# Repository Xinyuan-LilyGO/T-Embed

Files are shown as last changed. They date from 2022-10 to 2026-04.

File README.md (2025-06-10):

<h1 align = "center">🌟LilyGo T-Embed🌟</h1>



## News

- **CC1101 Shield Description**
  - If a CC1101 shield is added to the Embed, the microphone will not be enabled. This is determined by the hardware design and cannot be avoided.

# Introduce

An ESP32S3 development board that can freely use WIFI, BLE, TF, LED, TFT_LCD functions.

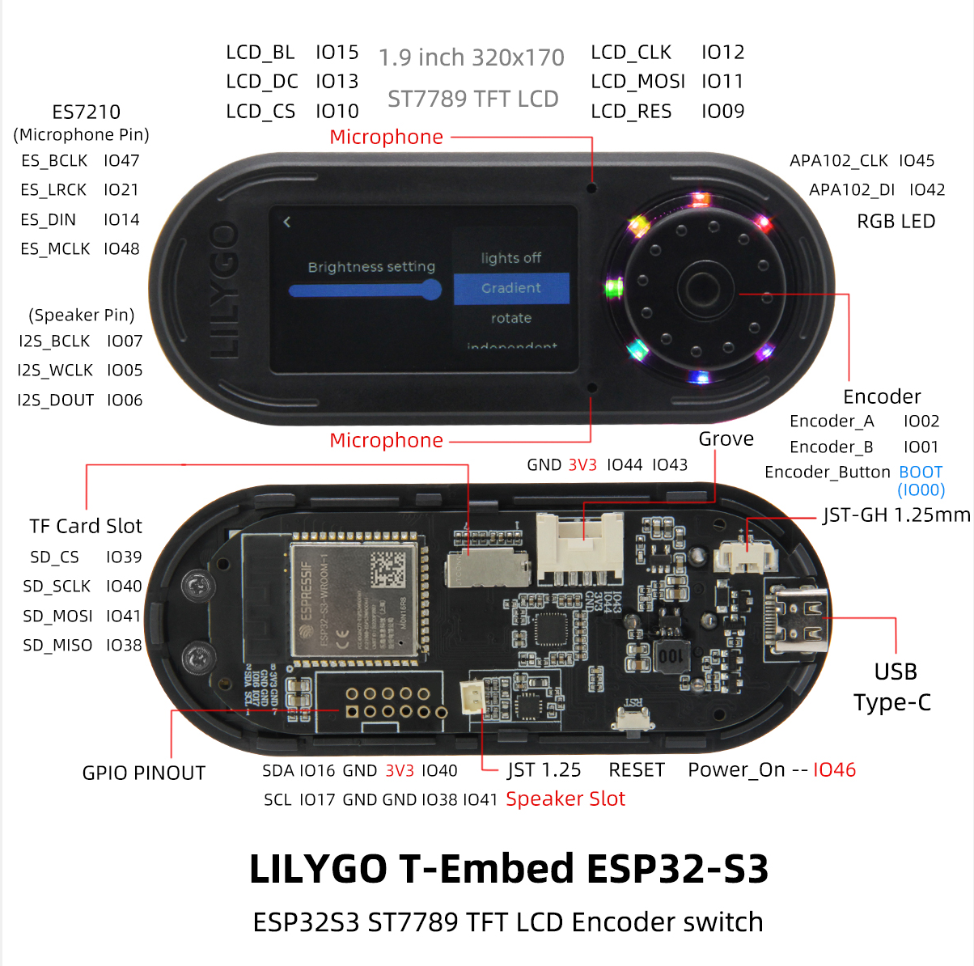
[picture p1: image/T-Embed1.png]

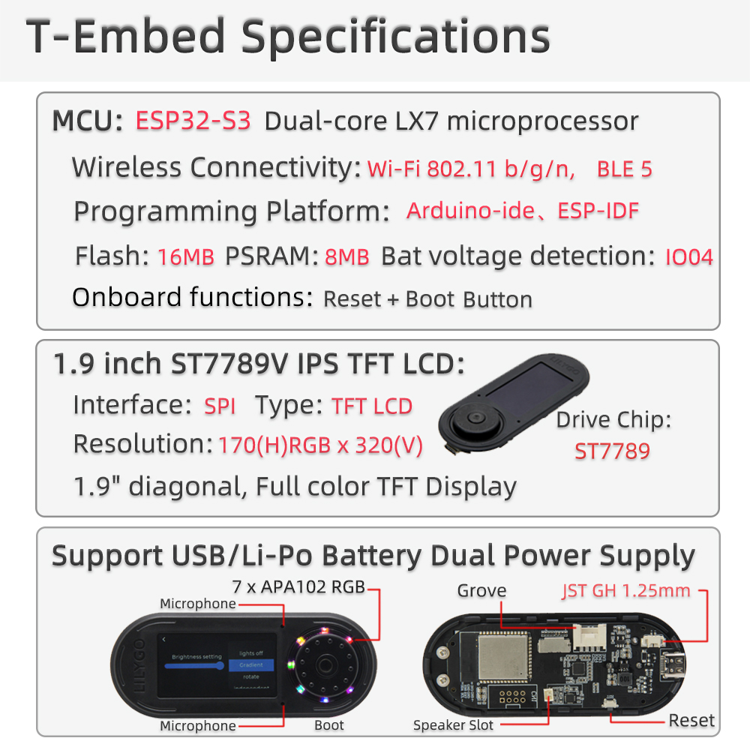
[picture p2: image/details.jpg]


## Product 📷

| Product |  Product Link  |
| :-----: | :---: |
| T-Embed | [LilyGo](https://www.lilygo.cc/products/t-embed) |

# Quick Start
## Arduino 
> Arduino:
> In Arduino Preferences, on the Settings tab, enter the `https://raw.githubusercontent.com/espressif/arduino-esp32/gh-pages/package_esp32_index.json` URL in the `Additional boards manager URLs` input box. **Please pay attention to the version. The test phase is using 2.0.14. It is not certain that versions above 2.0.14 can run. When the operation is abnormal, please downgrade to a version below 2.0.14.** , As of 2024/08/02, TFT_eSPI does not work on versions higher than 2.0.14, see [TFT_eSPI/issue3329](https://github.com/Bodmer/TFT_eSPI/issues/3329)
>- Search for ESP32 in Tools->Board Manager and install ESP32-Arduino SDK
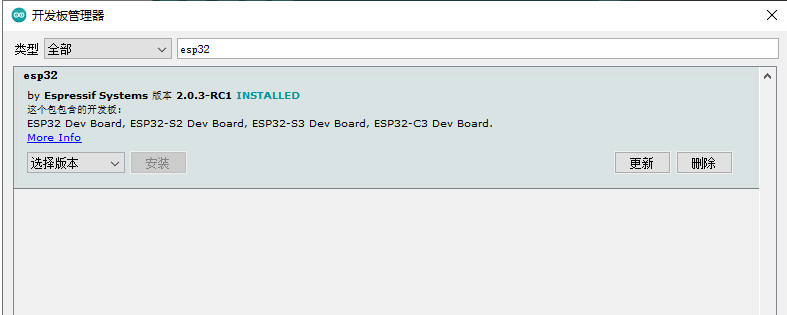
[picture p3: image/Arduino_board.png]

>- Copy all files in the lib folder to `\Arduino\libraries`
>- Select the settings as shown. Note that the FLASH size partition and size may be modified depending on the board.
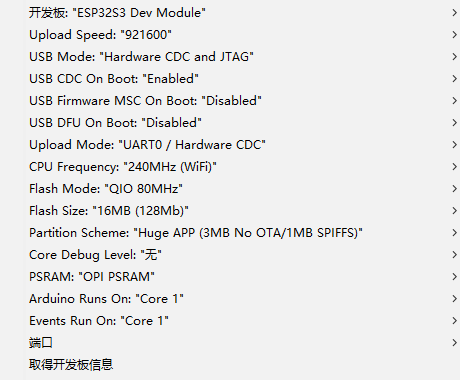
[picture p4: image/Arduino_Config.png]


> PlatfromIO:
> - PlatformIO plug-in installation: Click on the extension on the left column -> search platformIO -> install the first plug-in
> - Click Platforms -> Embedded -> search Espressif 32 in the input box -> select the corresponding firmware installation

> ESP-IDF:
> - The installation method is also inconsistent depending on the system, it is recommended to refer to the [official manual](https://docs.espressif.com/projects/esp-idf/en/latest/esp32/get-started/index.html) for installation

## Precautions for factory example:
1. You need to use the [esp32fs plugin](https://github.com/me-no-dev/arduino-esp32fs-plugin/issues) . The `Arduino 2.x` version does not support the `esp32fs plugin`. Please use `Arduino 1.18.x` to upload resource files.Please refer to the plugin homepage for specific installation and usage methods
2. Please use <Arduino IDE 2.x> during compilation. Please refer to the following figure for specific options
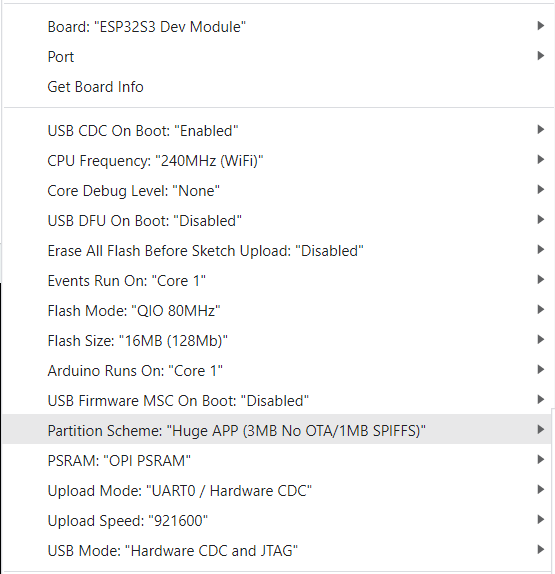
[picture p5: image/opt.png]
    
3. The Arduino IDE prompts whether to update the library. Please do not click Upgrade, otherwise the configuration file of [TFT_ESPI] will be overwritten.

## Tips

1. The program can be written normally, but there is still no display after writing
    1. There are factory test files in the firmware folder, which can be flashed into the board to check whether the board is normal. If there is still no display, then it can be judged that there is a problem with the board or the screen
    2. Delete the <TFT_eSPI> in the libraries, and replace the <TFT_eSPI> in the <lib> folder of the main page to the libraries directory
    3. When opening the Arduino IDE, it prompts whether to upgrade the library, please choose not to upgrade, otherwise it will overwrite the configuration of the <TFT_eSPI> display

2. The board uses USB as the JTAG upload port. When printing serial port information on USB_CDC_ON_BOOT configuration needs to be turned on.
If the port cannot be found when uploading the program or the USB has been used for other functions, the port does not appear.
Please enter the upload mode manually.
   1. Connect the board via the USB cable
   2. Press and hold the BOOT(In the middle of the rotary encoder) button , While still pressing the BOOT button, press RST
   3. Release the RST
   4. Release the BOOT button
   5. Upload sketch

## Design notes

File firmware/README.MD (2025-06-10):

When you suspect that there is a problem with the hardware, you can brush in our test firmware

1. Enter boot mode

   1. Connect the board via the USB cable
   2. Press and hold the BOOT(In the middle of the rotary encoder) button , While still pressing the BOOT button, press RST
   3. Release the RST
   4. Release the BOOT button
   5. Upload sketch

2. Download [Flash_download_tool](https://docs.espressif.com/projects/esp-test-tools/en/latest/esp32/production_stage/tools/flash_download_tool.html)
   
3. Select esp32s3,USB

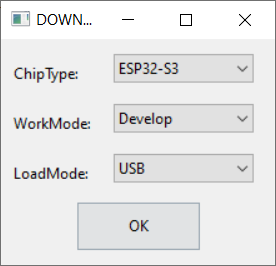
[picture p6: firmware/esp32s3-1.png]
    

4. Select according to the following figure, finally select START, press RST after writing, or power on again, and then observe the log output from the serial port

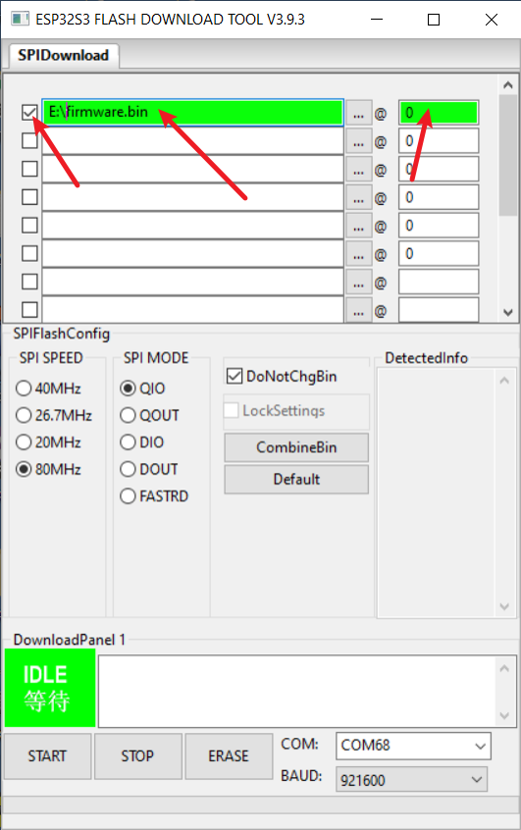
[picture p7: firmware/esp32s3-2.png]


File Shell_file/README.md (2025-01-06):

## PVC Customized(定制)
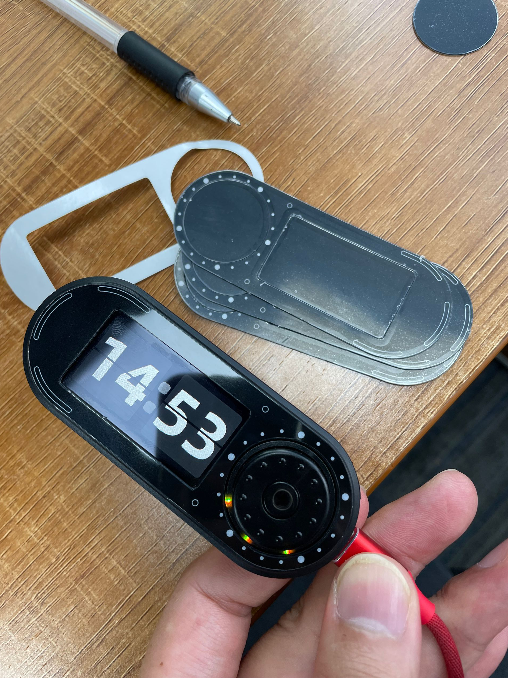
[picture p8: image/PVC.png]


## Normal-Shell

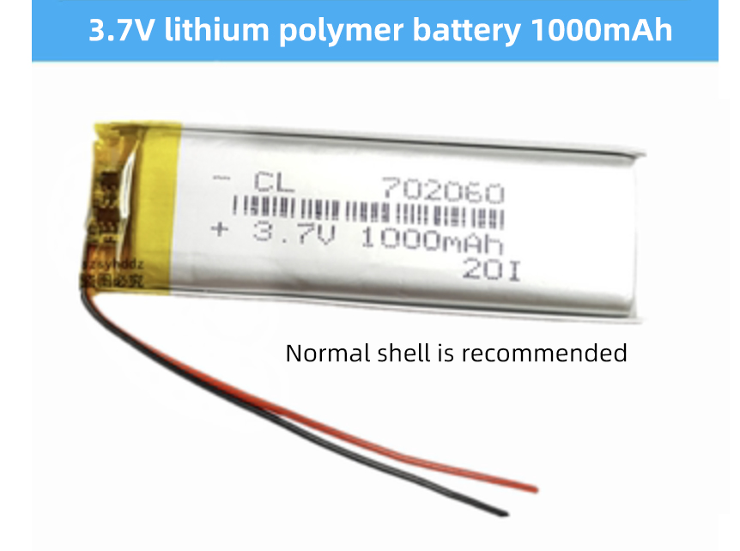
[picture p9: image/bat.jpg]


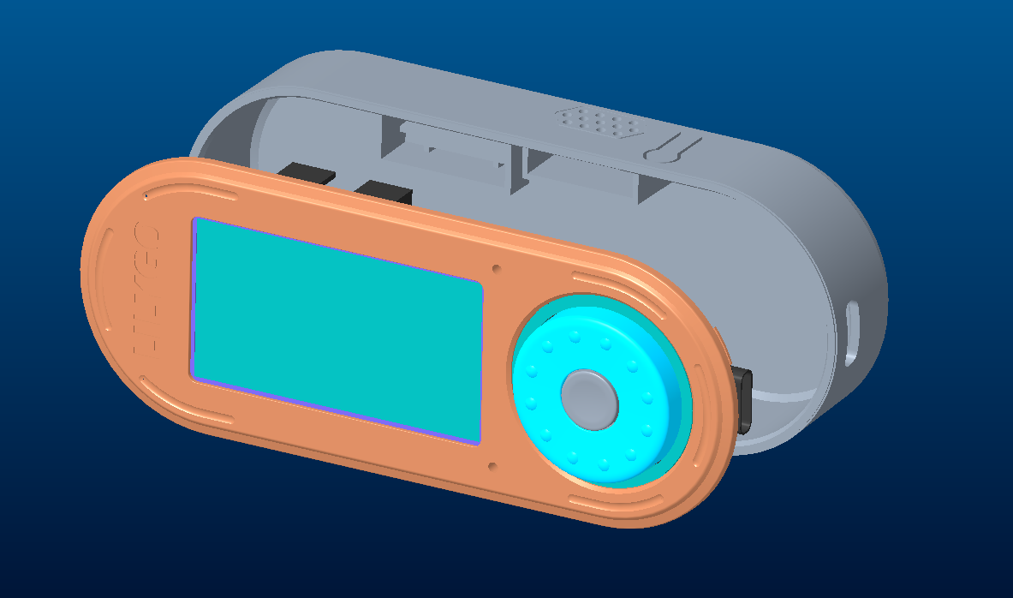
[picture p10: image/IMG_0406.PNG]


## Big-Shell

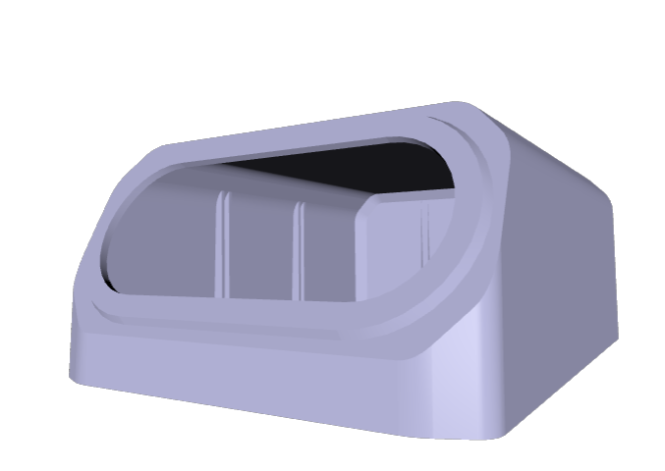
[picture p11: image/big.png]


## t-embed_normal-shell

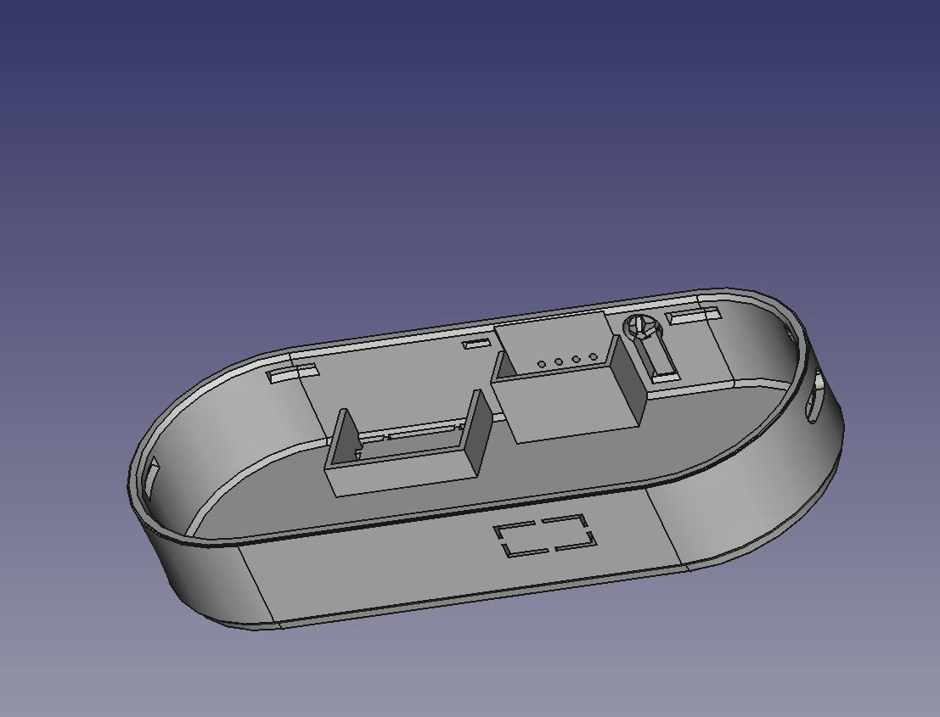
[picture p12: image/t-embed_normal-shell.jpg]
t-embed_normal-shell


## t-embed_bottom

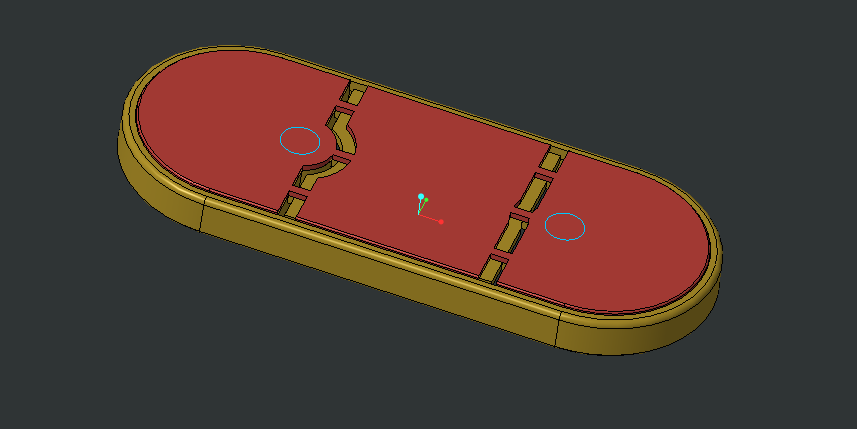
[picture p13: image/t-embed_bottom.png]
t-embed_bottom.stp


## t-embed_normal-full-shell

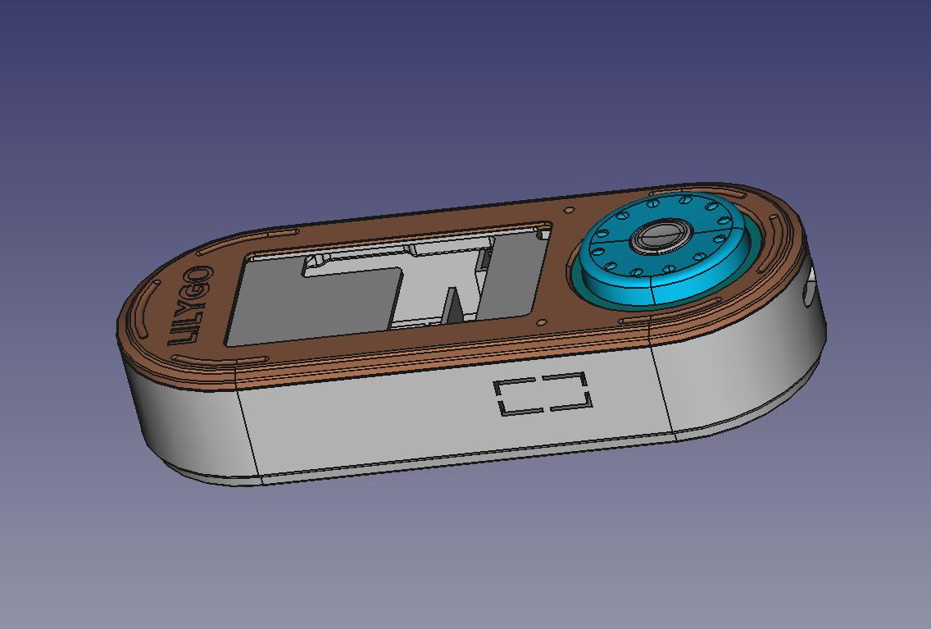
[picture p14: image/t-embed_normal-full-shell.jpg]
t-embed_normal-full-shell


## 0-00_59.stl

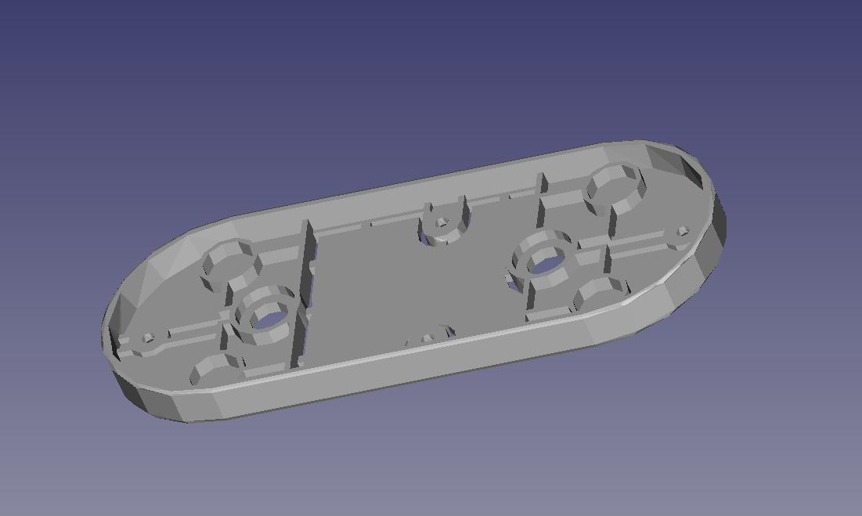
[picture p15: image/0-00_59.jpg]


## 066_t-embed_cov-a5_3_20.stl

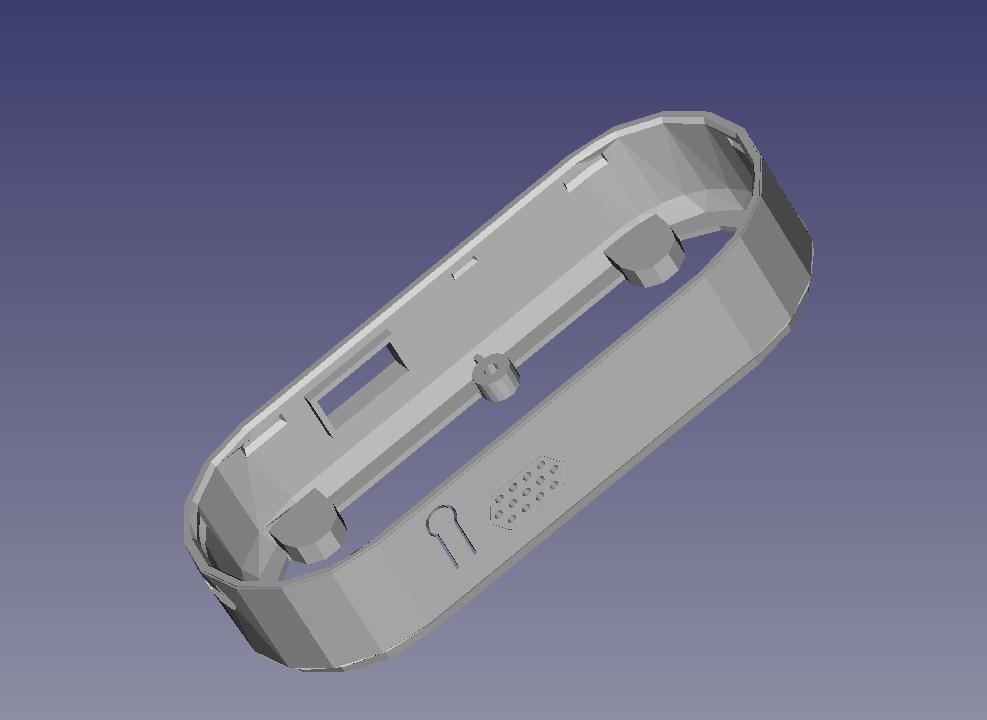
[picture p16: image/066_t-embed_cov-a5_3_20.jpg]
066_t-embed_cov-a5_3_20.stl


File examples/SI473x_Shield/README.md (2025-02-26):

# ESP32 OLED_ALL_IN_ONE sketch from PU2CLR ported to the Lilygo T-Display S3.

This is a porting of [ESP32 OLED_ALL_IN_ONE](https://github.com/pu2clr/SI4735/tree/master/examples/SI47XX_06_ESP32/OLED_ALL_IN_ONE) sketch from [PU2CLR (Ricardo Caratti)](https://github.com/pu2clr/SI4735) using the clean and beatiful [Volos interface](https://github.com/VolosR/TEmbedFMRadio).

I am using a [Lilygo T-Display S3](https://github.com/Xinyuan-LilyGO/T-Display-S3), which is an ESP32S3 board with a 1.9 inch display with a 8-Bit Parallel Interface, but I believe it will also run on [Lilygo T-Embed](https://github.com/Xinyuan-LilyGO/T-Embed) with some minor changes.

# Special instructions for the TFT_eSPI Library

It is extremely important to follow all the steps indicated on Lilygo github:

[Lilygo T-Display S3] (https://github.com/Xinyuan-LilyGO/T-Display-S3#quick-start)

[Lilygo T-Embed] (https://github.com/Xinyuan-LilyGO/T-Embed#quick-start)

# Releases

## [V0.1 - Initial Release]

First release.

    This release implements different behaviors for its single button.
        
        - Rotary encoder:   Normal mode: Change Frequency. Menu Mode: Select and change options
        - Single press:     Change band. Another single press to return to the "frequency mode"
        - Double press:     Menu mode. Turn the rotary encoder to select the desired option and press the button again to select it.

# Component Parts

* Si4732
* [Lilygo T-Display S3](https://github.com/Xinyuan-LilyGO/T-Display-S3)
* Rotary encoder with switch
* External Speaker (I use an old external Spearker)
* External Battery Pack
* Resistors/Capacitors/Wires

# Schematics:

* Si4735
Not avaliable yet

* Si4732
Si4732

# Videos:

* https://youtu.be/cxb8L1xAmmo

# Pictures:

## Version V0.1

Si4732

# References

1. [PU2CLR SI4735 Library for Arduino](https://github.com/pu2clr/SI4735)

2. [Volos Projects](https://github.com/VolosR/TEmbedFMRadio)

3. [Lilygo T-Display S3](https://github.com/Xinyuan-LilyGO/T-Display-S3)

4. [Lilygo T-Embed](https://github.com/Xinyuan-LilyGO/T-Embed)

# DISCLAMER

ATTENTION: The author of this project does not guarantee that procedures shown here will work in your development environment.
Given this, it is at your own risk to continue with the procedures suggested here.

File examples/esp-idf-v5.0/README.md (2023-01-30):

# Example of how to use the T-Embed with ESP-IDF V5.0

## Supported Peripherals

This example shows:

1. LCD with LVGL
2. Dial knob with push button (shows up in monitor output)
3. LED strip around the dial

## Prerequisites

1. A T-Embed (preferably working)
2. An installation of the ESP-IDF V5.0 including ESP32S3 target
3. This repository
4. A working USB data and power cable

## Getting Started

0. Plug in your T-Embed. Make sure it is recognized by the OS (I recommend linux)
1. Clone the ESP-IDF repository V5.0 branch
   `git clone --depth=1 --recursive -b v5.0 https://github.com/espressif/esp-idf.git`
2. Run the `install.sh` in the ESP-IDF repo root `install.sh all`
3. Export the ESP-IDF config into the shell `. ./export.sh`
4. Check the IDF version `idf.py --version` (should be v5.0)
5. Clone this repo
6. Change to the `example/esp-idf-v5.0` dir
7. `idf.py flash && idf.py monitor`

## Expected output

```
ESP-ROM:esp32s3-20210327
Build:Mar 27 2021
rst:0x15 (USB_UART_CHIP_RESET),boot:0xb (SPI_FAST_FLASH_BOOT)
Saved PC:0x40048d17
SPIWP:0xee
mode:DIO, clock div:1
load:0x3fce3810,len:0x17d8
load:0x403c9700,len:0xe88
load:0x403cc700,len:0x3000
SHA-256 comparison failed:
Calculated: 3c4dc30344ef58d708ed5cb5d936eee67c311244cdd3e6b9576b61d747836d66
Expected: ffffffffffffffffffffffffffffffffffffffffffffffffffffffffffffffff
Attempting to boot anyway...
entry 0x403c9930
I (43) boot: ESP-IDF v5.0 2nd stage bootloader
I (43) boot: compile time 14:09:47
I (43) boot: chip revision: v0.1
I (45) boot_comm: chip revision: 1, min. bootloader chip revision: 0
I (52) qio_mode: Enabling default flash chip QIO
I (57) boot.esp32s3: Boot SPI Speed : 80MHz
I (62) boot.esp32s3: SPI Mode       : QIO
I (66) boot.esp32s3: SPI Flash Size : 16MB
I (71) boot: Enabling RNG early entropy source...
I (77) boot: Partition Table:
I (80) boot: ## Label            Usage          Type ST Offset   Length
I (88) boot:  0 nvs              WiFi data        01 02 00009000 00006000
I (95) boot:  1 phy_init         RF data          01 01 0000f000 00001000
I (103) boot:  2 factory          factory app      00 00 00010000 00177000
I (110) boot: End of partition table
I (114) boot_comm: chip revision: 1, min. application chip revision: 0
I (122) esp_image: segment 0: paddr=00010020 vaddr=3c060020 size=2da1ch (186908) map
I (149) esp_image: segment 1: paddr=0003da44 vaddr=3fc94900 size=025d4h (  9684) load
I (151) esp_image: segment 2: paddr=00040020 vaddr=42000020 size=521ach (336300) map
I (189) esp_image: segment 3: paddr=000921d4 vaddr=3fc96ed4 size=00f74h (  3956) load
I (190) esp_image: segment 4: paddr=00093150 vaddr=40374000 size=108e8h ( 67816) load
I (205) esp_image: segment 5: paddr=000a3a40 vaddr=50000000 size=00010h (    16) load
I (212) boot: Loaded app from partition at offset 0x10000
I (212) boot: Disabling RNG early entropy source...
I (227) octal_psram: ECC is enabled
I (227) octal_psram: vendor id    : 0x0d (AP)
I (227) octal_psram: dev id       : 0x02 (generation 3)
I (231) octal_psram: density      : 0x03 (64 Mbit)
I (236) octal_psram: good-die     : 0x01 (Pass)
I (241) octal_psram: Latency      : 0x01 (Fixed)
I (247) octal_psram: VCC          : 0x01 (3V)
I (252) octal_psram: SRF          : 0x01 (Fast Refresh)
I (257) octal_psram: BurstType    : 0x00 ( Wrap)
I (263) octal_psram: BurstLen     : 0x03 (1024 Byte)
I (268) octal_psram: Readlatency  : 0x02 (10 cycles@Fixed)
I (275) octal_psram: DriveStrength: 0x00 (1/1)
W (280) PSRAM: DO NOT USE FOR MASS PRODUCTION! Timing parameters will be updated in future IDF version.
I (290) esp_psram: Found 8MB PSRAM device
I (294) esp_psram: Speed: 80MHz
I (330) mmu_psram: Instructions copied and mapped to SPIRAM
I (345) mmu_psram: Read only data copied and mapped to SPIRAM
I (345) cpu_start: Pro cpu up.
I (345) cpu_start: Starting app cpu, entry point is 0x40375678
0x40375678: call_start_cpu1 at cpu_start.c:142

I (0) cpu_start: App cpu up.
I (737) esp_psram: SPI SRAM memory test OK
I (746) cpu_start: Pro cpu start user code
I (746) cpu_start: cpu freq: 240000000 Hz
I (746) cpu_start: Application information:
I (749) cpu_start: Project name:     esp_idf_v5.0_tembed
I (755) cpu_start: App version:      654a010-dirty
I (761) cpu_start: Compile time:     Jan 16 2023 15:53:20
I (767) cpu_start: ELF file SHA256:  4f84fc36fdb69bfc...
I (773) cpu_start: ESP-IDF:          v5.0
I (777) heap_init: Initializing. RAM available for dynamic allocation:
I (785) heap_init: At 3FCA0F60 len 000487B0 (289 KiB): D/IRAM
I (791) heap_init: At 3FCE9710 len 00005724 (21 KiB): STACK/DRAM
I (798) heap_init: At 3FCF0000 len 00008000 (32 KiB): DRAM
I (804) heap_init: At 600FE010 len 00001FF0 (7 KiB): RTCRAM
I (810) esp_psram: Adding pool of 7104K of PSRAM memory to heap allocator
I (818) spi_flash: detected chip: gd
I (822) spi_flash: flash io: qio
I (826) cpu_start: Starting scheduler on PRO CPU.
I (0) cpu_start: Starting scheduler on APP CPU.
I (846) esp_psram: Reserving pool of 32K of internal memory for DMA/internal allocations
I (846) hello_lcd: Hello lcd!
This is esp32s3 chip with 2 CPU core(s), WiFi/BLE, silicon revision v0.1, 16MB external flash
Minimum free heap size: 7570560 bytes
I (866) gpio: GPIO[46]| InputEn: 0| OutputEn: 1| OpenDrain: 0| Pullup: 0| Pulldown: 0| Intr:0
I (876) gpio: GPIO[0]| InputEn: 0| OutputEn: 1| OpenDrain: 0| Pullup: 0| Pulldown: 0| Intr:0
I (886) gpio: GPIO[0]| InputEn: 0| OutputEn: 1| OpenDrain: 0| Pullup: 0| Pulldown: 0| Intr:0
I (896) lcd: Backlight off
I (896) gpio: GPIO[15]| InputEn: 0| OutputEn: 1| OpenDrain: 0| Pullup: 0| Pulldown: 0| Intr:0
I (906) lcd: Init SPI bus
I (906) lcd: Init panel io
I (916) gpio: GPIO[13]| InputEn: 0| OutputEn: 1| OpenDrain: 0| Pullup: 0| Pulldown: 0| Intr:0
I (926) lcd: Attach panel
I (926) gpio: GPIO[9]| InputEn: 0| OutputEn: 1| OpenDrain: 0| Pullup: 0| Pulldown: 0| Intr:0
I (936) lcd: Init lcd
I (2056) lcd: Enable lcd
I (2056) lcd: Backlight on
I (2056) gpio: GPIO[0]| InputEn: 1| OutputEn: 0| OpenDrain: 0| Pullup: 1| Pulldown: 0| Intr:0
I (2056) gpio: GPIO[2]| InputEn: 1| OutputEn: 0| OpenDrain: 0| Pullup: 1| Pulldown: 0| Intr:3
I (2066) gpio: GPIO[1]| InputEn: 1| OutputEn: 0| OpenDrain: 0| Pullup: 1| Pulldown: 0| Intr:3
I (2076) Knob: Iot Knob Config Succeed, encoder A:2, encoder B:1, direction:0, Version: 0.1.0
I (2086) gpio: GPIO[0]| InputEn: 0| OutputEn: 1| OpenDrain: 0| Pullup: 0| Pulldown: 0| Intr:0
I (2096) gpio: GPIO[0]| InputEn: 0| OutputEn: 1| OpenDrain: 0| Pullup: 0| Pulldown: 0| Intr:0
I (2106) gpio: GPIO[0]| InputEn: 0| OutputEn: 1| OpenDrain: 0| Pullup: 0| Pulldown: 0| Intr:0
I (2116) gpio: GPIO[0]| InputEn: 0| OutputEn: 1| OpenDrain: 0| Pullup: 0| Pulldown: 0| Intr:0
I (2126) lvgl: Init
I (2126) lvgl: Register display
I (2126) lvgl: Tick timer
I (2136) hello_lcd: Display LVGL

```

You should see three labels on the screen "RED", "GREEN", "BLUE" in the correct colors

If you turn the dial the number on the bottom of the screen should change

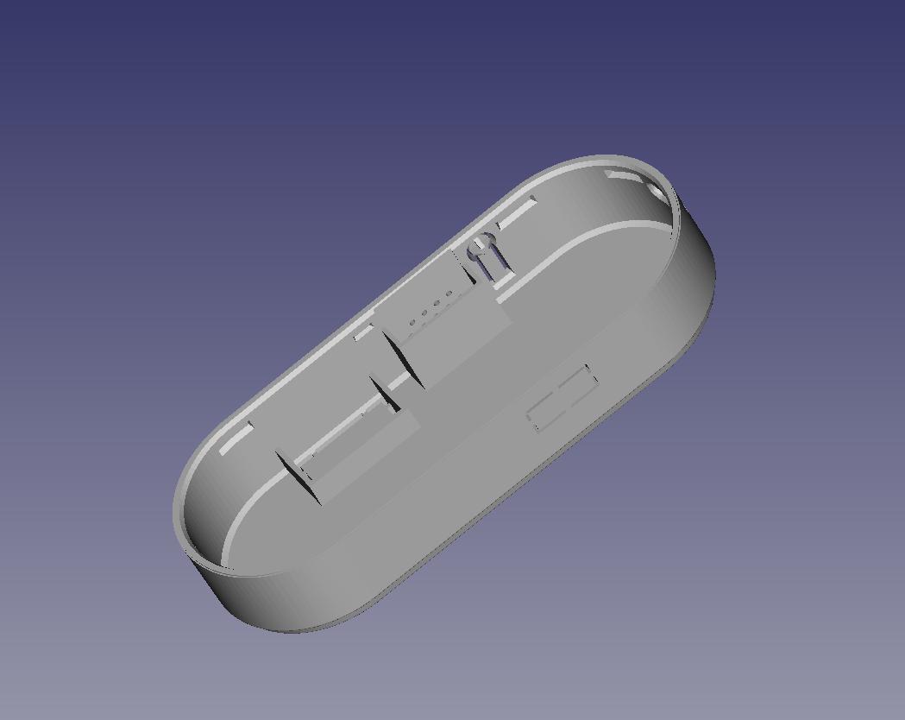
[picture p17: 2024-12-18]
image/t-embed_nomal-shell.jpg

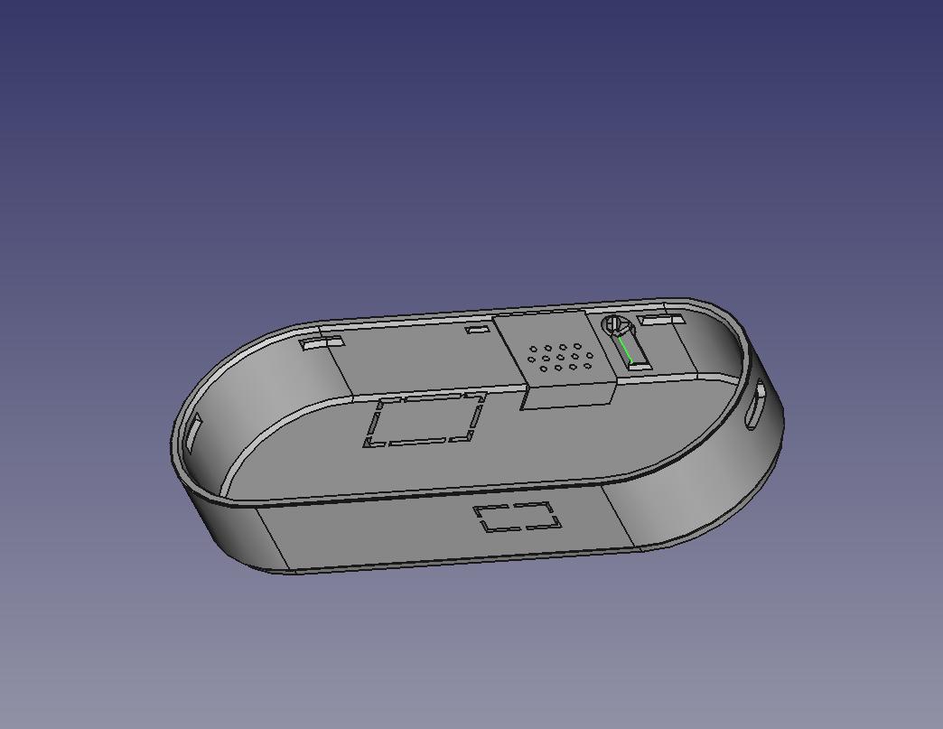
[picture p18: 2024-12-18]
image/t-embed_normal-shell-1204.jpg

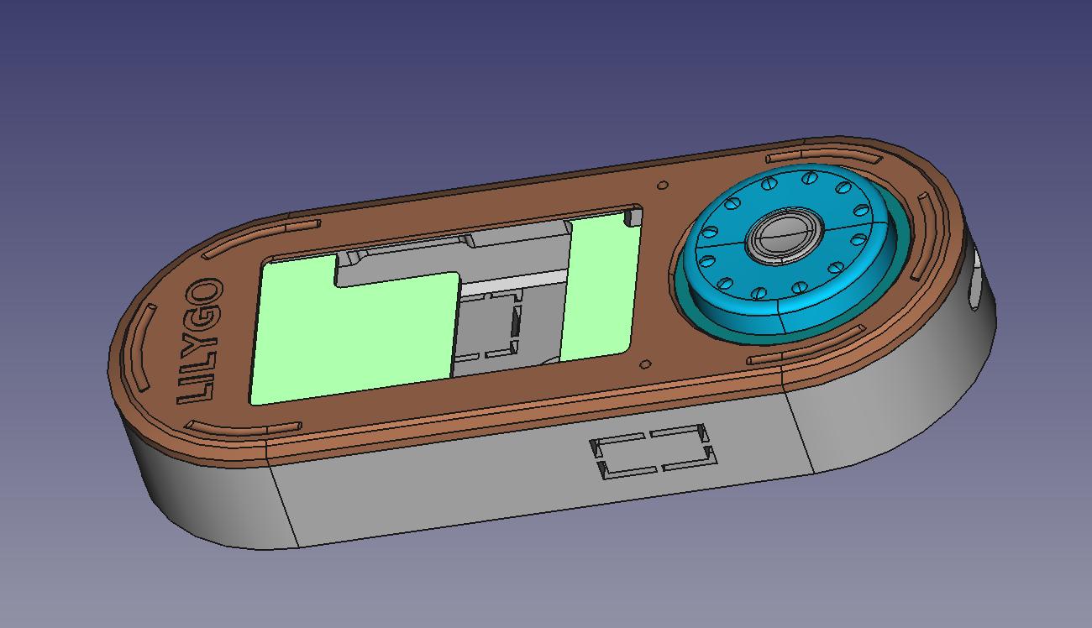
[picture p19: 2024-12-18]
image/t-embed_Thin.jpg

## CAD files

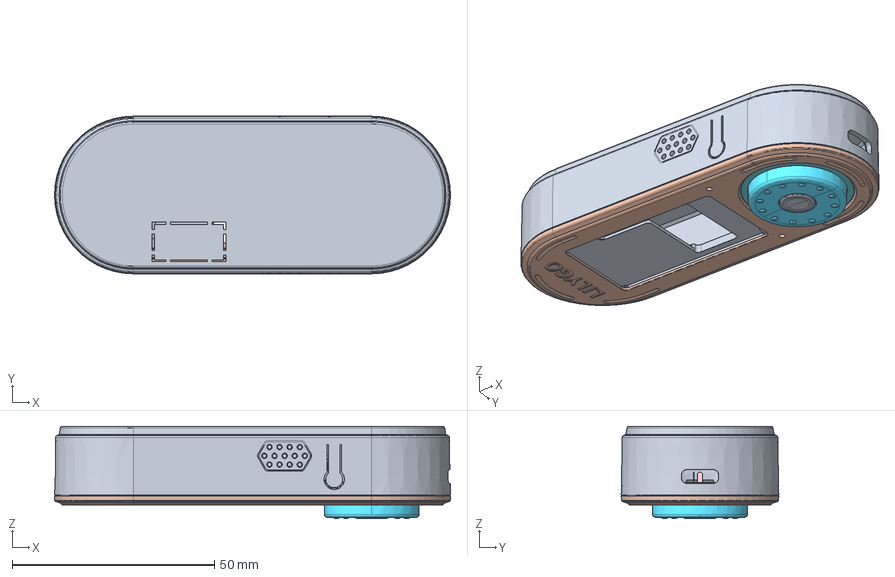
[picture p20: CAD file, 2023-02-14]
Shell_file/t-embed_normal-full-shell.stp
98.0 x 39.0 x 22.9 mm
066_T-EMBED_COV-A5_3
067_T-EMBED_COV-B5_5
068_T-EMBED_COV-C5_1
069_T-EMBED_COV-D5_2
T-ENCODER-PCB00_1
ZIPPY_00_1
T_ENCODER_COV-A2_1
T_ENCODER_COV-B2_1
068_T-EMBED_COV-C5_1_1_2
T-EMBED_COV_4

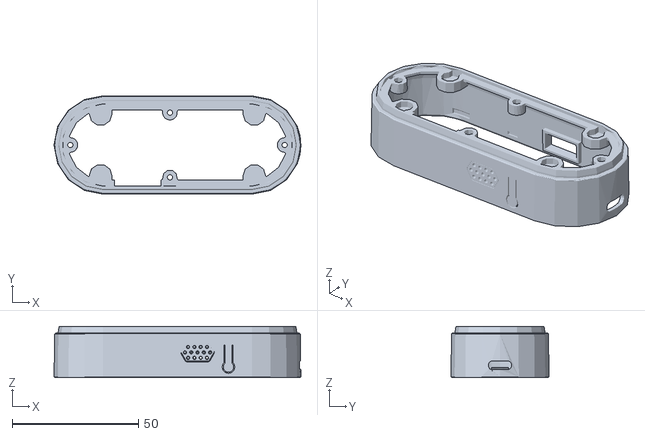
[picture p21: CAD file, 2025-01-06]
Shell_file/066_t-embed_cov-a5_3_20.stl
98.0 x 39.0 x 20.3

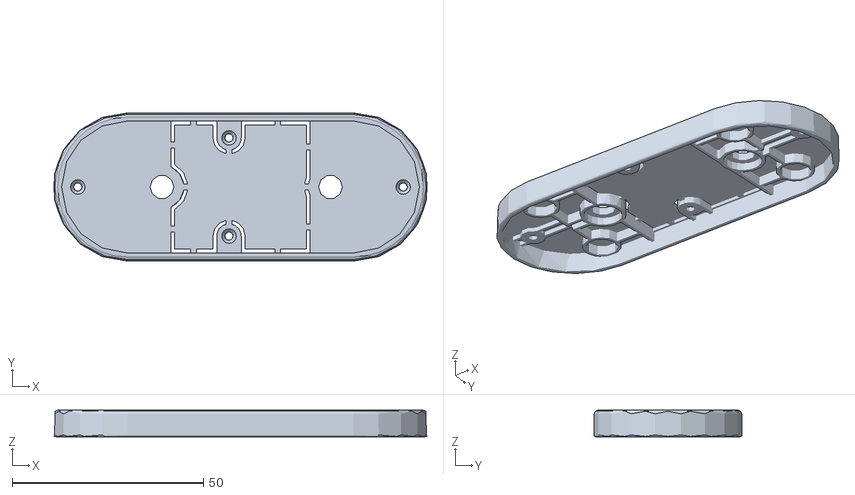
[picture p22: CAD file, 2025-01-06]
Shell_file/0-00_59.stl
97.4 x 38.7 x 7.00

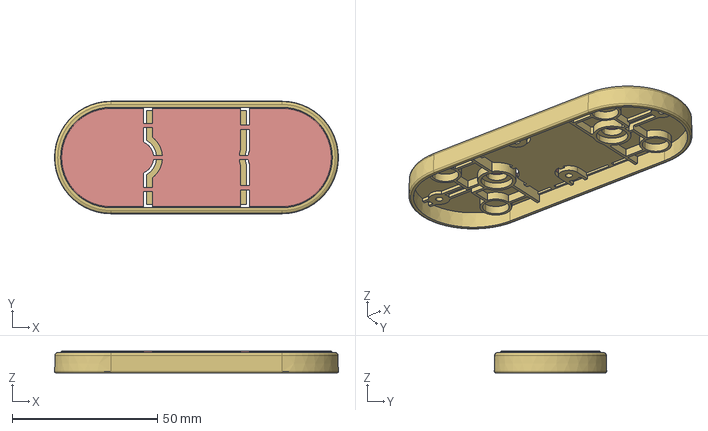
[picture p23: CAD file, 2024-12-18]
Shell_file/t-embed_bottom.stp
97.7 x 38.7 x 7.50 mm

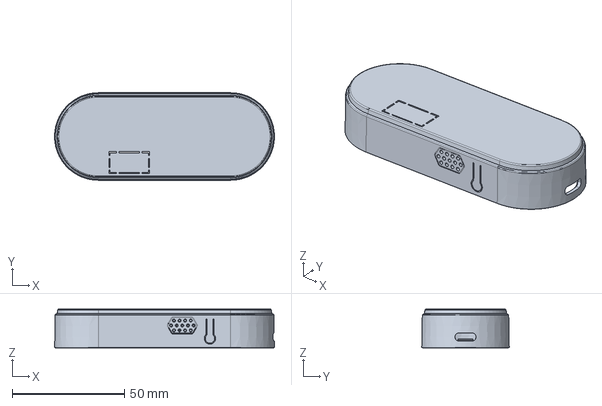
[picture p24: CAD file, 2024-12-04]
Shell_file/t-embed_normal-shell-1204.stp
98.0 x 39.0 x 17.3 mm

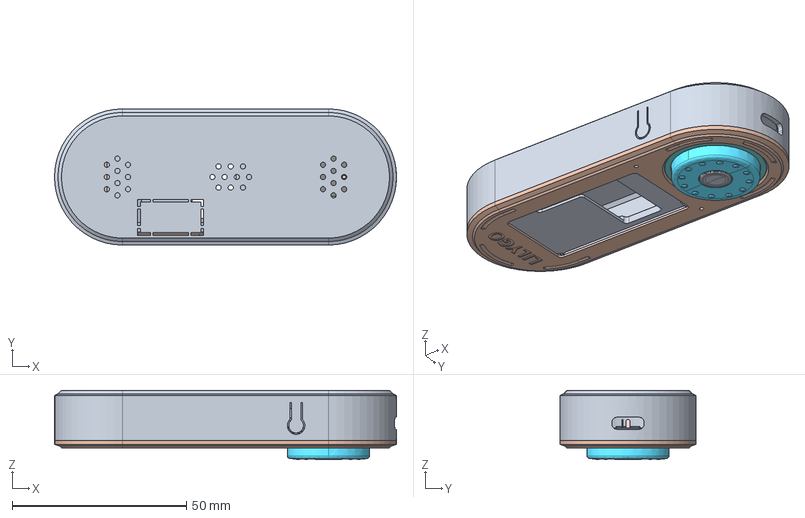
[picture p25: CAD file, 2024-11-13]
Shell_file/t-embed_Thin.stp
98.0 x 39.0 x 19.9 mm
066_T-EMBED_COV-A
067_T-EMBED_COV-B00
068_T-EMBED_COV-C
069_T-EMBED_COV-D00
T-ENCODER-PCB00
ZIPPY_00
T_ENCODER_COV-A2
T_ENCODER_COV-B2

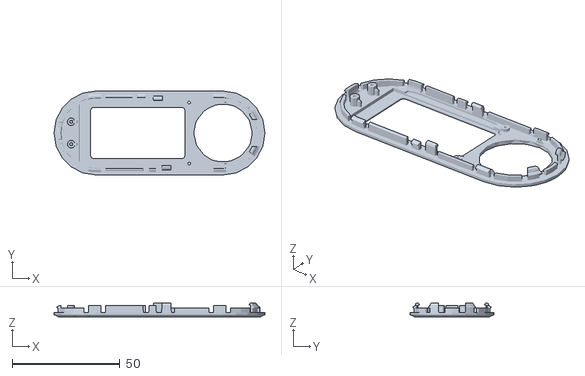
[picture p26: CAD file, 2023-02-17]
Shell_file/front-panel.stl
98.0 x 39.0 x 6.60

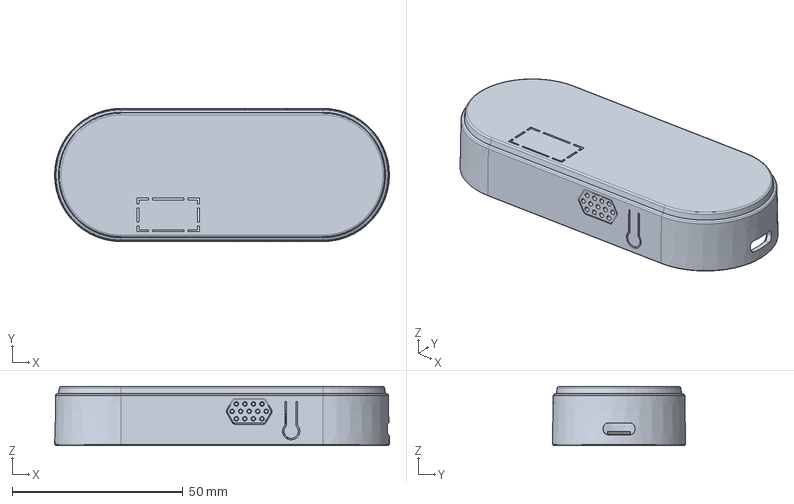
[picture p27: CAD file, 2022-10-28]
Shell_file/t-embed_normal-shell.stp
98.0 x 39.0 x 17.3 mm

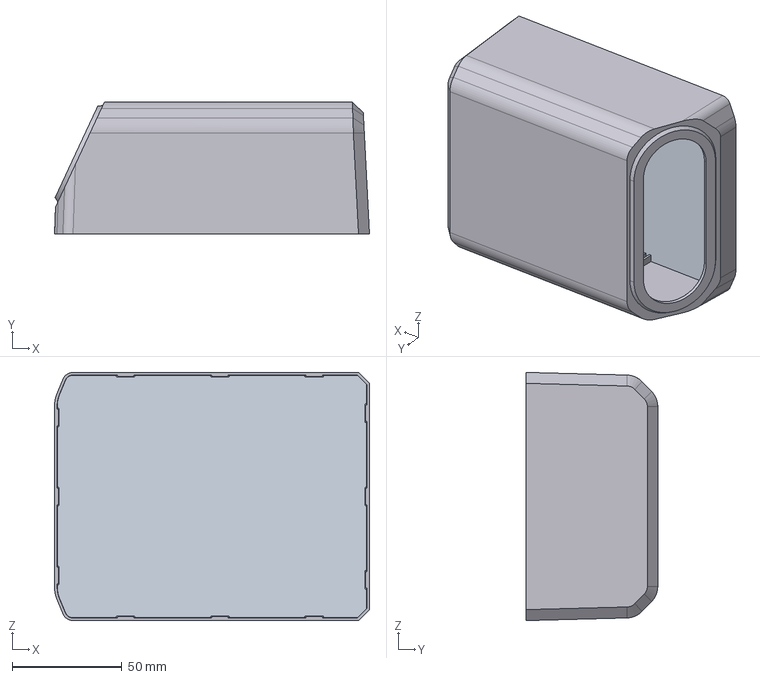
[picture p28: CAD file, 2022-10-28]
Shell_file/t_embed_big-shell.stp
143.6 x 60.0 x 113.1 mm
T_EMBED_BIG-SHELL
T_EMBED_BIG-F

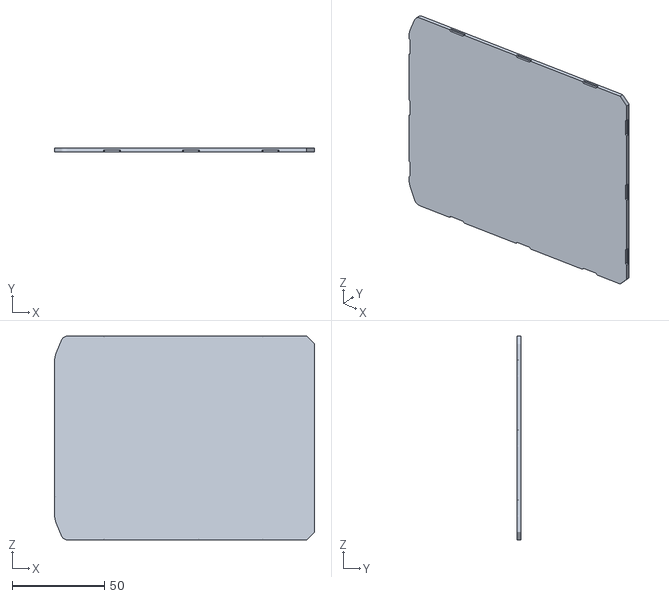
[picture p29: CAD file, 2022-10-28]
Shell_file/t_embed_big-shell-f.stl
141.0 x 2.10 x 110.5

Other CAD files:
Shell_file/PVC_Board.dwg
Shell_file/t_embed_shell.dwg
Shell_file/t-embed_normal-shell.stl
Shell_file/t_embed_big-shell.stl

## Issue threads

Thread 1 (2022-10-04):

Is USB-C connected to ESP32-S3 USB OTG?

drudru, 2022-10-04:
Hi,

I could not find any information about this on your sites.

Is the ESP32-S3 USB OTG connected to the USB-C connector?

LilyGO, 2022-10-06:
Yes it can. In some older implementations, USB-C may cause the motherboard to not supply power due to a flaw in the design. It has been gradually fixed in the new design.

morganrallen, 2022-11-22:
@LilyGO are there any board markings to indicate the version?

Closed 2022-10-26.

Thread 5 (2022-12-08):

Unable to find correct settings for TFT_eSPI for this T-Embed display

Gun-neR, 2022-12-08:
I have loaded the files into my Library as per this pages instructions (I am using a portable IDE so as to not mess up my other displays that use same library), but the User_Setup.h file appears to be incorrect for this display's SPI interface.  I have tried many adjustments but still unable to get anything to display.  At most I have only gotten the backlight to turn on.

What is the correct User_Setup.h for this T-Embed display?

mmMicky, 2022-12-08:
https://github.com/Xinyuan-LilyGO/T-Embed/blob/main/lib/TFT_eSPI/User_Setups/Setup24_ST7789.h

I used this configuration. I did not create a new Setupxxx.h.

Gun-neR, 2022-12-08:
I did see those options, but have no idea how to chose that file instead.  Even takeing those port numbers and using those in the User_Setup.h doesn't seem to work.   Frusteratingm, as I have been able to get the T-Display runing just fine via that file.

Gun-neR, 2022-12-08:
This is what I have in my User_Setup.h   No idea what it doesnt seem to work.

```
//                            USER DEFINED SETTINGS

#define USER_SETUP_INFO "User_Setup"
#define ST7789_DRIVER      // Full configuration option, define additional parameters below for this display

// For ST7735, ST7789 and ILI9341 ONLY, define the colour order IF the blue and red are swapped on your display
// Try ONE option at a time to find the correct colour order for your display
//  #define TFT_RGB_ORDER TFT_RGB  // Colour order Red-Green-Blue
#define TFT_RGB_ORDER TFT_BGR  // Colour order Blue-Green-Red

// For ST7789, ST7735, ILI9163 and GC9A01 ONLY, define the pixel width and height in portrait orientation
#define TFT_WIDTH  170 // ST7789 172 x 320
#define TFT_HEIGHT 320 // ST7789 240 x 320

// For ESP32 Dev board (only tested with GC9A01 display)
// The hardware SPI can be mapped to any pins
#define TFT_MOSI 11 // In some display driver board, it might be written as "SDA" and so on.
#define TFT_SCLK 12
#define TFT_CS   10  // Chip select control pin
#define TFT_DC   13  // Data Command control pin
#define TFT_RST  9  // Reset pin (could connect to Arduino RESET pin)
#define TFT_BL   16  // LED back-light

// ##################################################################################
//
// Section 3. Define the fonts that are to be used here
//
// ##################################################################################
// Comment out the #defines below with // to stop that font being loaded
// The ESP8366 and ESP32 have plenty of memory so commenting out fonts is not
// normally necessary. If all fonts are loaded the extra FLASH space required is
// about 17Kbytes. To save FLASH space only enable the fonts you need!
#define LOAD_GLCD   // Font 1. Original Adafruit 8 pixel font needs ~1820 bytes in FLASH
#define LOAD_FONT2  // Font 2. Small 16 pixel high font, needs ~3534 bytes in FLASH, 96 characters
#define LOAD_FONT4  // Font 4. Medium 26 pixel high font, needs ~5848 bytes in FLASH, 96 characters
#define LOAD_FONT6  // Font 6. Large 48 pixel font, needs ~2666 bytes in FLASH, only characters 1234567890:-.apm
#define LOAD_FONT7  // Font 7. 7 segment 48 pixel font, needs ~2438 bytes in FLASH, only characters 1234567890:-.
#define LOAD_FONT8  // Font 8. Large 75 pixel font needs ~3256 bytes in FLASH, only characters 1234567890:-.
//#define LOAD_FONT8N // Font 8. Alternative to Font 8 above, slightly narrower, so 3 digits fit a 160 pixel TFT
#define LOAD_GFXFF  // FreeFonts. Include access to the 48 Adafruit_GFX free fonts FF1 to FF48 and custom fonts

// Comment out the #define below to stop the SPIFFS filing system and smooth font code being loaded
// this will save ~20kbytes of FLASH
#define SMOOTH_FONT

// ##################################################################################
//
// Section 4. Other options
//
// ##################################################################################
// Define the SPI clock frequency, this affects the graphics rendering speed. Too
// fast and the TFT driver will not keep up and display corruption appears.
// With an ILI9341 display 40MHz works OK, 80MHz sometimes fails
// With a ST7735 display more than 27MHz may not work (spurious pixels and lines)
// With an ILI9163 display 27 MHz works OK.
#define SPI_FREQUENCY  20000000
#define SPI_READ_FREQUENCY  2000000
```

mmMicky, 2022-12-09:
The role of this file is to define your lcd pin definitions. You can modify it. Modify it to match my definition.

Gun-neR, 2022-12-09:
I know how the file works :)  I just don't like its complexity.  And even after trying all sorts of GPIO combinations and SPI frequencys, the best I could do with the display was enable/disable the back-light ;P

Even using an Adafruit display driver didn't work... although with that it at least showed a brief flash of scrambled "screen garbage" every once in awhile.

If I hadn't at lest seen the initial demo I would be thinking that it is a faulty device (and it still might be??)  Anyhow, I think this latest acquisition of mine from LILYGO is LILYbound for the bin or a dark corner of a drawer until there is more matured info/examples to test with, perhaps using Python or something, and/or I feel like being frustrated for another 2+ days straight by a silly MCU :D

mmMicky, 2022-12-09:
If you don't like modification. I have provided already modified TFT_eSPI library file, why not use it.
I use the platformIO tool in the build factory. I recommend using it.

Gun-neR, 2022-12-09:
As I already inferred, I tried your data, my data, others data... still didn't work, nor did a totally different library.  And I don't like or use PlatformIO :)

As I only ordered the single one of this T-Embed, I can only assume it is either a faulty device or I am missing some small un/poorly documented detail...  Ie. The instructions and settings that come with this library infer 8bit parallel but document claims SPI... tried both.

I have tested all other aspects of the device, except the mic.  So far only the display is not working, which basically renders the whole thing as useless for the time being.   I will set it aside for now.

Gun-neR, 2022-12-10:
OK, thank you for the pin-out info, if not for the lack of clarification that your version of the Setup24_ST7789.h file WASN'T the same as the "official" one in the actual library (Hint - Clarity means everything in a good answer ;P )  But once I realized the discrepancy and edited the original Setup24_ST7789.h file to match your "custom" version of it, everything worked.

Strange that it wouldn't work with those same pin-outs and freq in my custom User_Setup.h file??  Probably something else in that convoluted library was messing up my attempts.

And no idea why Adafruits example only showed glitching... I suspect there is something different in the way the T-Embed hooks up to that LCD, and my figuring out that one is for another day and not relevant for this topic.

Anyhow. now it is working and so back to my regularly shedualed programming :D

mattoppenheim, 2024-01-04:
My Lilygo T-Embed-S3 remained blank until I added the lines in bold to the TFT_eSPI examples supplied by Lilygo. I build and load these files using the platformio plug-in with VSCode running on Debian.

>**#define PIN_POWER_ON          46**
void setup(void) {
 >>**pinMode(PIN_POWER_ON, OUTPUT);
      digitalWrite(PIN_POWER_ON, HIGH);**
      tft.init();

Closed 2022-12-09.

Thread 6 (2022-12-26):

LCD_BL on README image is wrong

morganrallen, 2022-12-26:
The main image from the README indicates the LCD BackLight is on pin 16, when the schematic shows it on pin 15

mmMicky, 2022-12-27:
Thanks for spotting this, we'll fix this as soon as possible.

Closed 2023-01-30.

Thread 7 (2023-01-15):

PWR_ON pin function is not documented

cydergoth, 2023-01-15:
It turns out to be quite critical to know about when trying to write your own application from scratch!

```
#include "driver/gpio.h"

#define PIN_POWER_ON          46

void app_main(void)
{
    gpio_config_t pw_gpio_config = {
        .mode = GPIO_MODE_OUTPUT,
        .pin_bit_mask = 1ULL << PIN_POWER_ON
    };
    ESP_ERROR_CHECK(gpio_config(&pw_gpio_config));
    gpio_set_level(PIN_POWER_ON, 1);  // <--- LCD won't start without this!

 ....
}
```

cydergoth, 2023-01-15:
Fully working demo with ESP-IDF V5.0 and LVGL 8.3.0 (add it as a dependency with `idf.py add-dependency lvgl/lvgl`)

Uses the `img_logo.h` from the Arduino demo

```
#include <stdio.h>
#include "sdkconfig.h"
#include "freertos/FreeRTOS.h"
#include "freertos/task.h"
#include "esp_chip_info.h"
#include "esp_flash.h"
#include "hal/spi_types.h"
#include "esp_lcd_panel_io.h"
#include "esp_lcd_panel_vendor.h"
#include "esp_lcd_panel_ops.h"
#include "esp_lcd_panel_commands.h"
#include "driver/gpio.h"
#include "driver/spi_master.h"
#include "esp_err.h"
#include "esp_log.h"
#include  "lvgl.h"
#include "esp_timer.h"
#include "img_logo.h"

#define PIN_POWER_ON          46

// ST7789 Parameters not documented in ESP IDF esp_lcd_panel_commands
#define ST7789_RAMCTRL		0xB0      // RAM control
#define ST7789_PORCTRL		0xB2      // Porch control
#define ST7789_GCTRL		0xB7      // Gate control
#define ST7789_VCOMS		0xBB      // VCOMS setting
#define ST7789_LCMCTRL		0xC0      // LCM control
#define ST7789_IDSET		0xC1      // ID setting
#define ST7789_VDVVRHEN		0xC2      // VDV and VRH command enable
#define ST7789_VRHS		0xC3      // VRH set
#define ST7789_VDVSET		0xC4      // VDV setting
#define ST7789_VCMOFSET		0xC5      // VCOMS offset set
#define ST7789_FRCTR2		0xC6      // FR Control 2
#define ST7789_PWCTRL1		0xD0      // Power control 1
#define ST7789_VAPVANEN		0xD2      // Enable VAP/VAN signal output
#define ST7789_CMD2EN		0xDF      // Command 2 enable
#define ST7789_PVGAMCTRL	0xE0      // Positive voltage gamma control
#define ST7789_NVGAMCTRL	0xE1      // Negative voltage gamma control
#define ST7789_DGMLUTR		0xE2      // Digital gamma look-up table for red
#define ST7789_DGMLUTB		0xE3      // Digital gamma look-up table for blue
#define ST7789_GATECTRL		0xE4      // Gate control
#define ST7789_SPI2EN		0xE7      // SPI2 enable
#define ST7789_PWCTRL2		0xE8      // Power control 2
#define ST7789_EQCTRL		0xE9      // Equalize time control
#define ST7789_PROMCTRL		0xEC      // Program control
#define ST7789_PROMEN		0xFA      // Program mode enable
#define ST7789_NVMSET		0xFC      // NVM setting
#define ST7789_PROMACT		0xFE      // Program action

// Why is this called LCD PIXEL CLOCK when it's really SPI Bus speed?
#define LCD_PIXEL_CLOCK_HZ     (20 * 1000 * 1000)

// LVGL update interval
#define LVGL_TICK_PERIOD_MS 2

#define TAG "hello_lcd"

// from https://github.com/Xinyuan-LilyGO/T-Embed
#define LCD_H_RES              170
#define LCD_V_RES              320

// Commands for the LCD panel on init
typedef struct {
    uint8_t cmd;
    uint8_t data[14]; // TODO: Seems like a waste of space, can do better surely
    uint8_t len;
} lcd_cmd_t;

void lvgl_demo_ui(lv_disp_t *disp) {
    /*Change the active screen's background color*/
    lv_obj_set_style_bg_color(lv_disp_get_scr_act(disp), lv_color_hex(0x003a57), LV_PART_MAIN);

    /*Create a white label, set its text and align it to the center*/
    lv_obj_t * label = lv_label_create(lv_disp_get_scr_act(disp));
    lv_label_set_text(label, "Hello world");
    lv_obj_set_style_text_color(lv_disp_get_scr_act(disp), lv_color_hex(0xffffff), LV_PART_MAIN);
    lv_obj_align(label, LV_ALIGN_CENTER, 0, 0);
}

static bool notify_lvgl_flush_ready(esp_lcd_panel_io_handle_t panel_io, esp_lcd_panel_io_event_data_t *edata, void *user_ctx)
{
    lv_disp_drv_t *disp_driver = (lv_disp_drv_t *)user_ctx;
    lv_disp_flush_ready(disp_driver);
    return false;
}

static void lvgl_flush_cb(lv_disp_drv_t *drv, const lv_area_t *area, lv_color_t *color_map)
{
    esp_lcd_panel_handle_t panel_handle = (esp_lcd_panel_handle_t) drv->user_data;
    int offsetx1 = area->x1;
    int offsetx2 = area->x2;
    int offsety1 = area->y1;
    int offsety2 = area->y2;
    // copy a buffer's content to a specific area of the display
    esp_lcd_panel_draw_bitmap(panel_handle, offsetx1, offsety1, offsetx2 + 1, offsety2 + 1, color_map);
}

/* Rotate display and touch, when rotated screen in LVGL. Called when driver parameters are updated. */
static void lvgl_port_update_callback(lv_disp_drv_t *drv)
{
    esp_lcd_panel_handle_t panel_handle = (esp_lcd_panel_handle_t) drv->user_data;

    switch (drv->rotated) {
    case LV_DISP_ROT_NONE:
        // Rotate LCD display
        esp_lcd_panel_swap_xy(panel_handle, false);
        esp_lcd_panel_mirror(panel_handle, true, false);
        break;
    case LV_DISP_ROT_90:
        // Rotate LCD display
        esp_lcd_panel_swap_xy(panel_handle, true);
        esp_lcd_panel_mirror(panel_handle, true, true);
        break;
    case LV_DISP_ROT_180:
        // Rotate LCD display
        esp_lcd_panel_swap_xy(panel_handle, false);
        esp_lcd_panel_mirror(panel_handle, false, true);
        break;
    case LV_DISP_ROT_270:
        // Rotate LCD display
        esp_lcd_panel_swap_xy(panel_handle, true);
        esp_lcd_panel_mirror(panel_handle, true, false);
        break;
    }
}

static void increase_lvgl_tick(void *arg)
{
    /* Tell LVGL how many milliseconds has elapsed */
    lv_tick_inc(LVGL_TICK_PERIOD_MS);
}

void app_main(void)
{
    static lv_disp_draw_buf_t disp_buf; // contains internal graphic buffer(s) called draw buffer(s)
    static lv_disp_drv_t disp_drv;      // contains callback functions

    // Enable power to the T-Embed peripherals
    gpio_config_t pw_gpio_config = {
        .mode = GPIO_MODE_OUTPUT,
        .pin_bit_mask = 1ULL << PIN_POWER_ON
    };
    ESP_ERROR_CHECK(gpio_config(&pw_gpio_config));
    gpio_set_level(PIN_POWER_ON, 1);

    printf("Hello lcd!\n");

    /* Print chip information */
    esp_chip_info_t chip_info;
    uint32_t flash_size;
    esp_chip_info(&chip_info);
    printf("This is %s chip with %d CPU core(s), WiFi%s%s, ",
           CONFIG_IDF_TARGET,
           chip_info.cores,
           (chip_info.features & CHIP_FEATURE_BT) ? "/BT" : "",
           (chip_info.features & CHIP_FEATURE_BLE) ? "/BLE" : "");

    unsigned major_rev = chip_info.revision / 100;
    unsigned minor_rev = chip_info.revision % 100;
    printf("silicon revision v%d.%d, ", major_rev, minor_rev);
    if(esp_flash_get_size(NULL, &flash_size) != ESP_OK) {
        printf("Get flash size failed");
        return;
    }

    printf("%uMB %s flash\n", flash_size / (1024 * 1024),
           (chip_info.features & CHIP_FEATURE_EMB_FLASH) ? "embedded" : "external");

    printf("Minimum free heap size: %d bytes\n", esp_get_minimum_free_heap_size());

    ESP_LOGI(TAG, "Turn off LCD backlight");
    gpio_config_t bk_gpio_config = {
        .mode = GPIO_MODE_OUTPUT,
        .pin_bit_mask = 1ULL << 15
    };
    ESP_ERROR_CHECK(gpio_config(&bk_gpio_config));

    ESP_LOGI(TAG, "Initialize SPI bus");
    spi_bus_config_t buscfg = {
        .sclk_io_num = 12,
        .mosi_io_num = 11,
        .miso_io_num = -1,
        .quadwp_io_num = -1, // Quad SPI LCD driver is not yet supported
        .quadhd_io_num = -1, // Quad SPI LCD driver is not yet supported
        .max_transfer_sz = 320 * 80 * sizeof(uint16_t), // transfer 80 lines of pixels (assume pixel is RGB565) at most in one SPI transaction,
        .flags = SPICOMMON_BUSFLAG_GPIO_PINS
    };
    ESP_ERROR_CHECK(spi_bus_initialize(SPI2_HOST, &buscfg, SPI_DMA_CH_AUTO)); // Enable the DMA feature

    ESP_LOGI(TAG, "Init panel io");
    esp_lcd_panel_io_handle_t io_handle = NULL;
    esp_lcd_panel_io_spi_config_t io_config = {
        .dc_gpio_num = 13,
        .cs_gpio_num = 10,
        .pclk_hz = LCD_PIXEL_CLOCK_HZ,
        .lcd_cmd_bits = 8,
        .lcd_param_bits = 8,
        .spi_mode = 2,
        .trans_queue_depth = 10,
        .flags.dc_low_on_data = 0,
        .flags.lsb_first = 0,
        .flags.sio_mode = 1,
        .flags.cs_high_active = 0,
        .on_color_trans_done = notify_lvgl_flush_ready,
        .user_ctx = &disp_drv,
    };

    // Attach the LCD to the SPI bus
    ESP_ERROR_CHECK(esp_lcd_new_panel_io_spi((esp_lcd_spi_bus_handle_t)SPI2_HOST, &io_config, &io_handle));

    ESP_LOGI(TAG, "Attach panel");

    esp_lcd_panel_handle_t panel_handle = NULL;
    esp_lcd_panel_dev_config_t panel_config = {
        .reset_gpio_num = 9,
        .flags.reset_active_high = 0,
        .rgb_endian = LCD_RGB_ENDIAN_RGB,
        .bits_per_pixel = 16,
    };

    // Create LCD panel handle for ST7789, with the SPI IO device handle
    ESP_ERROR_CHECK(esp_lcd_new_panel_st7789(io_handle, &panel_config, &panel_handle));

    ESP_LOGI(TAG, "Init lcd");
    ESP_ERROR_CHECK(esp_lcd_panel_reset(panel_handle));
    vTaskDelay(pdMS_TO_TICKS(500));
    ESP_ERROR_CHECK(esp_lcd_panel_init(panel_handle));
    vTaskDelay(pdMS_TO_TICKS(500));

    // Command sequence from https://github.com/Xinyuan-LilyGO/T-Embed/blob/main/example/tft/tft.ino#L12
    lcd_cmd_t lcd_st7789v[] = {
        {ST7789_PORCTRL, {0X0B, 0X0B, 0X00, 0X33, 0X33}, 5},
        {ST7789_GCTRL, {0X75}, 1},
        {ST7789_VCOMS, {0X28}, 1},
        {ST7789_LCMCTRL, {0X2C}, 1},
        {ST7789_VDVVRHEN, {0X01}, 1},
        {ST7789_VRHS, {0X1F}, 1},
        {ST7789_FRCTR2, {0X13}, 1},
        {ST7789_PWCTRL1, {0XA7}, 1},
        {ST7789_PWCTRL1, {0XA4, 0XA1}, 2},
        {0xD6, {0XA1}, 1},
        {ST7789_PVGAMCTRL, {0XF0, 0X05, 0X0A, 0X06, 0X06, 0X03, 0X2B, 0X32, 0X43, 0X36, 0X11, 0X10, 0X2B, 0X32}, 14},
        {ST7789_NVGAMCTRL, {0XF0, 0X08, 0X0C, 0X0B, 0X09, 0X24, 0X2B, 0X22, 0X43, 0X38, 0X15, 0X16, 0X2F, 0X37}, 14},
        // CAS and RAS are set by the ESP_lcd driver
    };

    for (uint8_t i = 0; i < (sizeof(lcd_st7789v) / sizeof(lcd_cmd_t)); i++) {
        ESP_ERROR_CHECK(esp_lcd_panel_io_tx_param(io_handle, lcd_st7789v[i].cmd, lcd_st7789v[i].data, lcd_st7789v[i].len & 0x7f));
        if (lcd_st7789v[i].len & 0x80) {
            vTaskDelay(pdMS_TO_TICKS(120));
        }
    }

    ESP_LOGI(TAG, "Enable lcd");
    ESP_ERROR_CHECK(esp_lcd_panel_disp_on_off(panel_handle, true));

    ESP_LOGI(TAG, "Turn on LCD backlight");
    gpio_set_level(15, 1);

    esp_lcd_panel_set_gap(panel_handle, 0, 35); // Some offset from the start of the line to where the display actually is

    // Swap coordinates around to match the display
    esp_lcd_panel_swap_xy(panel_handle, true);
    esp_lcd_panel_mirror(panel_handle, true, false);

    // Draw the LILLYGO Logo as a test and whilst we're initializing the rest of the app
    esp_lcd_panel_draw_bitmap(panel_handle, 0, 0, 320, 170, img_logo);

    ESP_LOGI(TAG, "Initialize LVGL library");
    lv_init();

    // alloc draw buffers used by LVGL
    // it's recommended to choose the size of the draw buffer(s) to be at least 1/10 screen sized
    lv_color_t *buf1 = heap_caps_malloc(LCD_H_RES * 20 * sizeof(lv_color_t), MALLOC_CAP_DMA);
    assert(buf1);
    lv_color_t *buf2 = heap_caps_malloc(LCD_H_RES * 20 * sizeof(lv_color_t), MALLOC_CAP_DMA);
    assert(buf2);
    // initialize LVGL draw buffers
    lv_disp_draw_buf_init(&disp_buf, buf1, buf2, LCD_H_RES * 20);
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
cydergoth, 2023-01-15:
Also can't find any documentation on LCD command 0xD6

cydergoth, 2023-01-17:
Uploaded the above demo as a proper PR, having improved the structure to make it more reusable

lewisxhe, 2023-03-17:
"Yes, it depends on the hardware. The prerequisite for using it is to set IO46 to HIGH. Thank you for your example. If you can submit a PR for me, I will close the issue."

Closed 2023-03-17.

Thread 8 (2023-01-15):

GPIO pinout on the diagram does not match the 8 pin connector on the board

cydergoth, 2023-01-15:
GPIO pinout on the diagram does not match the 8 pin connector on the board; it shows 5 and 6 pins instead of 4 and 4

mmMicky, 2023-01-30:
Happy New Year. Thanks for sharing, I will fix the problem later.

Closed 2023-01-30.

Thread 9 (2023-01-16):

The .ino file is missing

orion14794, 2023-01-16:
Inside the example folder for the factory folder sketch, the .ino file is missing and am not able to load the sketch on Arduino IDE to burn it on the T-Embed.

mmMicky, 2023-01-30:
It is built with platformIO. The environment used is the same as Arduino. Just the file name is main.cpp

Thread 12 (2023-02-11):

Can we get a separate user_select file for T_embed in tft_eSPI

0x786d, 2023-02-11:
In latest TFT_eSPI library by Bodmer, we got setup206 file for T-Display-S3 and if i am not wrong, i guess @mmMicky contributed on it too.  Nevertheless it works great for T-Display-S3 board now.  Can we get a separate file for lilygo T-Embed also?  This would solve big problem for users who are using both boards.   I have tried tft_eSPI library included in this repository and have tried everything what i could do but display of my T-Embed is not working.  I was able to run some sketches from Volos Projects on it before but not anymore even if with current repository's tft_eSPI library.

lewisxhe, 2023-03-17:
PR has been added to the main branch.
https://github.com/Bodmer/TFT_eSPI/pull/2510

Closed 2023-03-17.

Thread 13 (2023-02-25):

Is there an Arduino format .ino file for the factory code on the T-Embed?

reflectingme, 2023-02-25:
Apologies if I have missed this, but is there an Arduino format file - .ino - (not platformIO) for the factory demo code on the T_Embed please?

lewisxhe, 2023-03-17:
"All examples should be available. If you encounter any problems that cannot be compiled, please let me know. I will close the problem first, and if there are still problems, please reopen it."

reflectingme, 2023-03-17:
Thanks @lewisxhe - I checked again and there is still no factory .ino for the T-Embed device in the GitHub repo.  Users can only restore the factory image if they use PlatfomIO, and many don't.

lewisxhe, 2023-03-18:
Completed, please repurchase

Closed 2023-03-18.

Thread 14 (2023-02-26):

SD dont work.

onimahoni, 2023-02-26:
Hello,
i compiled the factory example. Everything works except for the sd card.
I tested 3 SD with fat32.  I tested with PlatfromIO and Arduino IDE.
What am I doing wrong. any solution?

lewisxhe, 2023-03-17:
I have uploaded the factory test program, please test it. If there are still problems, it may be a hardware problem. I will close the problem first, and if there are still problems, please reopen it.

Closed 2023-03-17.

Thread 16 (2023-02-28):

Is there a 'boot' button on the T-Embed board as I need to reset

reflectingme, 2023-02-28:
On the t-display and t-display touch boards there is a boot GPIO-0 button that can be used to reset the board in the event of a fail, by holding the boot button down before plugging the USB cable in, then attach the Usb cable, then release and upload the code etc.  This procedure is described in the **TIPS** section of the relevant GitHub pages.

How does one do this on the T-Embed board please?  Mine is currently u/s, I can't use it at all and I cannot get **any** sketch to upload!

Thanks

Maestro8484, 2023-03-03:
i would like to know this as well.  how does one activate this 'boot' function AND how do you turn the device off when on battery power?

reflectingme, 2023-03-07:
So, I have discovered the BOOT button GPIO 0 is actually the centre button for the rotary encoder dial.  However, using the same process as described on the T-Display GitHub board page to reset the board via BOOT mode does not work with the T-Embed board.
Frustrating.

lesept777, 2023-09-01:
It seems possible to reset the T-Embed. GPIO 0 is connected to the encoder button.
Push the encoder button, push the reset button, power on the device, release the reset button then release the encoder button

Closed 2023-03-15.

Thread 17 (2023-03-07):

Colour rendering backgrounds, text or drawn objects with LilyGo supplied TFT_eSPI library is not correct

reflectingme, 2023-03-07:
OK, I have a strange issue and am wondering if anyone can point me in the right direction please.

I am using the LilyGo T-Embed ESP32S3 device which is working _almost_ as I wish, however when using the supplied TFT_eSPI library (the version of which which LilyGo advise MUST be used), the colors displayed and rendered either as backgrounds, text or drawn objects are all incorrect.

For example, the code:

`tft.fillScreen(TFT_RED);`

actually fills the screen with blue!! and this code...

```
tft.setTextColor(TFT_YELLOW, TFT_BLACK);
tft.drawString("testing yellow", 10, 100, 4);
```

... renders teal coloured text and NOT yellow!!

Now, as both the T-Display and Touch versions each use RGB565 for colours which render fine, does the T-Embed board use a different colour format?

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

lewisxhe, 2023-03-17:
Fixed, please update the TFT in the lib directory again_ ESPI Library

Closed 2023-03-17.

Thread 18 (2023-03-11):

User_Setup_Select.h contents for T-Embed show selected device at a resolution of 240*240

reflectingme, 2023-03-11:
I own three LilyGo boards, a T-Display, a T-Display Touch and a T-Embed and I am having trouble using the TFT_eSPI library when switching to the T-Embed device.

In the User_Setup_Select.h file which is I believe, the file responsible for determining the correct device configuration for the attached board.  The one selected in this file in the Xinyuan-LilyGo/T-Embed git hub respiratory is line 52;

`#include <User_Setups/Setup24_ST7789.h>            // Setup file for DSTIKE/ESP32/ESP8266 configured for ST7789 240 x 240
`
However, the description in the file refers to a display resolution of 240*240, which of course is not correct for the T-Embed board as this has a resolution of 320 x 170.

So this leads me to ask is this the correct configuration file for this device, can you confirm please and explain why the description resolution states 240 x 240.

ta

lewisxhe, 2023-03-17:
Updated<TFT_ ESPI>Library. and submit the configuration file to the main branch. Thank you for your support
https://github.com/Bodmer/TFT_eSPI/pull/2510

Closed 2023-03-17.

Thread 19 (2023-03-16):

please add firmware folder

369Martin369, 2023-03-16:
my T-Embed does not show any display activitiy. So I need to set it to shipping firmware.bin state, in order to check if there is a display hardware failure. I' dont know what I'm doing wrongly  (have correct SPi lib installed) but the display remains black.
Original firmware is only chance to check if system is okay.

Thanks for extending the branch with firmware.bin.
regards, Martin

PS. T-Display 3 and T-HMI work both great, but I failed with T-embed so far.

lewisxhe, 2023-03-17:
Has been added and the TFT has been updated_ ESPI library. I have completed T-Embed. Thank you for your support

Closed 2023-03-17.

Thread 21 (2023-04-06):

GPIO Pinout reference does not match physical board

cydergoth, 2023-04-06:
On the physical board the GPIO is an 8 pin DIL 0.1" connector, however the GPIO reference diagram shows an 11 pin?!

Please clarify the correct pinout for this connector.

lewisxhe, 2023-04-10:
You can see the correct pin definition here in the picture.
The pin diagram is that the later board leads the SPI of the screen to the socket

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

Closed 2023-04-10.

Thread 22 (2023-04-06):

Grove connector pinout on reference diagram does not match board

cydergoth, 2023-04-06:
On the reference diagram the Grove connector has GND 3V3 IO44 IO43, however on the physical board the pinout legend reads GND IO44 IO43 3V3.

 From the Grove documentation it seems as if the physical board has the correct pinout.

lewisxhe, 2023-04-09:
I will conduct an investigation on Monday

lewisxhe, 2023-04-10:
Please connect according to the silk screen instructions of the physical board. The pin diagram is updated later on the board.

akudan, 2023-04-30:
This is particularly confusing because the silkscreens are different between the image on GitHub and on lilygo.cc/Tindie. If the latter silkscreens are correct (i.e. GND IO44 IO43 3V3) then it's actually not directly Grove compatible and you'd need to modify a cable.

Closed 2023-04-10.

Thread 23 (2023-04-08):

Q: OTG host with power

cydergoth, 2023-04-08:
I'm trying to use the T-Embed with a USB device, using OTG.

In order to power it I have a USB OTG/PD cable which has a Y connector breaking out a USB-C port for power and a USB-A port for OTG.

Unfortunately when using this cable the T-Embed will not power up. Is there a suggested way to make this configuration work? I don't think I can use a battery as the battery voltage is 3.7V and the USB device needs 5v.

The cable is similar to this one: https://www.amazon.com/Adapter-Charging-Compatible-XL%EF%BC%8CGoogle-Chromecast/dp/B08C5FWQND

lewisxhe, 2023-04-09:
This may be because the cable is not supplying power to the t-embedded. You can use a multimeter to measure the position of the 5V Pin on the board and check if there is 5V

lewisxhe, 2023-04-13:
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
The easiest way is to measure the USBC here, be careful not to short circuit

cydergoth, 2023-04-15:
I tested the point you indicated and it is not receiving 5v. It looks like the PD negotiation is not working. Unfortunately I am not an expert at USB-C so I'm not sure if this is possible to fix in the bootloader or if it requires additional hardware to perform the negotiation

cydergoth, 2023-04-15:
If I plug in the upstream cable without the splitter, it powers up ok

cydergoth, 2023-04-15:
From my limited understanding of USB-C and looking at the schematic, it looks to me as if the T-Embed correctly implements the pulldown resistors for the "USB Type-C UFP sink: USB 2.0 without USB PD". This, along with it working with the upstream cable, implies to me that it is the splitter cable which is incorrect, so I'm closing this issue. Thanks for the useful feedback!

Closed 2023-04-15.

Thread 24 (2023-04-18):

WiFiClientSecure.h and  DNS Failed

jalmince, 2023-04-18:
Hi Lewis, ( or any knowledgeable guy ... )
Ive been trying to send hhtp request to web services for ages, with no success...
The issue boils down to the following
doing

#include <Arduino.h>
#include <WiFi.h>
#include <WiFiClientSecure.h>
void try_connect() {
WiFiClientSecure httpClient;
  if (!httpClient.connect("https://www.google.com", 8443)) {
    Serial.println("Connection failed");
    return;
  }_

I systematically get " hostByName(): DNS Failed for https://www.google.com"

what's going on ??
any help appreciated a lot
Thank,
JeanPaul

I am using VsCode/platformIO,
CONFIGURATION: https://docs.platformio.org/page/boards/espressif32/esp32-s3-devkitc-1.html
PACKAGES:
 - framework-arduinoespressif32 @ 3.20007.0 (2.0.7)

PS if doing WiFiClient ( not the "secure one "), and http ( not "s" ) to www.google 8080 I get the same error.
of course nothing is wrong with my network or router , since I cam connect with my PC!

lewisxhe, 2023-04-21:
Port 8443? Are you sure there's no problem? The normal encryption port is 443

jalmince, 2023-04-21:
Thanks Lewis for your reply !

Actually I cant manage to send a post request to OpenAI / whisper-1, and all boils down to not beeing able to connect via https to their server:

1) this works perfectly fine from my laptop, and I get the french text back ;)

curl -v  https://api.openai.com/v1/audio/transcriptions   -H "Authorization: Bearer ----my own api key -------"   -H "Content-Type: multipart/form-data"   -F file="@/home/osboxes/shared/salut.mp3"   -F model="whisper-1"

2) I want to do the same ( via WifiClientSecure ) in the T-Embed

a) I grab the certificate using :

openssl s_client -showcerts -connect api.openai.com:443 </dev/null

b) I put the certif in the following code :

#include <Arduino.h>
#include <WiFi.h>
#include <WiFiClientSecure.h>
#include <ArduinoJson.h>
#include "SD_MMC.h"

void try_connect() {

WiFiClientSecure client;

const char* test_root_ca="-----BEGIN CERTIFICATE-----\n" \
"MIIFKDCCBM6gAwIBAgIQCiYPyyp87Vr6rx8YVcaepDAKBggqhkjOPQQDAjBKMQsw\n" \
"CQYDVQQGEwJVUzEZMBcGA1UEChMQQ2xvdWRmbGFyZSwgSW5jLjEgMB4GA1UEAxMX\n" \
"Q2xvdWRmbGFyZSBJbmMgRUNDIENBLTMwHhcNMjMwMzI4MDAwMDAwWhcNMjQwMzI2\n" \
"MjM1OTU5WjB1MQswCQYDVQQGEwJVUzETMBEGA1UECBMKQ2FsaWZvcm5pYTEWMBQG\n" \
"A1UEBxMNU2FuIEZyYW5jaXNjbzEZMBcGA1UEChMQQ2xvdWRmbGFyZSwgSW5jLjEe\n" \
"MBwGA1UEAxMVc25pLmNsb3VkZmxhcmVzc2wuY29tMFkwEwYHKoZIzj0CAQYIKoZI\n" \
"zj0DAQcDQgAEZq45AFURHMWZGtVreuNOuVCVO9zy5q79Eco379GbrUKdAQzzdtKG\n" \
"Vp8oIFYFD+32qSpHKcZwalaf16xU0c7rfqOCA2kwggNlMB8GA1UdIwQYMBaAFKXO\n" \
"N+rrsHUOlGeItEX62SQQh5YfMB0GA1UdDgQWBBQeTvJUT72fOjMpDZGuUB5GsnKT\n" \
"rDAwBgNVHREEKTAnghVzbmkuY2xvdWRmbGFyZXNzbC5jb22CDmFwaS5vcGVuYWku\n" \
"Y29tMA4GA1UdDwEB/wQEAwIHgDAdBgNVHSUEFjAUBggrBgEFBQcDAQYIKwYBBQUH\n" \
"AwIwewYDVR0fBHQwcjA3oDWgM4YxaHR0cDovL2NybDMuZGlnaWNlcnQuY29tL0Ns\n" \
"b3VkZmxhcmVJbmNFQ0NDQS0zLmNybDA3oDWgM4YxaHR0cDovL2NybDQuZGlnaWNl\n" \
"cnQuY29tL0Nsb3VkZmxhcmVJbmNFQ0NDQS0zLmNybDA+BgNVHSAENzA1MDMGBmeB\n" \
"DAECAjApMCcGCCsGAQUFBwIBFhtodHRwOi8vd3d3LmRpZ2ljZXJ0LmNvbS9DUFMw\n" \
"dgYIKwYBBQUHAQEEajBoMCQGCCsGAQUFBzABhhhodHRwOi8vb2NzcC5kaWdpY2Vy\n" \
"dC5jb20wQAYIKwYBBQUHMAKGNGh0dHA6Ly9jYWNlcnRzLmRpZ2ljZXJ0LmNvbS9D\n" \
"bG91ZGZsYXJlSW5jRUNDQ0EtMy5jcnQwDAYDVR0TAQH/BAIwADCCAX0GCisGAQQB\n" \
"1nkCBAIEggFtBIIBaQFnAHYA7s3QZNXbGs7FXLedtM0TojKHRny87N7DUUhZRnEf\n" \
"tZsAAAGHKopugAAABAMARzBFAiEAl+s2f5YqdJB9bI2jLHeQ0w2u5UetA9bFnDkW\n" \
"zRKWM9MCIBYdWWHycq0mdyEcM+Xl6AUaDORyXmGlW6QPauYASd9gAHUAc9meiRtM\n" \
"lnigIH1HneayxhzQUV5xGSqMa4AQesF3crUAAAGHKopunQAABAMARjBEAiBQ2u8m\n" \
"vAVxM701nd+7K8BaCzMqcultmJ/Ap9hN5OHm8QIgQU9budkwHeiU+9M4kxliMymj\n" \
"p/lPTv2puWml5kAs4BgAdgBIsONr2qZHNA/lagL6nTDrHFIBy1bdLIHZu7+rOdiE\n" \
"cwAAAYcqim5jAAAEAwBHMEUCIE5EkJBZLdoAzFr7Mgau7UN7LgZ8EFCUML7bkF6e\n" \
"cy9jAiEAo57JtgRCnK0uxI7k1ZseNLOY4/sCyyf7khuxLlmLHIIwCgYIKoZIzj0E\n" \
"AwIDSAAwRQIhANrO5p0Plmso4Q69bixTSJjLVOJXl10Di4Qqi+HE10nzAiA14sPK\n" \
"ZhENjrwuxzRYPhFNkZQQryMJbC/5pUdYcO01Og==\n" \
"-----END CERTIFICATE-----\n" ;

const char* host = "api.openai.com";
const int httpsPort = 443;

if (!client.connect(host, httpsPort)) {
  Serial.println("Connection failed");
  return;
  }
}

and I always get :

[  6232][E][WiFiClientSecure.cpp:144] connect(): start_ssl_client: -1
Connection failed

needless to say there's is no point going any further building the POST headers and sending the "Content-Type: multipart/form-data" stuff and the wav file bytes ;)

Would be great if you could sort me out !!
Thanks,
Jean-Paul

lewisxhe, 2023-04-22:
start_ssl_client: -1
This kind of problem is generally caused by the failure of certificate verification. This is not a hardware problem

You can try to run this validation
https://github.com/espressif/arduino-esp32/blob/master/libraries/WiFiClientSecure/examples/WiFiClientSecure/WiFiClientSecure.ino

lewisxhe, 2023-04-22:
I noticed that your certificate string does not have a continuation character, the correct one should look like this
```
const char* test_root_ca="-----BEGIN CERTIFICATE-----\n" \
"MIIFKDCCBM6gAwIBAgIQCiYPyyp87Vr6rx8YVcaepDAKBggqhkjOPQQDAjBKMQsw\n" \
"CQYDVQQGEwJVUzEZMBcGA1UEChMQQ2xvdWRmbGFyZSwgSW5jLjEgMB4GA1UEAxMX\n" \
"Q2xvdWRmbGFyZSBJbmMgRUNDIENBLTMwHhcNMjMwMzI4MDAwMDAwWhcNMjQwMzI2\n" \
"MjM1OTU5WjB1MQswCQYDVQQGEwJVUzETMBEGA1UECBMKQ2FsaWZvcm5pYTEWMBQG\n" \
"A1UEBxMNU2FuIEZyYW5jaXNjbzEZMBcGA1UEChMQQ2xvdWRmbGFyZSwgSW5jLjEe\n" \
"MBwGA1UEAxMVc25pLmNsb3VkZmxhcmVzc2wuY29tMFkwEwYHKoZIzj0CAQYIKoZI\n" \
"zj0DAQcDQgAEZq45AFURHMWZGtVreuNOuVCVO9zy5q79Eco379GbrUKdAQzzdtKG\n" \
"Vp8oIFYFD+32qSpHKcZwalaf16xU0c7rfqOCA2kwggNlMB8GA1UdIwQYMBaAFKXO\n" \
"N+rrsHUOlGeItEX62SQQh5YfMB0GA1UdDgQWBBQeTvJUT72fOjMpDZGuUB5GsnKT\n" \
"rDAwBgNVHREEKTAnghVzbmkuY2xvdWRmbGFyZXNzbC5jb22CDmFwaS5vcGVuYWku\n" \
"Y29tMA4GA1UdDwEB/wQEAwIHgDAdBgNVHSUEFjAUBggrBgEFBQcDAQYIKwYBBQUH\n" \
"AwIwewYDVR0fBHQwcjA3oDWgM4YxaHR0cDovL2NybDMuZGlnaWNlcnQuY29tL0Ns\n" \
"b3VkZmxhcmVJbmNFQ0NDQS0zLmNybDA3oDWgM4YxaHR0cDovL2NybDQuZGlnaWNl\n" \
"cnQuY29tL0Nsb3VkZmxhcmVJbmNFQ0NDQS0zLmNybDA+BgNVHSAENzA1MDMGBmeB\n" \
"DAECAjApMCcGCCsGAQUFBwIBFhtodHRwOi8vd3d3LmRpZ2ljZXJ0LmNvbS9DUFMw\n" \
"dgYIKwYBBQUHAQEEajBoMCQGCCsGAQUFBzABhhhodHRwOi8vb2NzcC5kaWdpY2Vy\n" \
"dC5jb20wQAYIKwYBBQUHMAKGNGh0dHA6Ly9jYWNlcnRzLmRpZ2ljZXJ0LmNvbS9D\n" \
"bG91ZGZsYXJlSW5jRUNDQ0EtMy5jcnQwDAYDVR0TAQH/BAIwADCCAX0GCisGAQQB\n" \
"1nkCBAIEggFtBIIBaQFnAHYA7s3QZNXbGs7FXLedtM0TojKHRny87N7DUUhZRnEf\n" \
"tZsAAAGHKopugAAABAMARzBFAiEAl+s2f5YqdJB9bI2jLHeQ0w2u5UetA9bFnDkW\n" \
"zRKWM9MCIBYdWWHycq0mdyEcM+Xl6AUaDORyXmGlW6QPauYASd9gAHUAc9meiRtM\n" \
"lnigIH1HneayxhzQUV5xGSqMa4AQesF3crUAAAGHKopunQAABAMARjBEAiBQ2u8m\n" \
"vAVxM701nd+7K8BaCzMqcultmJ/Ap9hN5OHm8QIgQU9budkwHeiU+9M4kxliMymj\n" \
"p/lPTv2puWml5kAs4BgAdgBIsONr2qZHNA/lagL6nTDrHFIBy1bdLIHZu7+rOdiE\n" \
"cwAAAYcqim5jAAAEAwBHMEUCIE5EkJBZLdoAzFr7Mgau7UN7LgZ8EFCUML7bkF6e\n" \
"cy9jAiEAo57JtgRCnK0uxI7k1ZseNLOY4/sCyyf7khuxLlmLHIIwCgYIKoZIzj0E\n" \
"AwIDSAAwRQIhANrO5p0Plmso4Q69bixTSJjLVOJXl10Di4Qqi+HE10nzAiA14sPK\n" \
"ZhENjrwuxzRYPhFNkZQQryMJbC/5pUdYcO01Og==\n" \
"-----END CERTIFICATE-----\n" ;

```

jalmince, 2023-04-22:
PS: the board is of course already connected to my wifi before this runs ;)  ( fails should I say ! )

jalmince, 2023-04-22:
Hi Lewis !
Many thanks for your dedication and help.
After long googling hours I have found the solution:
that is we have to set:  client.setInsecure() before the connect client attempt ...
That's counter intuitive by the name since we are trying a "secure" connection.... and happened after 3.0 version..
Many thanks again
Jean-Paul

Closed 2023-04-22.

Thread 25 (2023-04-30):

Is it possible to externally charge battery while connected?

akudan, 2023-04-30:
I would like to use the same 3.7V Li-ion battery to power the T-Embed and another microcontroller with its own charging circuit. I want to make sure that when charging the battery from the second microcontroller I will not damage the T-Embed. I imagine this will work okay since typically the charging voltage should be around the max battery voltage (4.2V) but I cannot find any information on the charging IC mentioned in the schematics (TP4065B). Can you confirm that this is possible?

lewisxhe, 2023-07-27:
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
http://www.szyucan.com/upfile/IC-PDF/TP4065.pdf
I don't understand your connection method, this is the manual, unfortunately only in Chinese.

Closed 2023-10-18.

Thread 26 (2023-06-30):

How to reset?

d3mac123, 2023-06-30:
I ran my first code (sample from here) into the board but nothing shows on the display (only the blue led blinks). I then tried the audio sample and all I get, besides the black screen, is a noise (like a dot) from the speaker :(

lewisxhe, 2023-06-30:
Check whether TFT_eSPI/User_Setup_Select.h has been correctly configured embed https://github.com/Xinyuan-LilyGO/T-Embed/blob/50faf3ed2911faf423489a9e3045e45eb219f808/lib/TFT_eSPI/User_Setup_Select.h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

lesept777, 2023-09-01:
It seems possible to reset the T-Embed. GPIO 0 is connected to the encoder button.
Push the button, push the reset button, power on the device, release the reset button then release the encoder button

Closed 2023-07-04.

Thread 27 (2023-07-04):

How to run the music example?

d3mac123, 2023-07-04:
I am trying to run the music (play mp3 file) example but I am getting the following error (after installed the ESP32-audioI2S library). Any idea on how to fix this? I am using Arduino IDE 2.1.
`/Users/alexsouza/Library/Arduino15/packages/esp32/tools/xtensa-esp32s3-elf-gcc/esp-2021r2-patch5-8.4.0/bin/../lib/gcc/xtensa-esp32s3-elf/8.4.0/../../../../xtensa-esp32s3-elf/bin/ld: /private/var/folders/j0/_j5h8rw161l2lrx2khy0_2wh0000gn/T/arduino/sketches/A467C159EA95225C167DF9EE4CCB4D3C/libraries/ESP32-audioI2S-master/Audio.cpp.o:(.literal._ZN5Audio17initializeDecoderEv+0x30): undefined reference to `MP3Decoder_AllocateBuffers()'
/Users/alexsouza/Library/Arduino15/packages/esp32/tools/xtensa-esp32s3-elf-gcc/esp-2021r2-patch5-8.4.0/bin/../lib/gcc/xtensa-esp32s3-elf/8.4.0/../../../../xtensa-esp32s3-elf/bin/ld: /private/var/folders/j0/_j5h8rw161l2lrx2khy0_2wh0000gn/T/arduino/sketches/A467C159EA95225C167DF9EE4CCB4D3C/libraries/ESP32-audioI2S-master/Audio.cpp.o:(.literal._ZN5Audio17initializeDecoderEv+0x38): undefined reference to `AACDecoder_IsInit()'
/Users/alexsouza/Library/Arduino15/packages/esp32/tools/xtensa-esp32s3-elf-gcc/esp-2021r2-patch5-8.4.0/bin/../lib/gcc/xtensa-esp32s3-elf/8.4.0/../../../../xtensa-esp32s3-elf/bin/ld: /private/var/folders/j0/_j5h8rw161l2lrx2khy0_2wh0000gn/T/arduino/sketches/A467C159EA95225C167DF9EE4CCB4D3C/libraries/ESP32-audioI2S-master/Audio.cpp.o:(.literal._ZN5Audio17initializeDecoderEv+0x3c): undefined reference to `AACDecoder_AllocateBuffers()'
/Users/alexsouza/Library/Arduino15/packages/esp32/tools/xtensa-esp32s3-elf-gcc/esp-2021r2-patch5-8.4.0/bin/../lib/gcc/xtensa-esp32s3-elf/8.4.0/../../../../xtensa-esp32s3-elf/bin/ld: /private/var/folders/j0/_j5h8rw161l2lrx2khy0_2wh0000gn/T/arduino/sketches/A467C159EA95225C167DF9EE4CCB4D3C/libraries/ESP32-audioI2S-master/Audio.cpp.o:(.literal._ZN5Audio17initializeDecoderEv+0x40): undefined reference to `FLACDecoder_AllocateBuffers()'
/Users/alexsouza/Library/Arduino15/packages/esp32/tools/xtensa-esp32s3-elf-gcc/esp-2021r2-patch5-8.4.0/bin/../lib/gcc/xtensa-esp32s3-elf/8.4.0/../../../../xtensa-esp32s3-elf/bin/ld: /private/var/folders/j0/_j5h8rw161l2lrx2khy0_2wh0000gn/T/arduino/sketches/A467C159EA95225C167DF9EE4CCB4D3C/libraries/ESP32-audioI2S-master/Audio.cpp.o:(.literal._ZN5Audio17initializeDecoderEv+0x44): undefined reference to `OPUSDecoder_AllocateBuffers()'
/Users/alexsouza/Library/Arduino15/packages/esp32/tools/xtensa-esp32s3-elf-gcc/esp-2021r2-patch5-8.4.0/bin/../lib/gcc/xtensa-esp32s3-elf/8.4.0/../../../../xtensa-esp32s3-elf/bin/ld: /private/var/folders/j0/_j5h8rw161l2lrx2khy0_2wh0000gn/T/arduino/sketches/A467C159EA95225C167DF9EE4CCB4D3C/libraries/ESP32-audioI2S-master/Audio.cpp.o:(.literal._ZN5Audio17initializeDecoderEv+0x48): undefined reference to `VORBISDecoder_AllocateBuffers()'
/Users/alexsouza/Library/Arduino15/packages/esp32/tools/xtensa-esp32s3-elf-gcc/esp-2021r2-patch5-8.4.0/bin/../lib/gcc/xtensa-esp32s3-elf/8.4.0/../../../../xtensa-esp32s3-elf/bin/ld: /private/var/folders/j0/_j5h8rw161l2lrx2khy0_2wh0000gn/T/arduino/sketches/A467C159EA95225C167DF9EE4CCB4D3C/libraries/ESP32-audioI2S-master/Audio.cpp.o:(.literal._ZN5Audio15showCodecParamsEv+0x28): undefined reference to `AACGetFormat()'
/Users/alexsouza/Library/Arduino15/packages/esp32/tools/xtensa-esp32s3-elf-gcc/esp-2021r2-patch5-8.4.0/bin/../lib/gcc/xtensa-esp32s3-elf/8.4.0/../../../../xtensa-esp32s3-elf/bin/ld: /private/var/folders/j0/_j5h8rw161l2lrx2khy0_2wh0000gn/T/arduino/sketches/A467C159EA95225C167DF9EE4CCB4D3C/libraries/ESP32-audioI2S-master/Audio.cpp.o:(.literal._ZN5Audio15showCodecParamsEv+0x2c): undefined reference to `AACGetID()'
/Users/alexsouza/Library/Arduino15/packages/esp32/tools/xtensa-esp32s3-elf-gcc/esp-2021r2-patch5-8.4.0/bin/../lib/gcc/xtensa-esp32s3-elf/8.4.0/../../../../xtensa-esp32s3-elf/bin/ld: /private/var/folders/j0/_j5h8rw161l2lrx2khy0_2wh0000gn/T/arduino/sketches/A467C159EA95225C167DF9EE4CCB4D3C/libraries/ESP32-audioI2S-master/Audio.cpp.o:(.literal._ZN5Audio15showCodecParamsEv+0x30): undefined reference to `AACGetProfile()'
/Users/alexsouza/Library/Arduino15/packages/esp32/tools/xtensa-esp32s3-elf-gcc/esp-2021r2-patch5-8.4.0/bin/../lib/gcc/xtensa-esp32s3-elf/8.4.0/../../../../xtensa-esp32s3-elf/bin/ld: /private/var/folders/j0/_j5h8rw161l2lrx2khy0_2wh0000gn/T/arduino/sketches/A467C159EA95225C167DF9EE4CCB4D3C/libraries/ESP32-audioI2S-master/Audio.cpp.o:(.literal._ZN5Audio12findNextSyncEPhj+0x18): undefined reference to `MP3FindSyncWord(unsigned char*, int)'
/Users/alexsouza/Library/Arduino15/packages/esp32/tools/xtensa-esp32s3-elf-gcc/esp-2021r2-patch5-8.4.0/bin/../lib/gcc/xtensa-esp32s3-elf/8.4.0/../../../../xtensa-esp32s3-elf/bin/ld: /private/var/folders/j0/_j5h8rw161l2lrx2khy0_2wh0000gn/T/arduino/sketches/A467C159EA95225C167DF9EE4CCB4D3C/libraries/ESP32-audioI2S-master/Audio.cpp.o:(.literal._ZN5Audio12findNextSyncEPhj+0x1c): undefined reference to `AACFindSyncWord(unsigned char*, int)'
/Users/alexsouza/Library/Arduino15/packages/esp32/tools/xtensa-esp32s3-elf-gcc/esp-2021r2-patch5-8.4.0/bin/../lib/gcc/xtensa-esp32s3-elf/8.4.0/../../../../xtensa-esp32s3-elf/bin/ld: /private/var/folders/j0/_j5h8rw161l2lrx2khy0_2wh0000gn/T/arduino/sketches/A467C159EA95225C167DF9EE4CCB4D3C/libraries/ESP32-audioI2S-master/Audio.cpp.o:(.literal._ZN5Audio12findNextSyncEPhj+0x20): undefined reference to `AACSetRawBlockParams(int, int, int, int)'
/Users/alexsouza/Library/Arduino15/packages/esp32/tools/xtensa-esp32s3-elf-gcc/esp-2021r2-patch5-8.4.0/bin/../lib/gcc/xtensa-esp32s3-elf/8.4.0/../../../../xtensa-esp32s3-elf/bin/ld: /private/var/folders/j0/_j5h8rw161l2lrx2khy0_2wh0000gn/T/arduino/sketches/A467C159EA95225C167DF9EE4CCB4D3C/libraries/ESP32-audioI2S-master/Audio.cpp.o:(.literal._ZN5Audio12findNextSyncEPhj+0x24): undefined reference to `FLACSetRawBlockParams(unsigned char, unsigned int, unsigned char, unsigned int, unsigned int)'
/Users/alexsouza/Library/Arduino15/packages/esp32/tools/xtensa-esp32s3-elf-gcc/esp-2021r2-patch5-8.4.0/bin/../lib/gcc/xtensa-esp32s3-elf/8.4.0/../../../../xtensa-esp32s3-elf/bin/ld: /private/var/folders/j0/_j5h8rw161l2lrx2khy0_2wh0000gn/T/arduino/sketches/A467C159EA95225C167DF9EE4CCB4D3C/libraries/ESP32-audioI2S-master/Audio.cpp.o:(.literal._ZN5Audio12findNextSyncEPhj+0x28): undefined reference to `FLACFindSyncWord(unsigned char*, int)'
/Users/alexsouza/Library/Arduino15/packages/esp32/tools/xtensa-esp32s3-elf-gcc/esp-2021r2-patch5-8.4.0/bin/../lib/gcc/xtensa-esp32s3-elf/8.4.0/../../../../xtensa-esp32s3-elf/bin/ld: /private/var/folders/j0/_j5h8rw161l2lrx2khy0_2wh0000gn/T/arduino/sketches/A467C159EA95225C167DF9EE4CCB4D3C/libraries/ESP32-audioI2S-master/Audio.cpp.o:(.literal._ZN5Audio12findNextSyncEPhj+0x2c): undefined reference to `OPUSFindSyncWord(unsigned char*, int)'
/Users/alexsouza/Library/Arduino15/packages/esp32/tools/xtensa-esp32s3-elf-gcc/esp-2021r2-patch5-8.4.0/bin/../lib/gcc/xtensa-esp32s3-elf/8.4.0/../../../../xtensa-esp32s3-elf/bin/ld: /private/var/folders/j0/_j5h8rw161l2lrx2khy0_2wh0000gn/T/arduino/sketches/A467C159EA95225C167DF9EE4CCB4D3C/libraries/ESP32-audioI2S-master/Audio.cpp.o:(.literal._ZN5Audio12findNextSyncEPhj+0x30): undefined reference to `VORBISFindSyncWord(unsigned char*, int)'
/Users/alexsouza/Library/Arduino15/packages/esp32/tools/xtensa-esp32s3-elf-gcc/esp-2021r2-patch5-8.4.0/bin/../lib/gcc/xtensa-esp32s3-elf/8.4.0/../../../../xtensa-esp32s3-elf/bin/ld: /private/var/folders/j0/_j5h8rw161l2lrx2khy0_2wh0000gn/T/arduino/sketches/A467C159EA95225C167DF9EE4CCB4D3C/libraries/ESP32-audioI2S-master/Audio.cpp.o:(.literal._ZN5Audio24compute_audioCurrentTimeEi+0x1c): undefined reference to `MP3GetBitrate()'
/Users/alexsouza/Library/Arduino15/packages/esp32/tools/xtensa-esp32s3-elf-gcc/esp-2021r2-patch5-8.4.0/bin/../lib/gcc/xtensa-esp32s3-elf/8.4.0/../../../../xtensa-esp32s3-elf/bin/ld: /private/var/folders/j0/_j5h8rw161l2lrx2khy0_2wh0000gn/T/arduino/sketches/A467C159EA95225C167DF9EE4CCB4D3C/libraries/ESP32-audioI2S-master/Audio.cpp.o:(.literal._ZN5Audio24compute_audioCurrentTimeEi+0x20): undefined reference to `AACGetBitrate()'
/Users/alexsouza/Library/Arduino15/packages/esp32/tools/xtensa-esp32s3-elf-gcc/esp-2021r2-patch5-8.4.0/bin/../lib/gcc/xtensa-esp32s3-elf/8.4.0/../../../../xtensa-esp32s3-elf/bin/ld: /private/var/folders/j0/_j5h8rw161l2lrx2khy0_2wh0000gn/T/arduino/sketches/A467C159EA95225C167DF9EE4CCB4D3C/libraries/ESP32-audioI2S-master/Audio.cpp.o:(.literal._ZN5Audio24compute_audioCurrentTimeEi+0x24): undefined reference to `FLACGetBitRate()'
/Users/alexsouza/Library/Arduino15/packages/esp32/tools/xtensa-esp32s3-elf-gcc/esp-2021r2-patch5-8.4.0/bin/../lib/gcc/xtensa-esp32s3-elf/8.4.0/../../../../xtensa-esp32s3-elf/bin/ld: /private/var/folders/j0/_j5h8rw161l2lrx2khy0_2wh0000gn/T/arduino/sketches/A467C159EA95225C167DF9EE4CCB4D3C/libraries/ESP32-audioI2S-master/Audio.cpp.o:(.literal._ZN5Audio15setDecoderItemsEv+0xc): undefined reference to `MP3GetChannels()'
/Users/alexsouza/Library/Arduino15/packages/esp32/tools/xtensa-esp32s3-elf-gcc/esp-2021r2-patch5-8.4.0/bin/../lib/gcc/xtensa-esp32s3-elf/8.4.0/../../../../xtensa-esp32s3-elf/bin/ld: /private/var/folders/j0/_j5h8rw161l2lrx2khy0_2wh0000gn/T/arduino/sketches/A467C159EA95225C167DF9EE4CCB4D3C/libraries/ESP32-audioI2S-master/Audio.cpp.o:(.literal._ZN5Audio15setDecoderItemsEv+0x10): undefined reference to `MP3GetSampRate()'
/Users/alexsouza/Library/Arduino15/packages/esp32/tools/xtensa-esp32s3-elf-gcc/esp-2021r2-patch5-8.4.0/bin/../lib/gcc/xtensa-esp32s3-elf/8.4.0/../../../../xtensa-esp32s3-elf/bin/ld: /private/var/folders/j0/_j5h8rw161l2lrx2khy0_2wh0000gn/T/arduino/sketches/A467C159EA95225C167DF9EE4CCB4D3C/libraries/ESP32-audioI2S-master/Audio.cpp.o:(.literal._ZN5Audio15setDecoderItemsEv+0x14): undefined reference to `MP3GetBitsPerSample()'
/Users/alexsouza/Library/Arduino15/packages/esp32/tools/xtensa-esp32s3-elf-gcc/esp-2021r2-patch5-8.4.0/bin/../lib/gcc/xtensa-esp32s3-elf/8.4.0/../../../../xtensa-esp32s3-elf/bin/ld: /private/var/folders/j0/_j5h8rw161l2lrx2khy0_2wh0000gn/T/arduino/sketches/A467C159EA95225C167DF9EE4CCB4D3C/libraries/ESP32-audioI2S-master/Audio.cpp.o:(.literal._ZN5Audio15setDecoderItemsEv+0x18): undefined reference to `AACGetChannels()'
/Users/alexsouza/Library/Arduino15/packages/esp32/tools/xtensa-esp32s3-elf-gcc/esp-2021r2-patch5-8.4.0/bin/../lib/gcc/xtensa-esp32s3-elf/8.4.0/../../../../xtensa-esp32s3-elf/bin/ld: /private/var/folders/j0/_j5h8rw161l2lrx2khy0_2wh0000gn/T/arduino/sketches/A467C159EA95225C167DF9EE4CCB4D3C/libraries/ESP32-audioI2S-master/Audio.cpp.o:(.literal._ZN5Audio15setDecoderItemsEv+0x1c): undefined reference to `AACGetSampRate()'
/Users/alexsouza/Library/Arduino15/packages/esp32/tools/xtensa-esp32s3-elf-gcc/esp-2021r2-patch5-8.4.0/bin/../lib/gcc/xtensa-esp32s3-elf/8.4.0/../../../../xtensa-esp32s3-elf/bin/ld: /private/var/folders/j0/_j5h8rw161l2lrx2khy0_2wh0000gn/T/arduino/sketches/A467C159EA95225C167DF9EE4CCB4D3C/libraries/ESP32-audioI2S-master/Audio.cpp.o:(.literal._ZN5Audio15setDecoderItemsEv+0x20): undefined reference to `AACGetBitsPerSample()'
/Users/alexsouza/Library/Arduino15/packages/esp32/tools/xtensa-esp32s3-elf-gcc/esp-2021r2-patch5-8.4.0/bin/../lib/gcc/xtensa-esp32s3-elf/8.4.0/../../../../xtensa-esp32s3-elf/bin/ld: /private/var/folders/j0/_j5h8rw161l2lrx2khy0_2wh0000gn/T/arduino/sketches/A467C159EA95225C167DF9EE4CCB4D3C/libraries/ESP32-audioI2S-master/Audio.cpp.o:(.literal._ZN5Audio15setDecoderItemsEv+0x24): undefined reference to `FLACGetChannels()'
/Users/alexsouza/Library/Arduino15/packages/esp32/tools/xtensa-esp32s3-elf-gcc/esp-2021r2-patch5-8.4.0/bin/../lib/gcc/xtensa-esp32s3-elf/8.4.0/../../../../xtensa-esp32s3-elf/bin/ld: /private/var/folders/j0/_j5h8rw161l2lrx2khy0_2wh0000gn/T/arduino/sketches/A467C159EA95225C167DF9EE4CCB4D3C/libraries/ESP32-audioI2S-master/Audio.cpp.o:(.literal._ZN5Audio15setDecoderItemsEv+0x28): undefined reference to `FLACGetSampRate()'
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

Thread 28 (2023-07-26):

Power can't be turned off

FrantisekBeranek, 2023-07-26:
- You can't turn power off because Q2 is not connected properly (Drain and Source are swapped). It means that V_BAT is still on thru internal diode of this transistor when you set pin PWR_ON to 0.
- The resistor RQ is not wired properly. It should be connected to BAT not V_BAT so it still keep Gate of Q2 high when power is off.
- Voltage divider for BAT_ADC should not (in my opinion) be connected to BAT directly because if you would be able to turn MCU down you can possibly destroy your ADC input by applying voltage in it without power. Also it drains your battery constantly (current is small but it is there).
- There is no other option to power up the board than to connect USB (you apply VBUS on Q3 which starts U4). Of corse it's not problem when you can't turn the board off but I think button in parallel with Q5 would be nice.
- Applying VBUS to Gate of Q3 actualy closes the transistor so U4 is powered from VBUS and then from V_BAT as mentioned above.
- It seems to me that VBAT and BAT should be the same net.

I can be wrong in any of these, so please don't be angry for useless issue.

lewisxhe, 2023-07-27:
Thanks for your feedback, I will give feedback to the hardware engineer responsible for this project.

lilysam23, 2023-08-13:
T-embed esp32 s3 bilgisayara taktım ve açılmımamaya başladı

radimsejk, 2023-10-18:
@lewisxhe How is this completed? What is the result please?

lewisxhe, 2023-10-18:
I have given feedback to the hardware and this issue can be closed.

Closed 2023-10-18.

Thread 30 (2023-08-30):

Is it possible to power the board from the 3V3 grove connector pin?

lesept777, 2023-08-30:
Is it possible to power the board from the 3V3 grove connector pin?

lewisxhe, 2023-09-02:
Yes .Can provide about 300mA current

Closed 2023-10-18.

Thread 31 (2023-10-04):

Has anyone had trouble compiling factory.ino ?

pganson, 2023-10-04:
I'm struggling to get this sketch to compile successfully:

- C:\P\data\programming\Arduino\T-Embed-factory/app_controller.cpp:224: undefined reference to `lv_event_get_msg'
- C:\P\data\programming\Arduino\T-Embed-factory/T-Embed-factory.ino:647: undefined reference to `lv_msg_send'

lewisxhe, 2023-10-18:
lv_msg_send is enabled in [lv_conf.h](https://github.com/Xinyuan-LilyGO/T-Embed/blob/50faf3ed2911faf423489a9e3045e45eb219f808/lib/lvgl/lv_conf.h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)

Have you changed the version of lvgl?

pganson, 2023-10-18:
This was my error.  You can close this issue.

Closed 2023-10-18.

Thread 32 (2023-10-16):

Problem with flashing firmware.bin using Espressif tool

pganson, 2023-10-16:
I downloaded the Espressif flash download tool, v3.9.4 and the T-Embed project from this github repository.  I am able to use the "erase" button and also to flash the firmware.bin file to my T-Embed.

But, then when I reboot the T-Embed, I get "Invalid header: 0xFFFFFFFF" continuously on the serial output from the T-Embed.  The T-Embed appears to be in a reboot loop; the USB device on my computer keeps disconnecting and re-connecting.

lewisxhe, 2023-10-18:
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
Are the settings the same?

pganson, 2023-10-18:
Yes, my settings are the same as instructed.

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

lewisxhe, 2023-10-19:
You did not check the firmware you need to burn.
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

pganson, 2023-10-30:
I'm getting a timeout during the download of the firmware.bin image to the T-Embed.  I've tried changing the baud rate (all the way to 115200) but it has no effect.  I also tried two different ports on my laptop - USB-A and USB-C.

Do you have any ideas for something else to try ?

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

NaegeliJ, 2024-05-12:
Hi @pganson, I encountered the same issue. Espressif released an updated version of their firmware flash tool which resolved the problem for me. You can download it here: [Espressif Flash Download Tool 3.9.6](https://www.espressif.com/sites/default/files/tools/flash_download_tool_3.9.6_1.zip). Hope this helps

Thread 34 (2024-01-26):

GPIO Pinout reference

DMFSouza, 2024-01-26:
I recently acquired a T-Embed, but when trying to add an RC522 module, I came across this doubt: how do I reference the GPIO pins? Which numbering corresponds to the MISO, CLK, and SDA pins? I searched the manual, but the numbering doesn't seem to be correct. Thank you very much for your attention and time in advance!
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

lewisxhe, 2024-01-27:
If you need to use this SPI, then there is a problem. This hardware design does not reserve an extra free CS pin. You need to connect CS to GPIO 44 or 43.
Regarding which MISO MOSI and SCK are SPI, you can see here.
https://github.com/Xinyuan-LilyGO/T-Embed/blob/606694fd07a5bf377caef45fe7fd5685549bc3e1/examples/CC1101_Receive/TFTHelper.h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

reviwer-ai, 2025-06-03:
> 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 Is this OK? 16, 17 are free, MISO, MOSI, SCK are SPI bus

I am using bruce firmware on t embedded can you please write the connection digram EBYTE E07-433M20S Ebyte CC1101 Module, SMD Long Range Wireless RF Transceiver Module please full connection

lewisxhe, 2025-06-03:
I can only provide the corresponding locations of these IOs. Please check other modules yourself.

reviwer-ai, 2025-06-03:
> I can only provide the corresponding locations of these IOs. Please check other modules yourself.

Can you tell the pin connections and where it located I dont want to disable sd card slot
Miso
Mosi
Sck
Cs i didnot find it
Gdo0 irq slots can you mark where it located

lewisxhe, 2025-06-03:
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

I think it is explained here Using GPIO 43,44

reviwer-ai, 2025-06-03:
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

Can you tell the spi pins connections
Without modification the firmware

reviwer-ai, 2025-06-03:
> You need to check the source code of Bruce firmware. I don't know much about Bruce.

Can you tell me the sd card slot connection I am confused sd card have 7 pins witch pin is cs  sclk mosi miso can you give me image diagram

reviwer-ai, 2025-06-03:
> You need to check the source code of Bruce firmware. I don't know much about Bruce.

> > 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 Is this OK? 16, 17 are free, MISO, MOSI, SCK are SPI bus
>
> I am using bruce firmware on t embedded can you please write the connection digram EBYTE E07-433M20S Ebyte CC1101 Module, SMD Long Range Wireless RF Transceiver Module please full connection

Can you give the sd card slot diagram like this photo I want to see the diagram

reviwer-ai, 2025-06-03:
> 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

Not like this like the pic you sent earlier

lewisxhe, 2025-06-03:
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

reviwer-ai, 2025-06-08:
> 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

Can you give me the antenna pcb where does the antena come from photo give me diagram like this

reviwer-ai, 2025-06-09:
> There is no antenna on the embed board, only an antenna on the esp module. What do you mean?

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
I mean I broke this pin I marked and my t embedded not detecting wifi networks and I want to know where I can attach the external antena and give me your instagram id so I can give you more reason

lewisxhe, 2025-06-09:
<!-- Failed to upload "image.png" -->
This metal solder joint is the antenna outlet. This is the ESP32 module. It is not our board. This is from Espressif. If the module is not damaged, it should work.
Sorry, I don't have Instagram

reviwer-ai, 2025-06-09:
> This metal solder joint is the antenna outlet. This is the ESP32 module. It is not our board. This is from Espressif. If the module is not damaged, it should work. Sorry, I don't have Instagram

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

This is my t embedded and this is the condition of the antena I am saying how to attach antenna on this the pcb is damaged and the solder is gone cause heat

lewisxhe, 2025-06-10:
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

Oh my goodness.
Maybe you can try soldering the antenna to this capacitor. Solder the shield to GND
If that doesn't work then it's probably damaged.

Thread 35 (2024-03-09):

Encoder instability

DelusionalLogic, 2024-03-09:
I'm seeing some encoder instability. It looks to be triggering when I touch it, and quite noisy when I rotate it (only on one of the sensors though). This causes it to sometimes misfire in reverse (like a mouse wheel going bad) or skip steps.

Is this expected or a bad encoder? can I somehow fix it myself?

IgnasFalcon, 2025-04-18:
Me too! Mine slips every about 7 turns on the first day I got it.
(T-Embed CC1101)

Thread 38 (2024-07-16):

Readme for Arduino Quick Start Doesn't Work for Newer IDE

mrmonteith, 2024-07-16:
On the T-Embed - Readme under Quick Start - Arduino the instructions do not work on the new versions of the IDE.
[T-Embed](https://github.com/Xinyuan-LilyGO/T-Embed)
 It seems to go through the steps to install.  The search fails
Search for ESP32 in Tools->Board Manager and install ESP32-Arduino SDK

 Is this the one that is needed now?
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

LilyGO, 2024-07-17:
Yeah, that's it.

mrmonteith, 2024-07-19:
Thanks.  I supposed the next line "Copy all files in the lib folder to \Arduino\libraries" doesn't apply?  Seeing there is no lib folder.  Needs to explain where lib is.  Thanks

Closed 2024-07-19.

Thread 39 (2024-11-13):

Missing slim shell stl file

jrbecart, 2024-11-13:
You have a picture on the product page showing a slim shell version.

Can you add the stl file ?

Ref:
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

Url: https://lilygo.cc/products/t-embed

lewisxhe, 2024-11-13:
Already added

Closed 2024-12-10.

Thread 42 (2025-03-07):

Screen does not work with Adafruit

vovka36, 2025-03-07:
Hi everyone.
Screen does not working with Adafruit library or I cant to do it...
Can you write me an _working_ example with Adafruit ST7789?

vovka36, 2025-03-09:
```
#include <Adafruit_GFX.h>
#include <Adafruit_ST7789.h>
#include <SPI.h>

#define TFT_CS     10
#define TFT_DC     13
#define TFT_RST    9

#define POWER_PIN  46
#define BRIGHTNESS_PIN 15

Adafruit_ST7789 tft = Adafruit_ST7789(TFT_CS, TFT_DC, TFT_RST);

void setup() {
  pinMode(POWER_PIN, OUTPUT);
  digitalWrite(POWER_PIN, HIGH);
  pinMode(BRIGHTNESS_PIN, OUTPUT);
  digitalWrite(BRIGHTNESS_PIN, HIGH);
//!!!!!!!!!!!!!!!!!!!!!!!!!!!!!!!!!!!!!!!!!!!!!!!!!!!!!
  //SPI.begin(TFT_SCLK, TFT_MISO, TFT_MOSI, TFT_CS);
  SPI.begin(12, 43, 11, 10);
//!!!!!!!!!!!!!!!!!!!!!!!!!!!!!!!!!!!!!!!!!!!!!!!!!!!!!
  tft.init(170, 320);
  tft.setRotation(3);
  tft.fillScreen(ST77XX_BLUE);
}

void loop() {
}

```

vovka36, 2025-03-09:
TFT_DC physically is connected to IO13. At the same time IO13 is STANDART GPIO for MISO. There is conflict happened. To prevent this we must change standart SPI GPIO to another unused pin (in my case changed to IO43)
See my example above. I highlighted the important part with exclamation marks

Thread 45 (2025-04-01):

New Display for T-Embedded Compatibility Issue

David-Feldt, 2025-04-01:
I have a T-Embeded V1.2 and ordered a new LCD screen (I broke the old one). I plugged in the ribbon cable and ran the default example and the display is not working. The backlight is working but no actual data. Any help is appreciated.

David-Feldt, 2025-04-01:
I purchased from lilygo, is there any diagnostics I can run?

lewisxhe, 2025-04-02:
T-Embed has two versions, one is T-Emed and the other is T-Embed-CC1101. First, you need to confirm that your version is the current version of this repository.

Then you can directly write [binary firmware](https://github.com/Xinyuan-LilyGO/T-Embed/blob/main/firmware/firmware.bin) to determine whether the board can run normally

https://github.com/Xinyuan-LilyGO/T-Embed/tree/main/firmware

David-Feldt, 2025-04-04:
This worked thanks so much!

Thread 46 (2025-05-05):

Updated sound example

elatour2000, 2025-05-05:
I'm trying to get a sound demo working with my ESP32-S3 board and I'm wondering if there is a updated sound demo that would play an mp3 file from the SD card on the onboard speaker.

lewisxhe, 2025-05-06:
done

Closed 2025-05-07.

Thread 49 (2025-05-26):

LED strip on bruce firmware

igniskarya, 2025-05-26:
Is there anyone who succed installing bruce firmware    on T embed non CC1101 particularly on LED..?
on bruce firmware (pin_arduino.h) using fastLED library but LED doesn't work..

any idea/suggestion guys??

lewisxhe, 2025-05-27:
CC1101 is here.

https://github.com/Xinyuan-LilyGO/T-Embed-CC1101/tree/master/examples/ws2812_test

lewisxhe, 2025-05-28:
Please ask questions in the repository https://github.com/Xinyuan-LilyGO/T-Embed-CC1101/issues

Closed 2025-05-27.

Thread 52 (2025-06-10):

NRF24 on T embed

igniskarya, 2025-06-10:
Hi there.. If iwant to connect NRF24 on my T embed which GPIO PIN should I connect for CE pin & CSN pin?

reviwer-ai, 2025-06-27:
> Hi there.. If iwant to connect NRF24 on my T embed which GPIO PIN should I connect for CE pin & CSN pin?

So do you connected? The nrf 24 module?

lewisxhe, 2025-06-27:
No, but someone has already done that. I have provided the available Pin in that issue. As for connecting the module, you need to verify it yourself. Theoretically, it is feasible.

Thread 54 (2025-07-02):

cc1101 for t embed

igniskarya, 2025-07-02:
hi there...

I want connect cc1101 on my t embed. the cc1101 module like this

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

and if i looked at on example

#define SHIELD_RADIO_CS_PIN                 17
#define SHIELD_RADIO_DIO0_PIN               18
#define SHIELD_RADIO_DIO2_PIN               8
#define SHIELD_RADIO_SW1_PIN                41
#define SHIELD_RADIO_SW0_PIN                43
#define SHIELD_RADIO_RST_PIN                -1

is it possible to use that cc1101 module ?
but I little bit confuse which pin should I connect for
pin GD00, SCk,MOSi,MiSO, GD02

could you give me idea about those pins

igniskarya, 2025-07-04:
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

if looked at on that pin ...
DiO2 pin 8..
I try looking for that pin...in which part pin 8 position?

lewisxhe, 2025-07-08:
Well, no more GPIO, this board wastes a lot of GPIO

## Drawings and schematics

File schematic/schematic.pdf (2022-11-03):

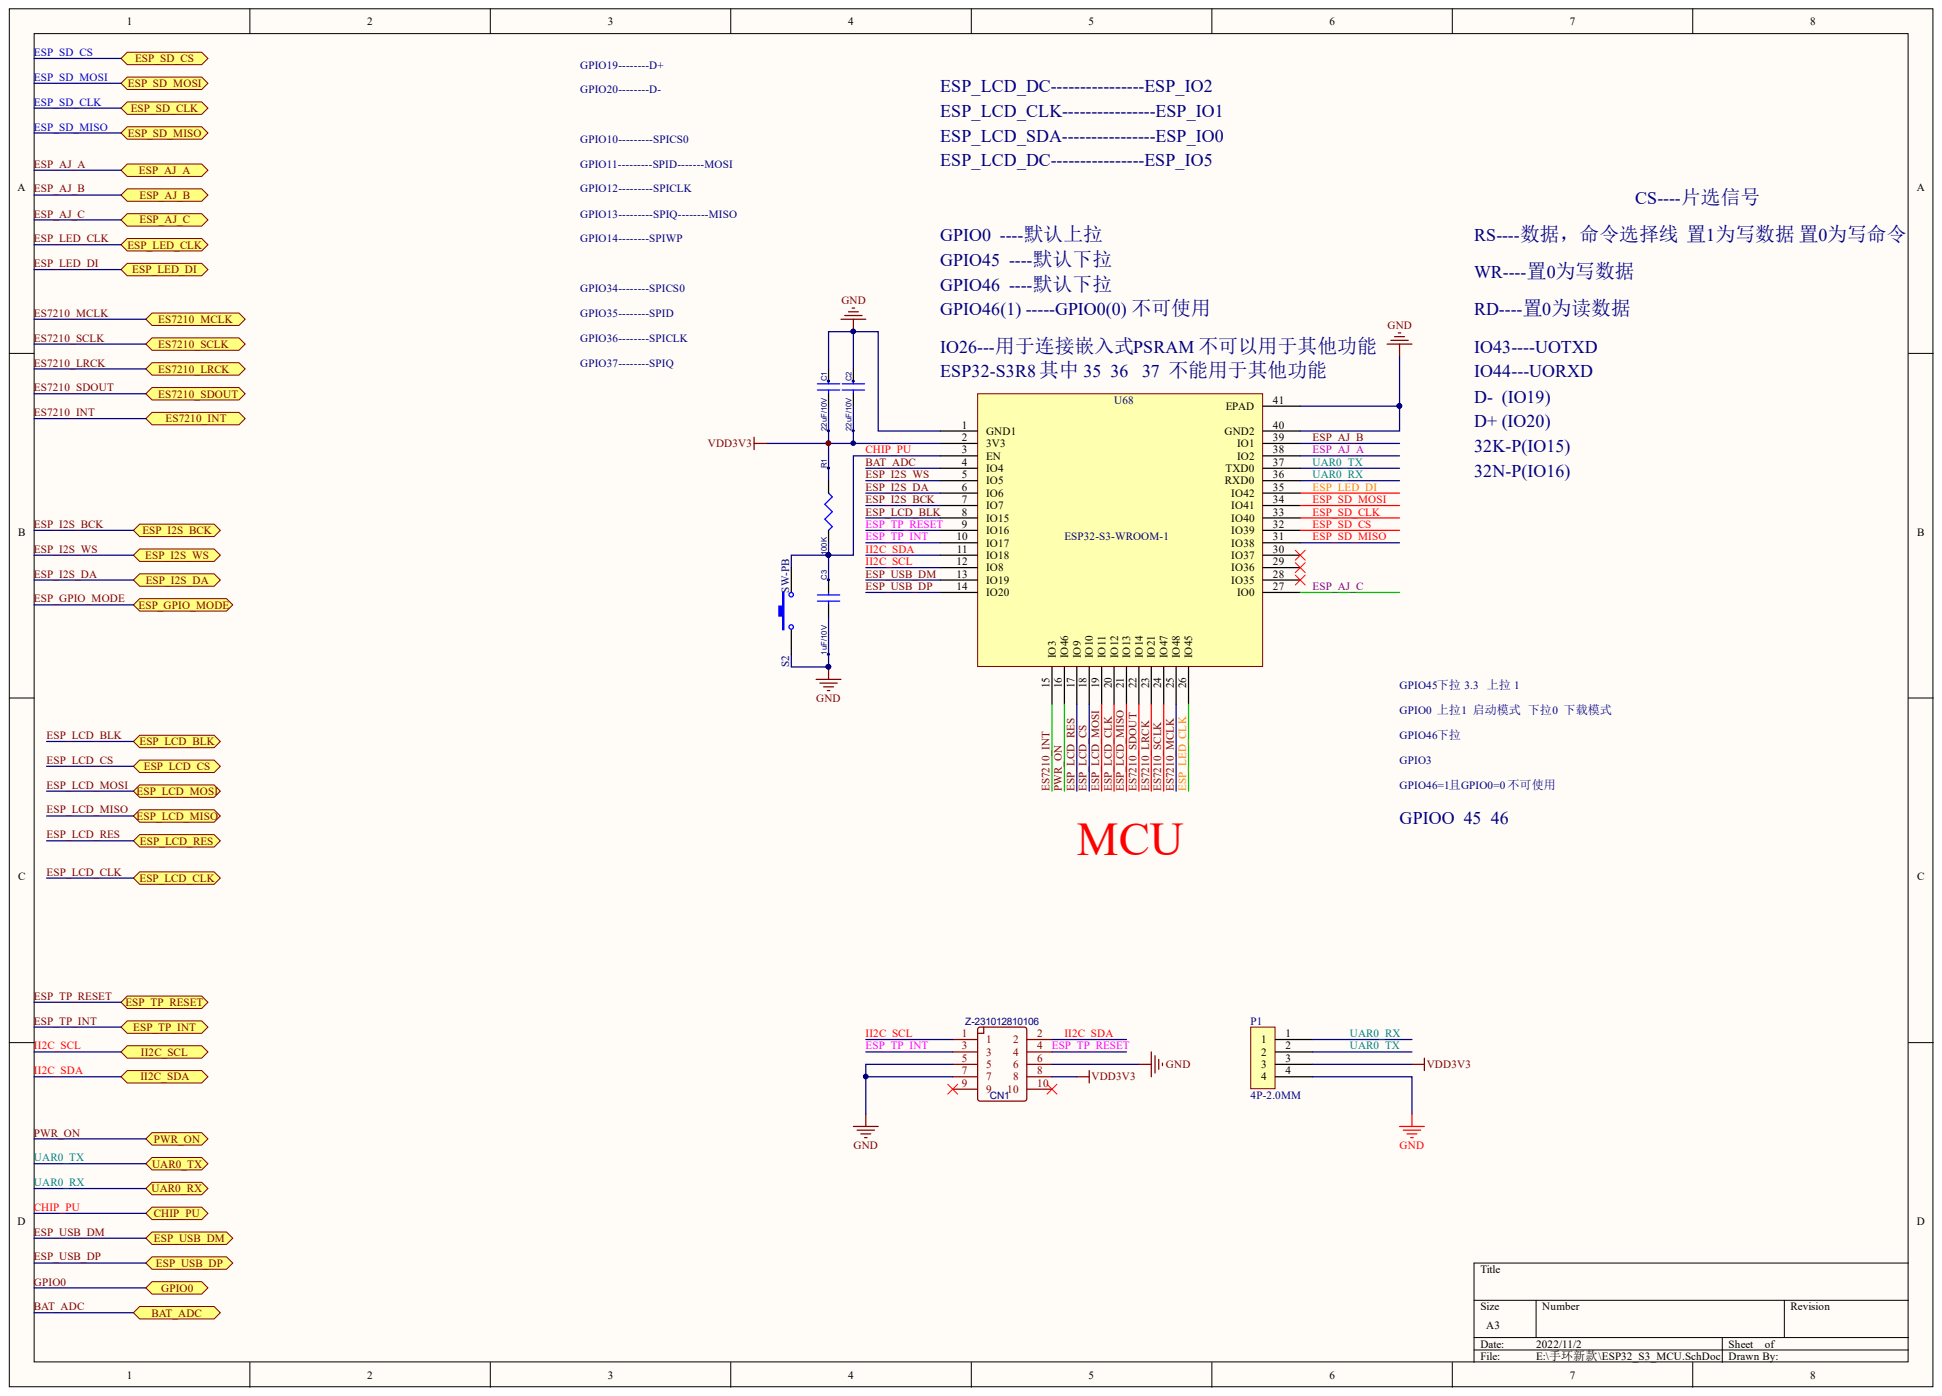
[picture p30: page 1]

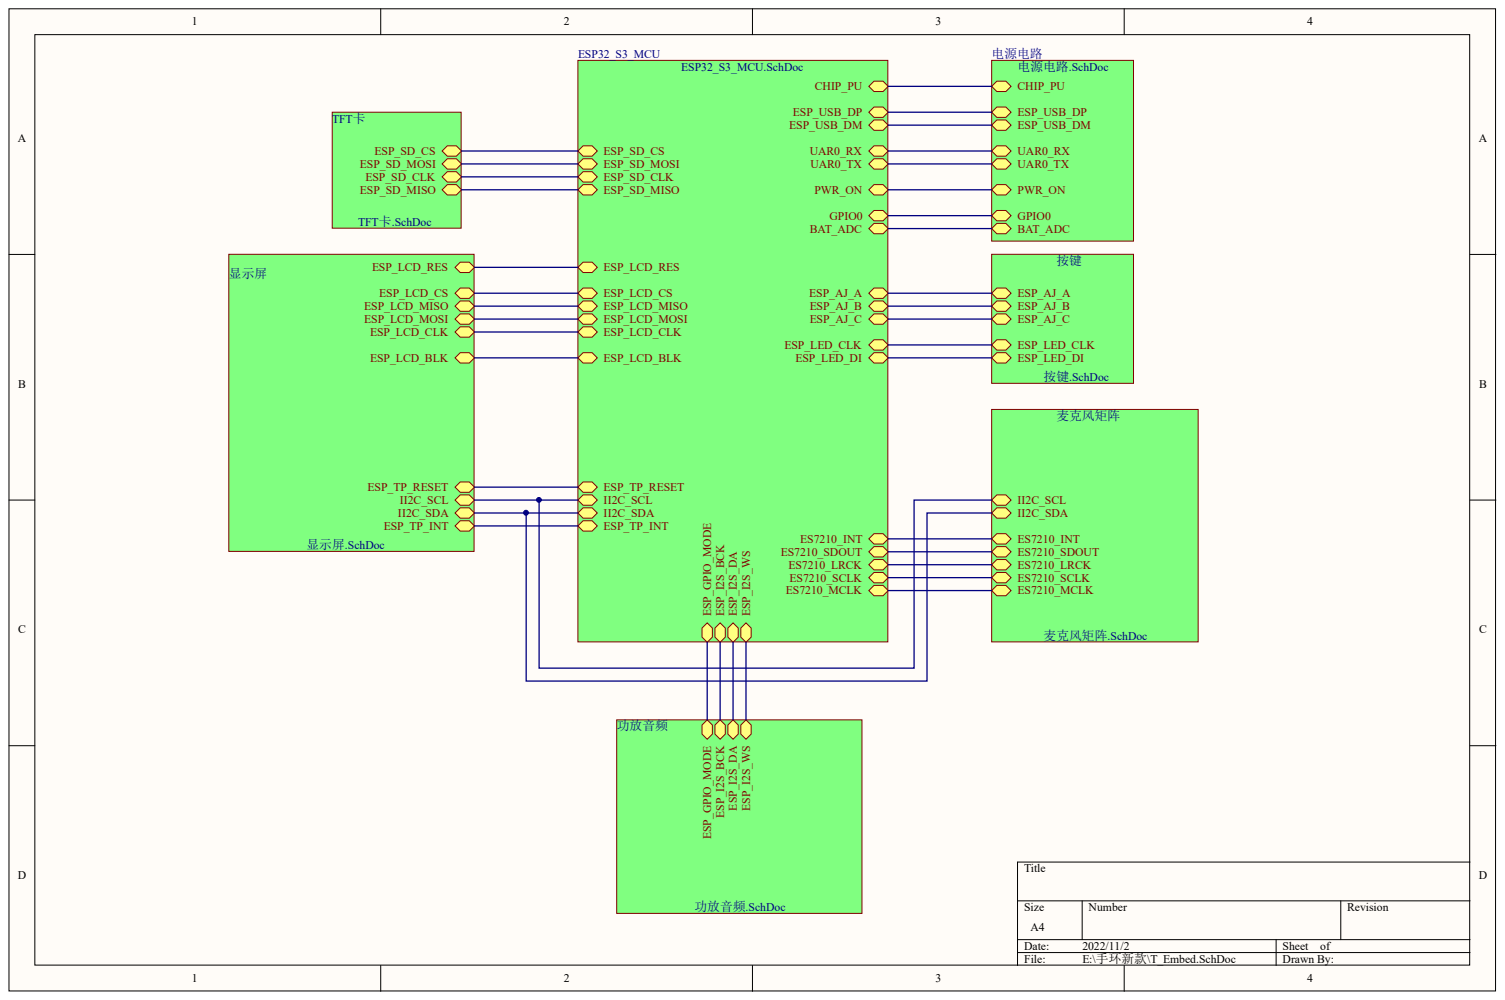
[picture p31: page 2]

II2C_SCL II2C_SDA

ESP_TP_INT ES7210_INT ES7210_SDOUT ES7210_LRCK ES7210_SCLK ES7210_MCLK

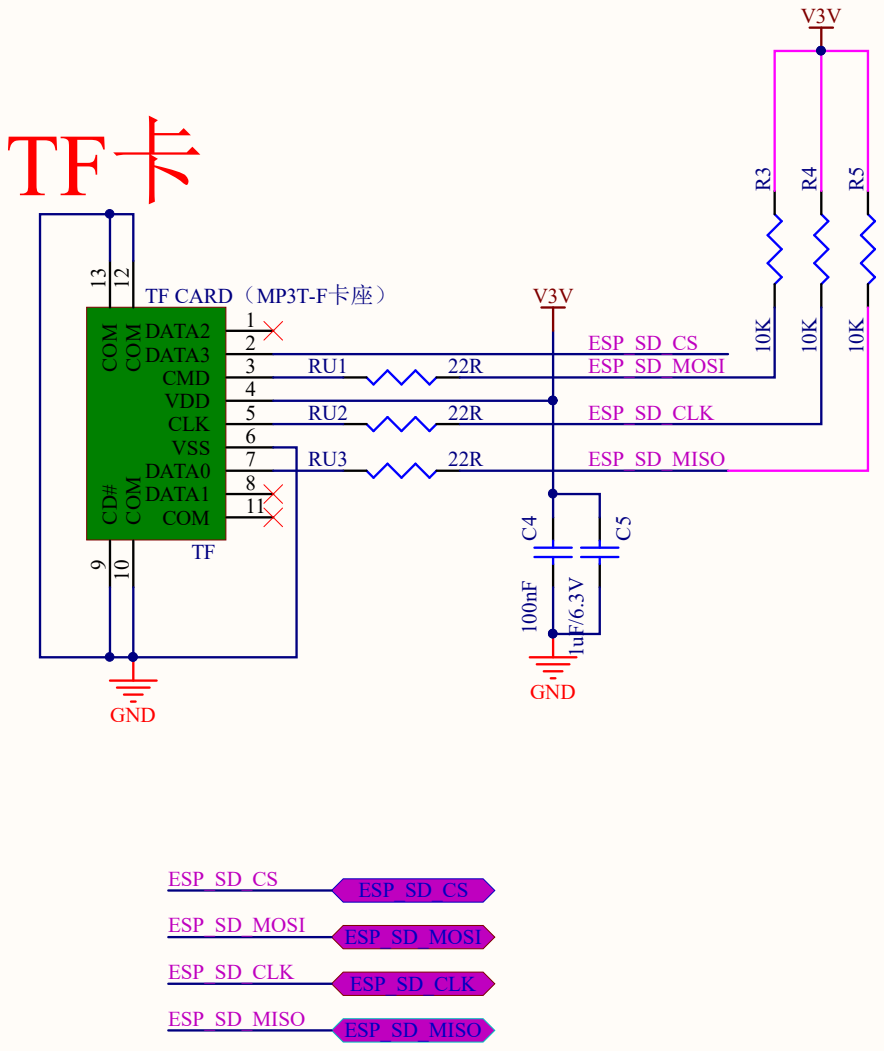
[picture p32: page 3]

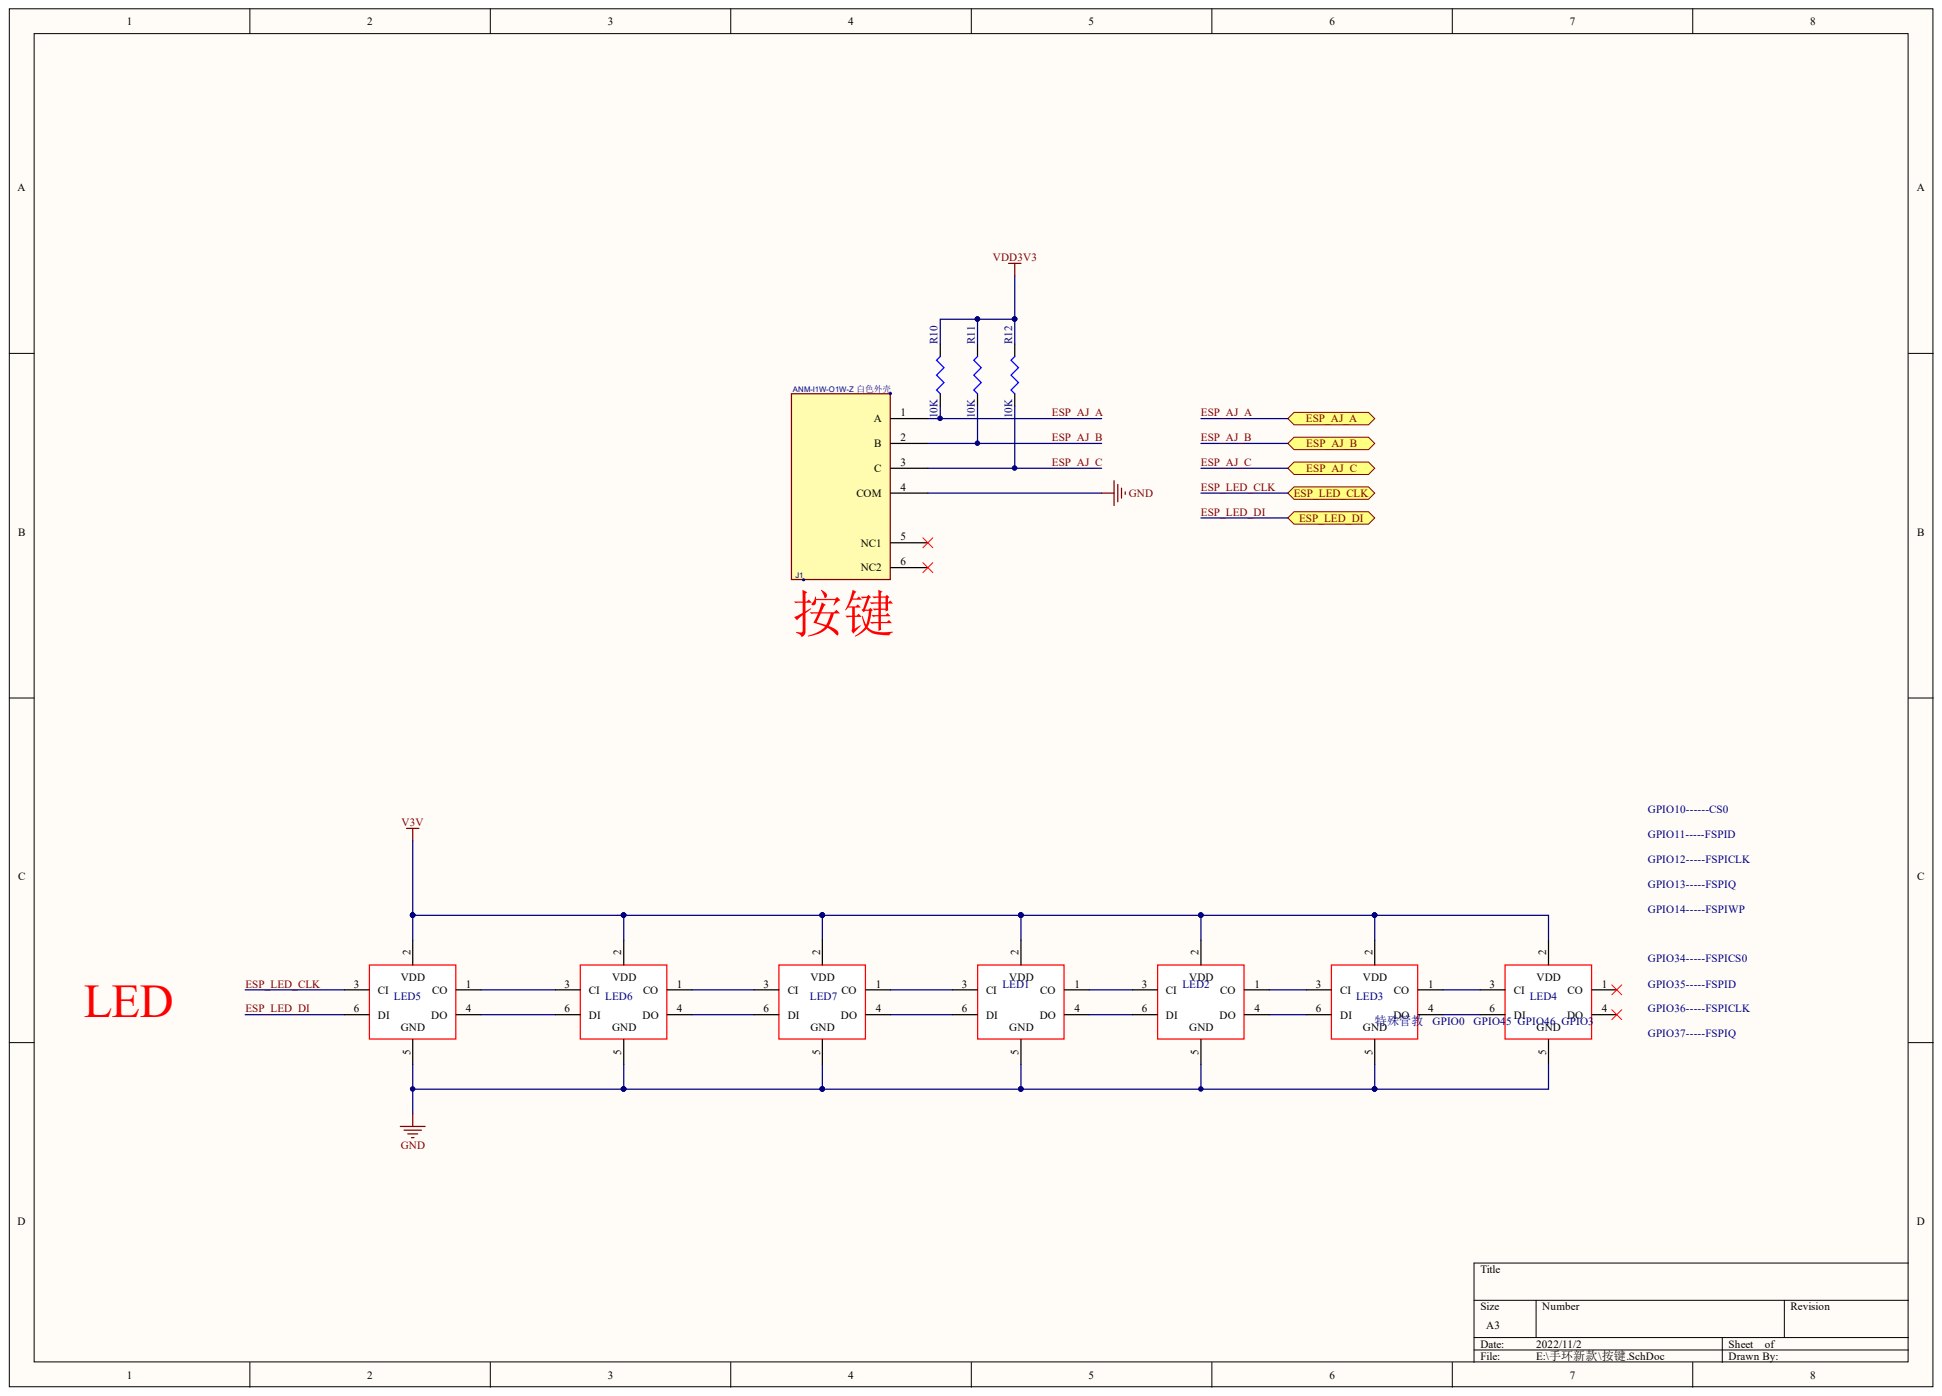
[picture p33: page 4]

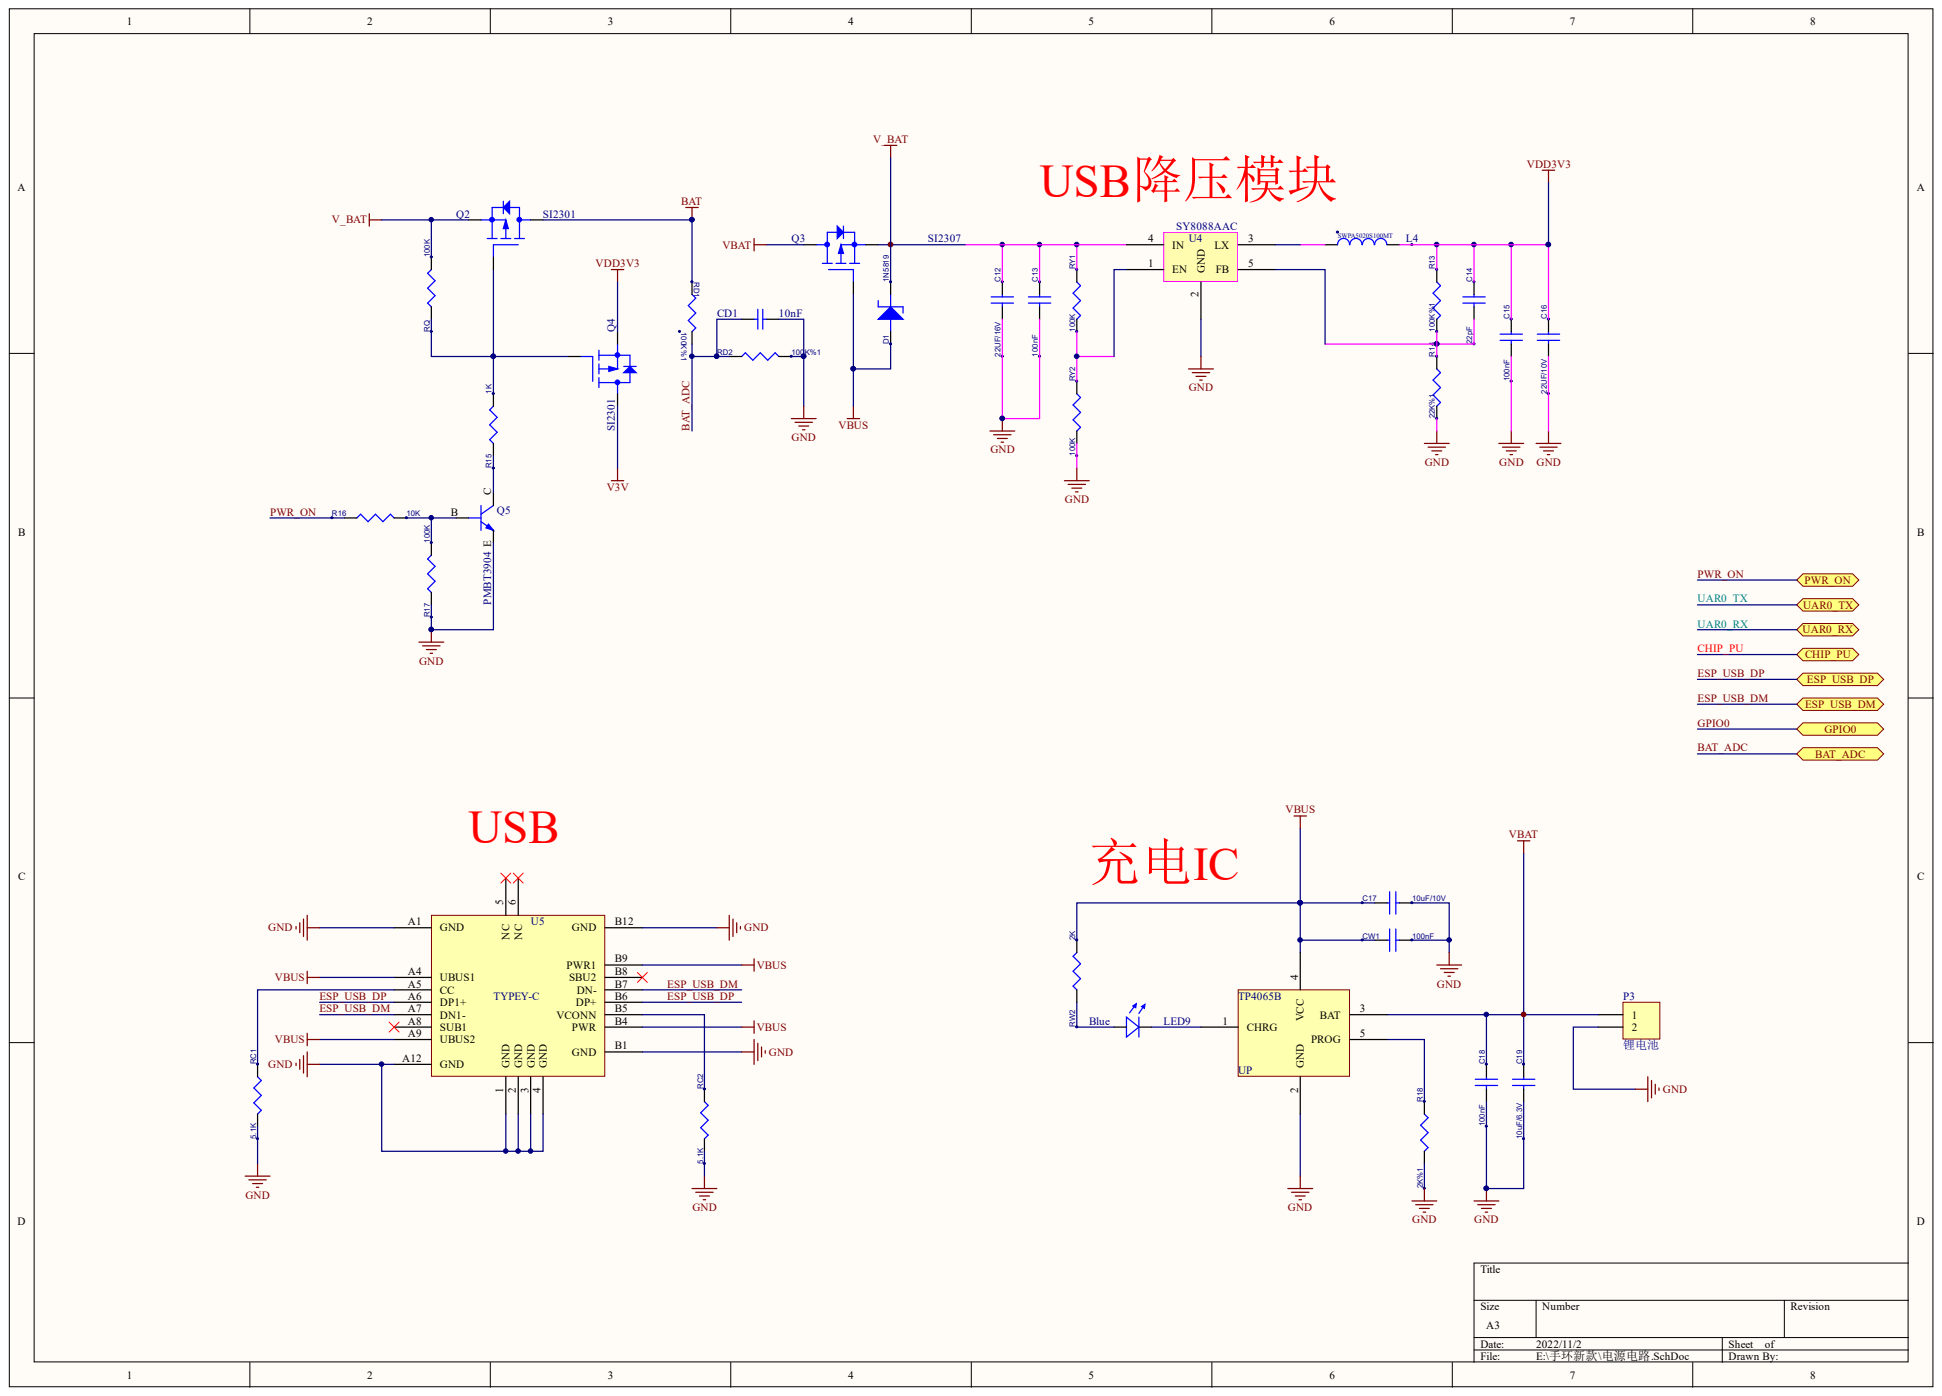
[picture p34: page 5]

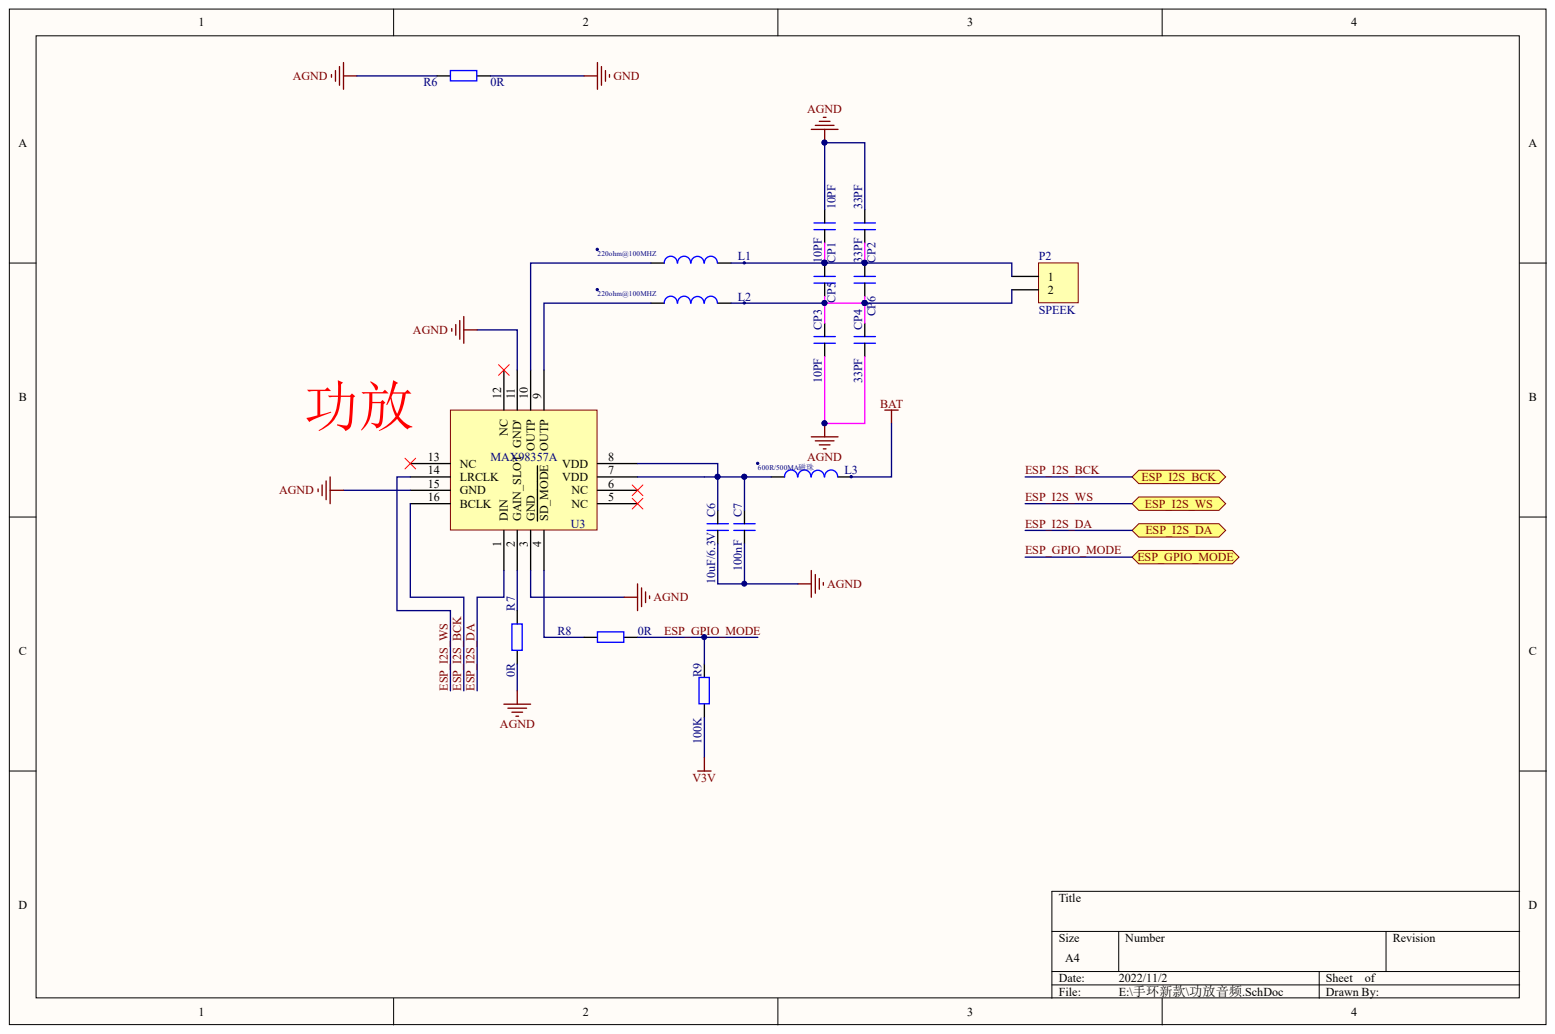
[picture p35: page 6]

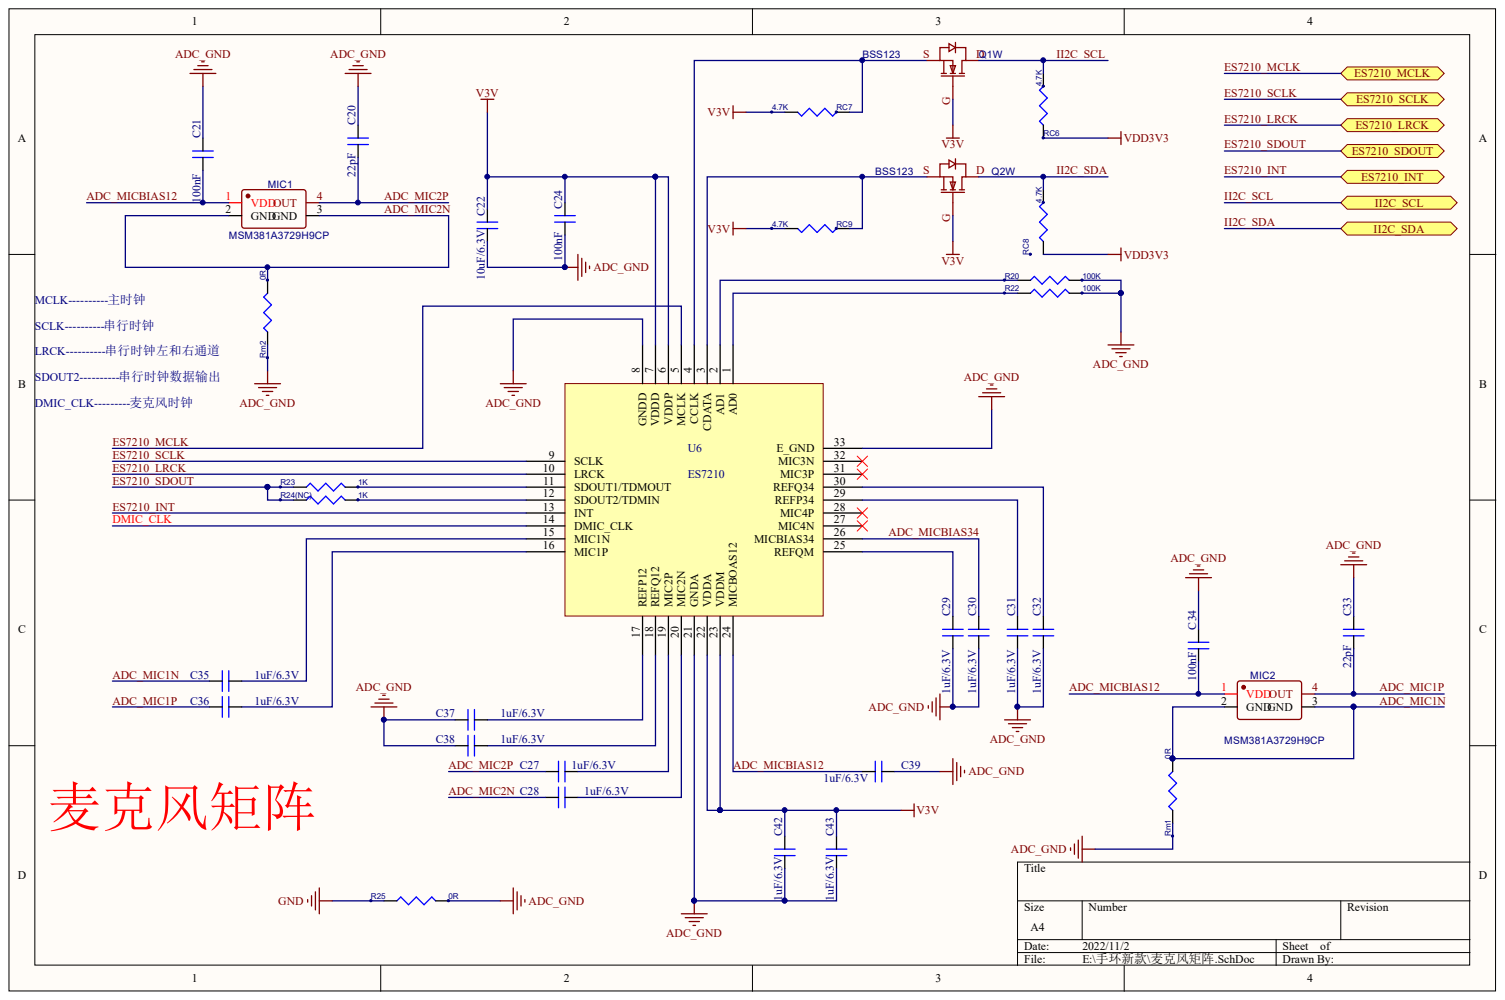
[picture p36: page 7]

AD0 1 AD1 2 CDATA 3 CCLK 4 MCLK 5 VDDP 6 VDDD 7 GNDD 8

ADC_MICBIAS34

MIC1P 16

ADC_GND

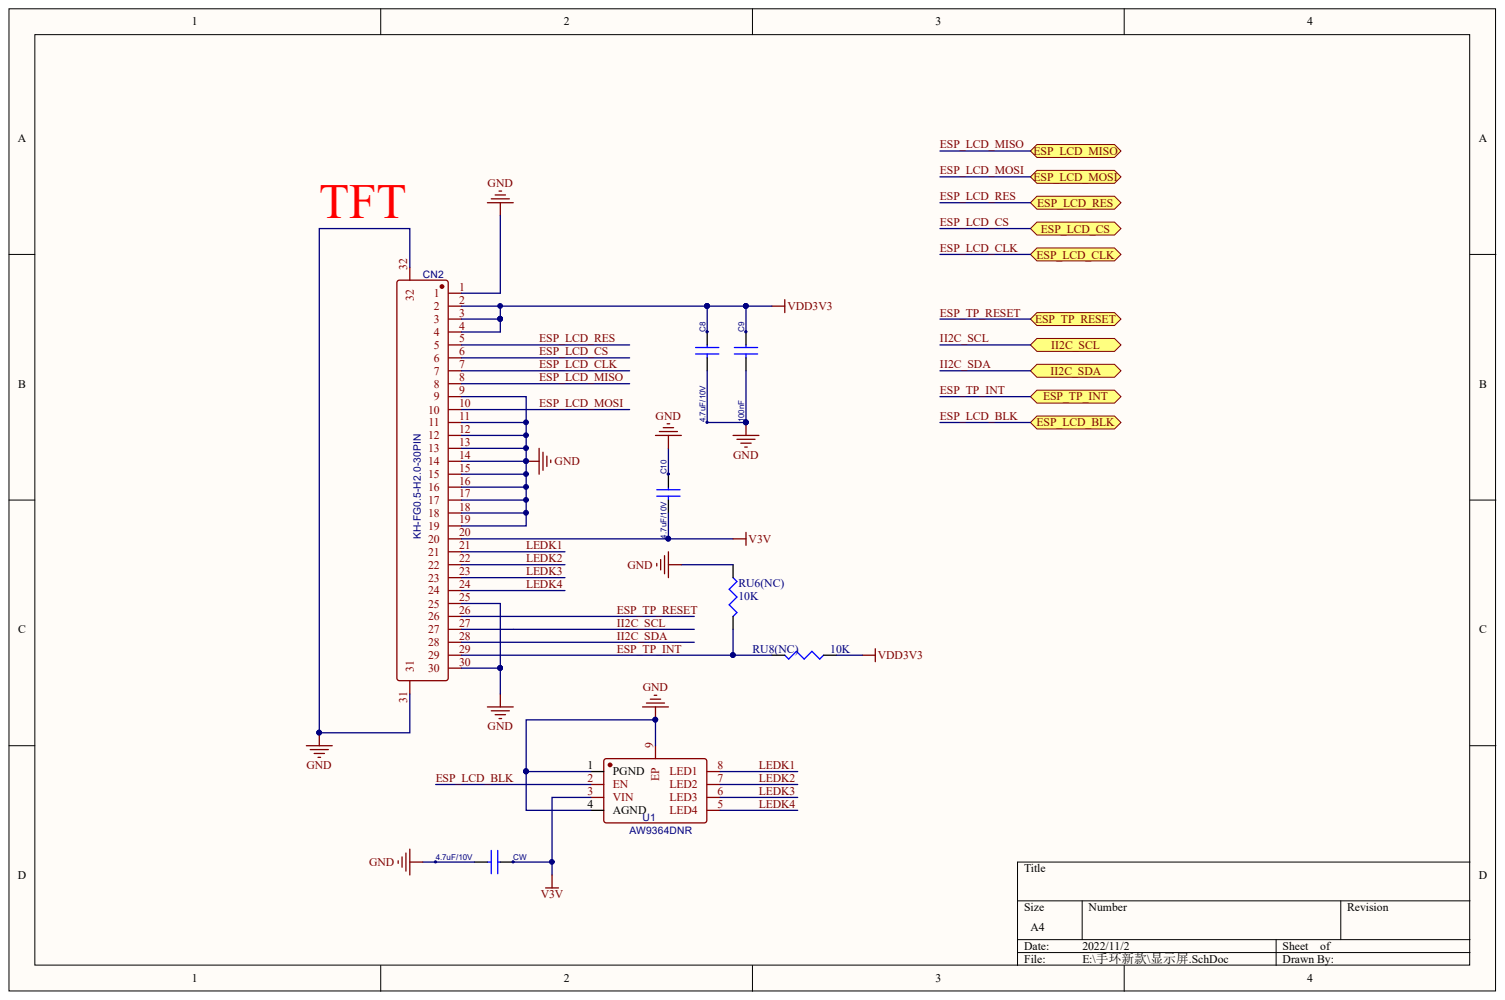
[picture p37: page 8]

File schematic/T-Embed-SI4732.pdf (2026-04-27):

接口

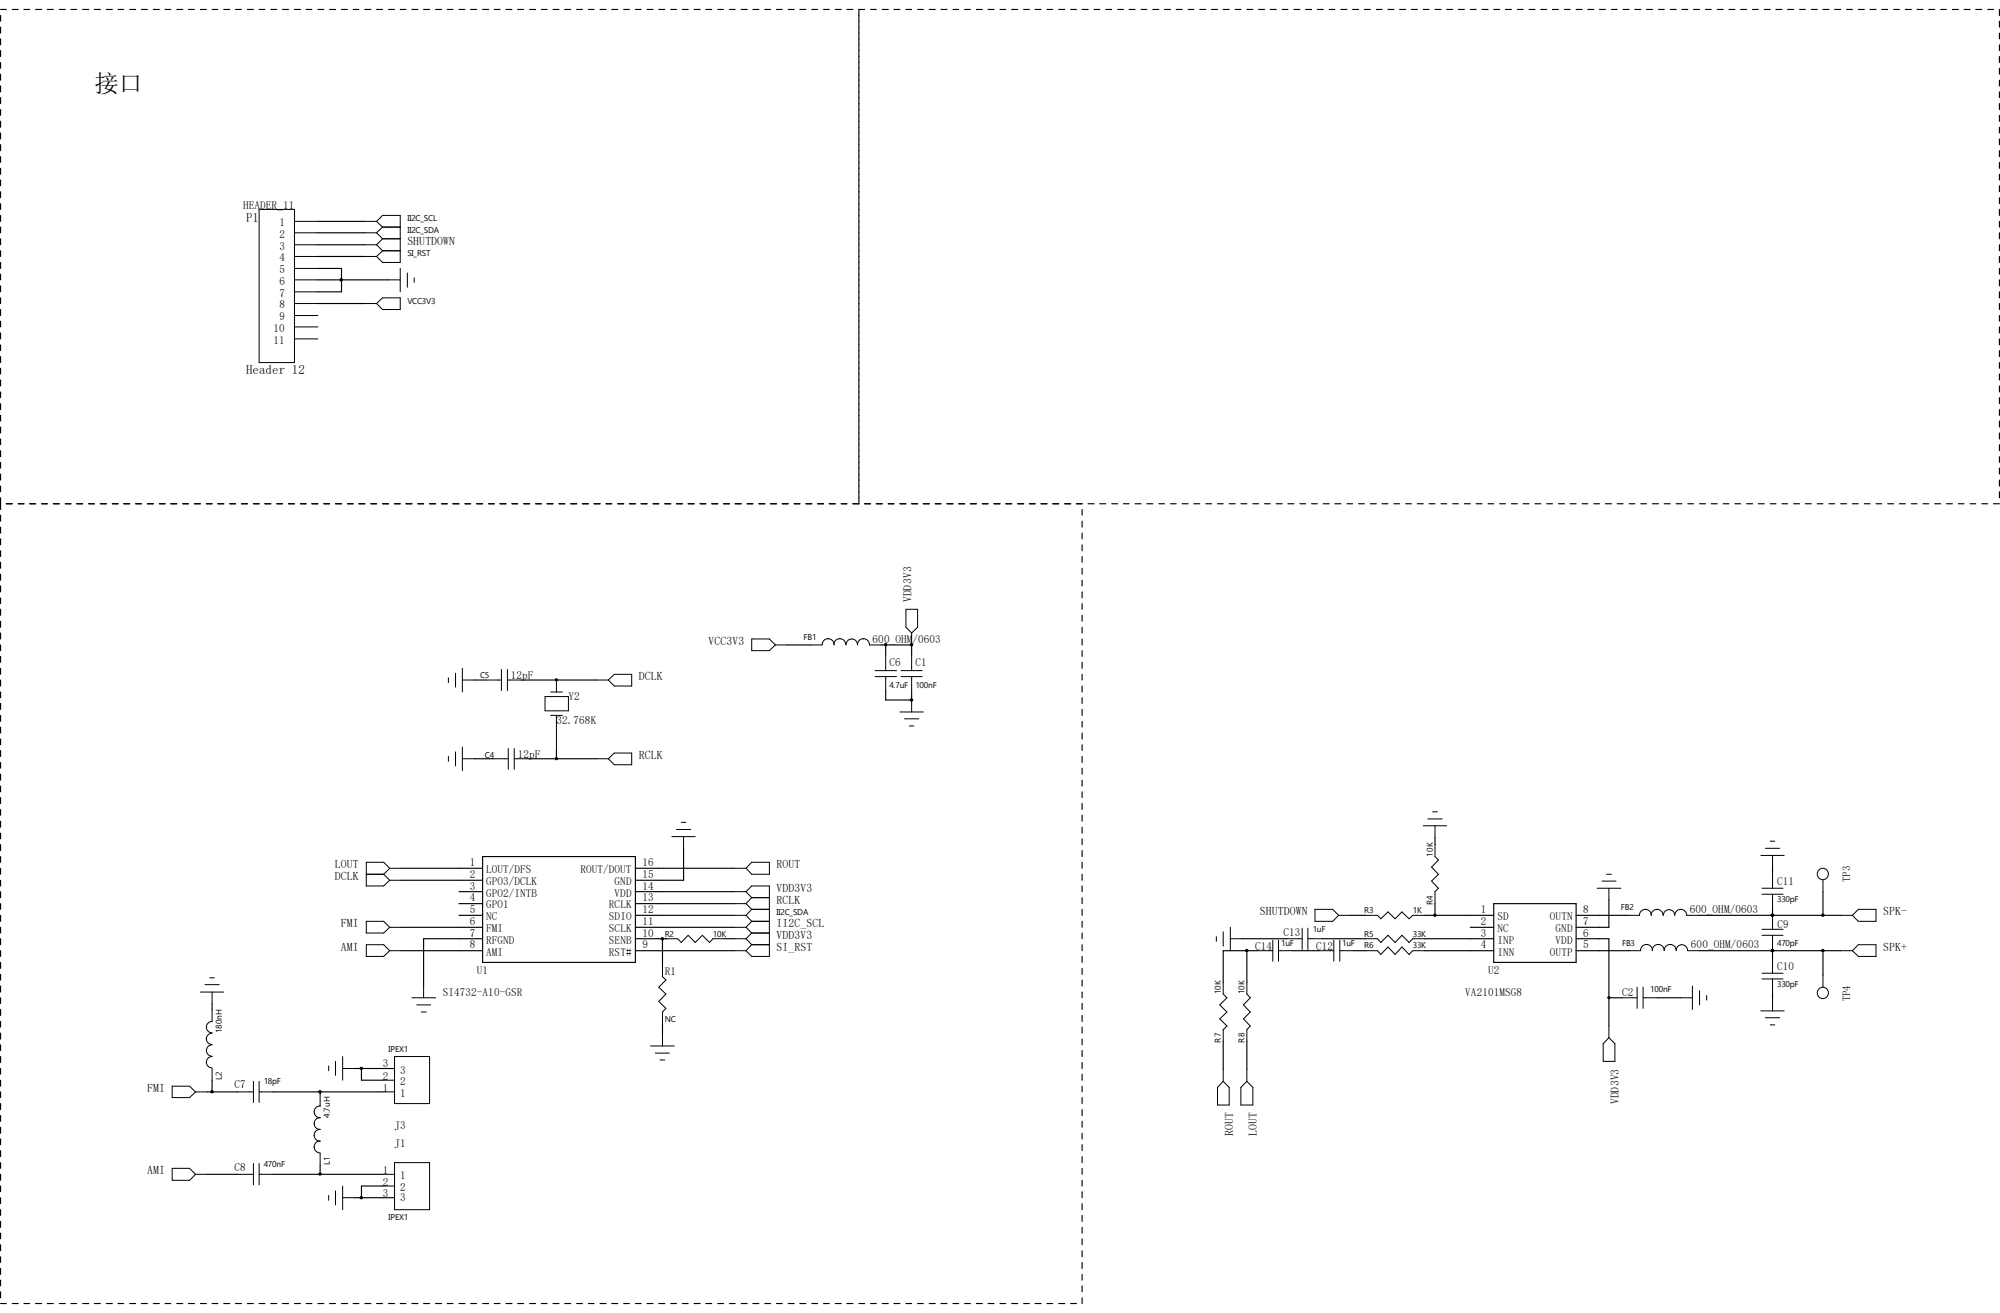
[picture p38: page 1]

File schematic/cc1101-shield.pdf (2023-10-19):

接口

# HPD24A2

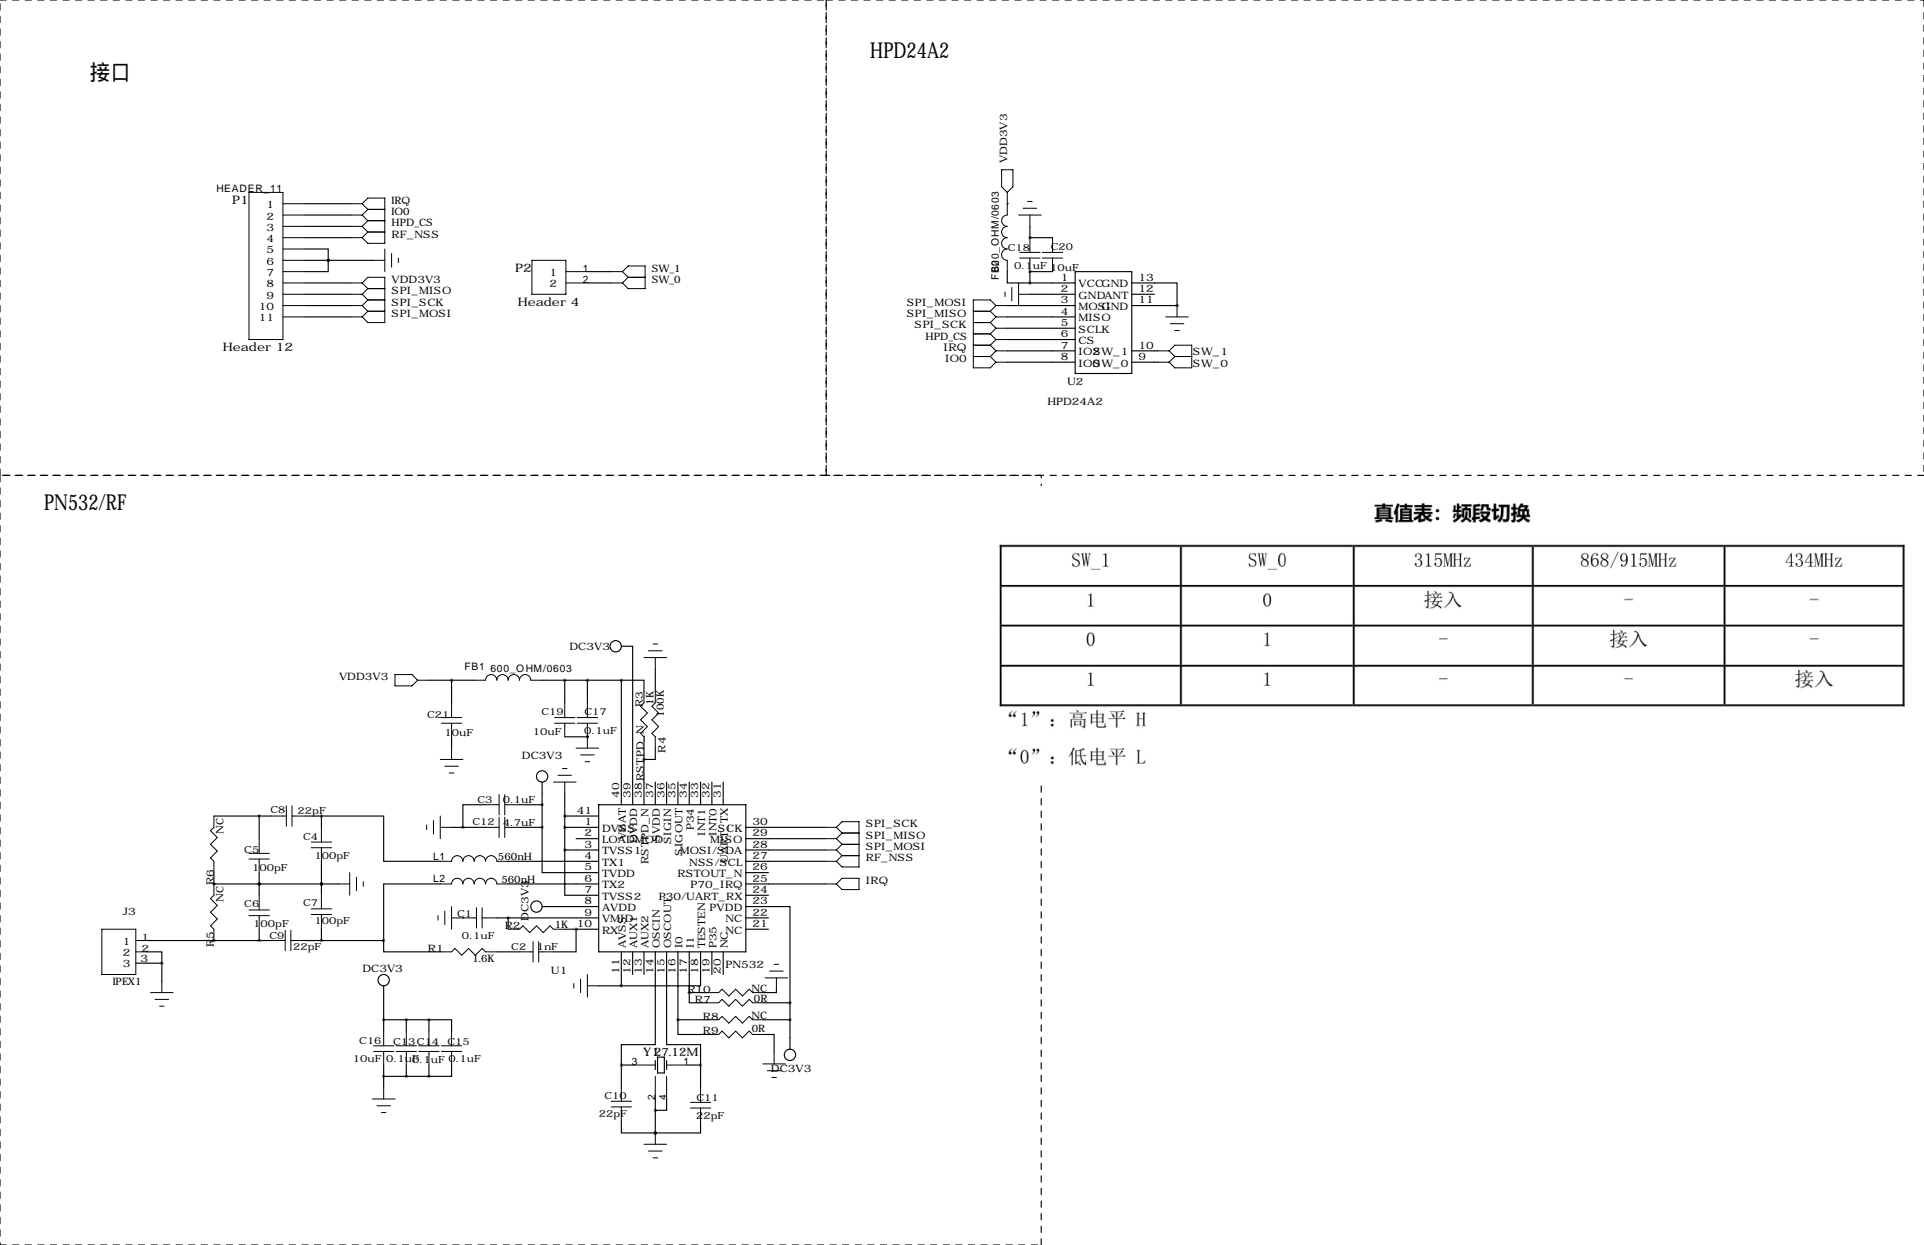
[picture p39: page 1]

TVSS1 4 | 27 NSS/SCL
TX1 5 | 26 RSTOUT_N 25 P70_IRQ

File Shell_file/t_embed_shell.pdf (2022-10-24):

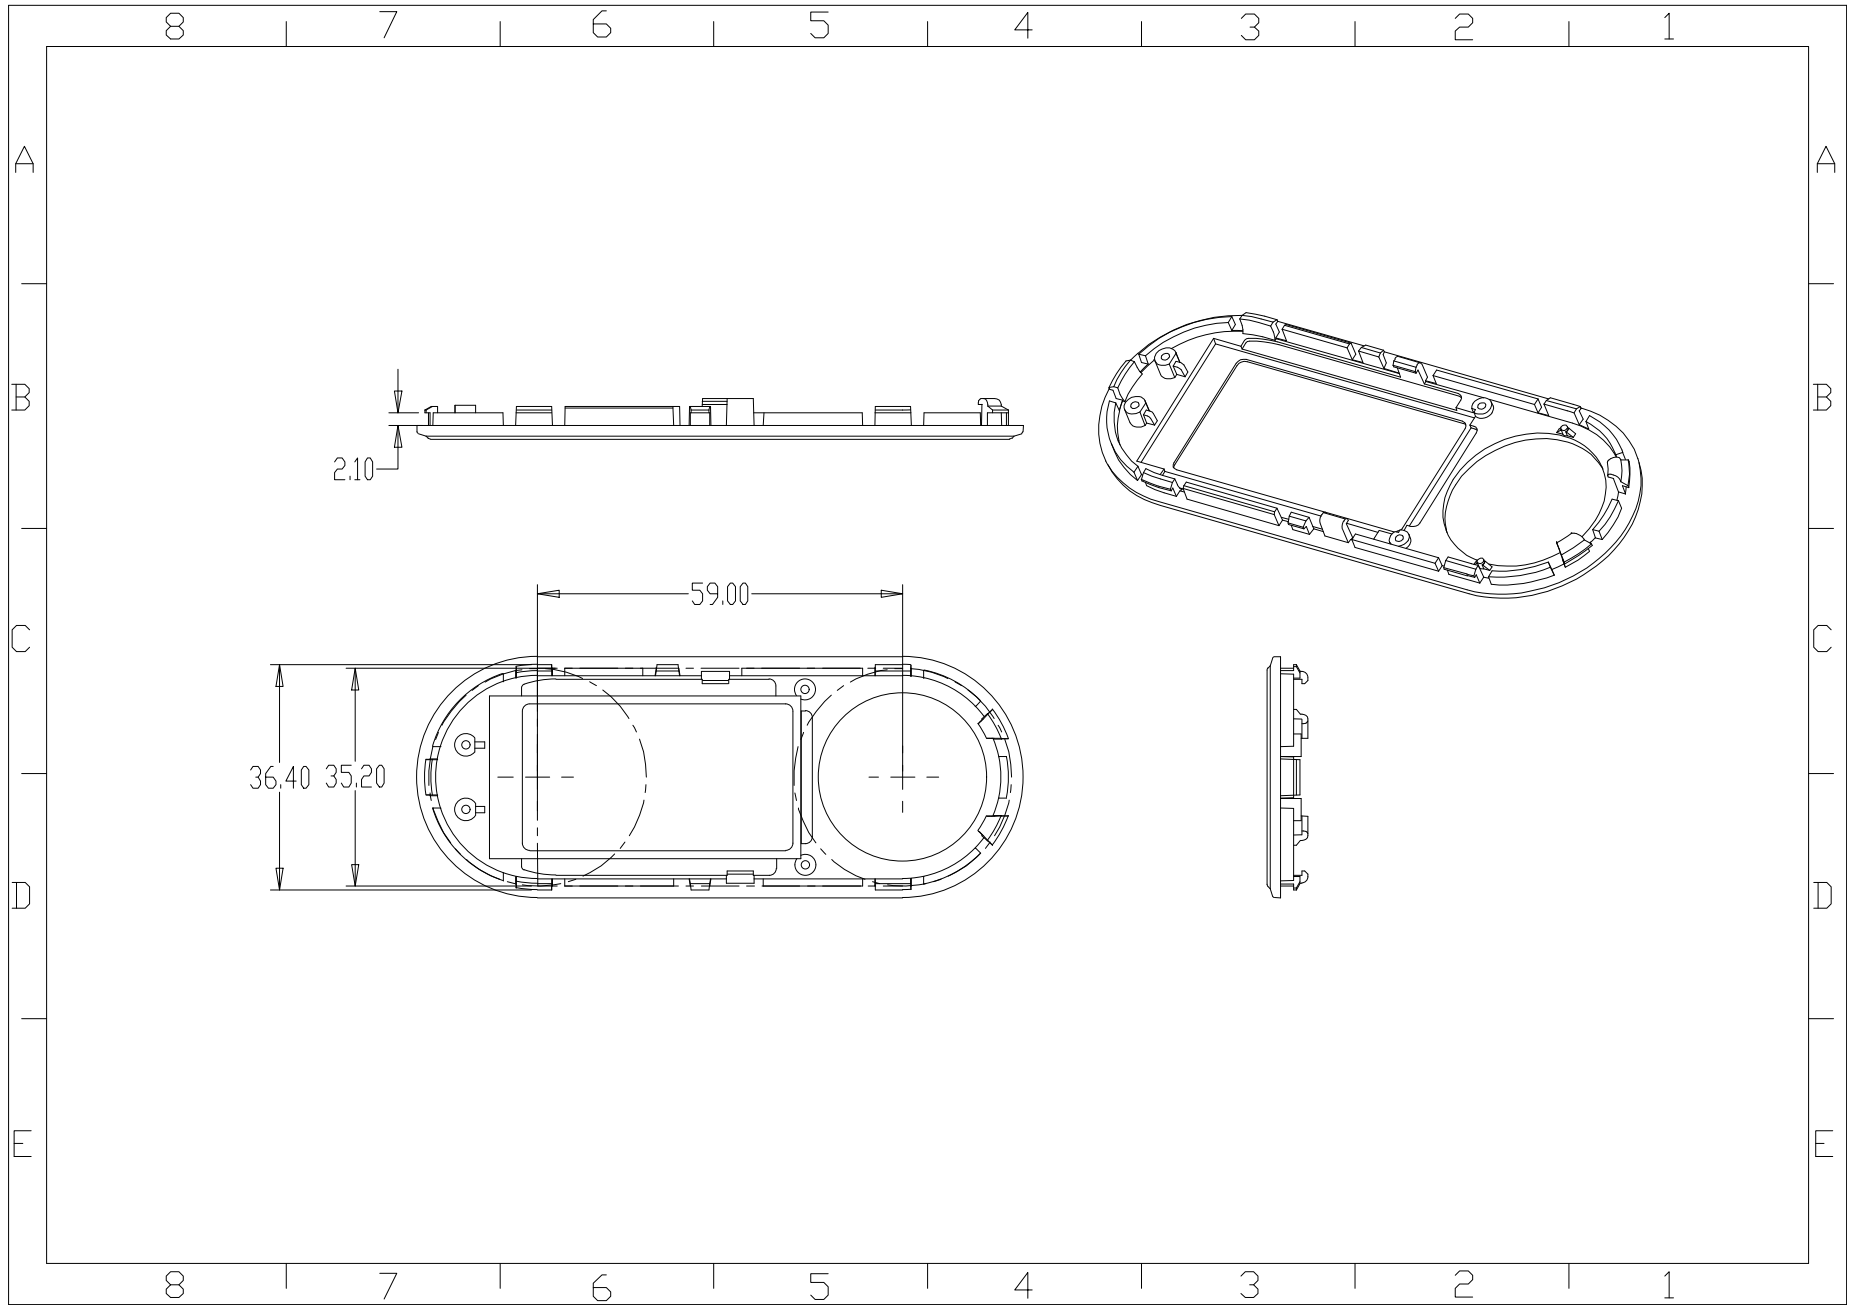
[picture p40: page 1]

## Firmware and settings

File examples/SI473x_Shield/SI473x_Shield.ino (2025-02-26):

/*
  This sketch runs on Lilygo T-Display S3 device (and also T-Embed by changing Pins).

  It is  a  complete  radio  capable  to  tune  LW,  MW,  SW  on  AM  and  SSB  mode  and  also  receive  the
  regular  comercial  stations.

  Features:   AM; SSB; LW/MW/SW; external mute circuit control; AGC; Attenuation gain control;
              SSB filter; CW; AM filter; 1, 5, 10, 50 and 500kHz step on AM and 10Hhz sep on SSB

  Lilygo T-Display S3
  
    |--------------|------------|------------|------------|
    |   Lilygo     |   Si4735   |  Encoder   |   Audio    |
    | T-Display S3 |            |            | Amplifier  |        
    |--------------|------------|------------|------------|        
    |     3V3      |    Vcc     |            |    Vcc     |        
    |     GND      |    GND     |     2,4    |    GND     |        Encoder        1,2,3        
    |     21       |            |     5      |            |        Encoder switch 4,5
    |     16       |   Reset    |            |            |
    |     43       |    SDA     |            |            |
    |     44       |    SCL     |            |            |
    |      1       |            |      1     |            |
    |      2       |            |      3     |            |
    |              |    LOut    |            |    LIn     |
    |              |    ROut    |            |    RIn     |
    |     17 Mute  |            |            |    Mute    |
    |--------------|------------|------------|------------|
  
  
    Lilygo T-Embed
  
    |--------------|------------|------------|
    |    Lilygo    |   Si4735   |   Audio    |
    |   T-Embeded  |            | Amplifier  |
    |--------------|------------|------------|
    |     3V3      |    Vcc     |    Vcc     |
    |     GND      |    GND     |    GND     |
    |              |            |            |
    |     16       |   Reset    |            |
    |     18       |    SDA     |            |
    |      8       |    SCL     |            |
    |              |            |            |
    |              |            |            |
    |              |    LOut    |    LIn     |
    |              |    ROut    |    RIn     |
    |     17 Mute  |            |    Mute    |
    |--------------|------------|------------|
  
  (*1) If you are using the SI4732-A10, check the corresponding pin numbers.
  (*2) If you are using the Lilygo T-Embeded, check the corresponding pin numbers.
  (*3) The PU2CLR SI4735 Arduino Library has resources to detect the I2C bus address automatically.
       It seems the original project connect the SEN pin to the +Vcc. By using this sketch, you do
       not need to worry about this setting.
  Prototype documentation: https://pu2clr.github.io/SI4735/
  PU2CLR Si47XX API documentation: https://pu2clr.github.io/SI4735/extras/apidoc/html/

  By PU2CLR, Ricardo, May  2021.
  Modded by Ralph Xavier, Jan 2023
*/

// SI4735_Shield example form https://github.com/ralphxavier/SI4735
#include <Wire.h>
#include <TFT_eSPI.h>
#include "EEPROM.h"
#include <SI4735.h>
#include <Battery18650Stats.h> // https://github.com/danilopinotti/Battery18650Stats
#include <OneButton.h>  // https://github.com/mathertel/OneButton

#include "Rotary.h"
#include "patch_init.h" // SSB patch for whole SSBRX initialization string

const uint16_t size_content = sizeof ssb_patch_content; // see patch_init.h

#define FM_BAND_TYPE 0
#define MW_BAND_TYPE 1
#define SW_BAND_TYPE 2
#define LW_BAND_TYPE 3

#define PIN_POWER_ON  46
#define PIN_LCD_BL    15
#define RESET_PIN     16           
#define AUDIO_MUTE    17           

// Enconder PINs
#define ENCODER_PIN_A  2           // GPIO01 
#define ENCODER_PIN_B  1           // GPIO02

// I2C bus pin on Lilygo T-Display
#define ESP32_I2C_SDA 18           // GPIO43 
#define ESP32_I2C_SCL 8           // GPIO44

//Battery Monitor
#define VBAT_MON         4                // GPIO04
#define MIN_USB_VOLTAGE  4.9
#define CONV_FACTOR      1.8
#define READS            20

// Buttons controllers
#define ENCODER_PUSH_BUTTON     0     // GPIO21

#define MIN_ELAPSED_TIME         5  //300
#define MIN_ELAPSED_RSSI_TIME  200
#define ELAPSED_COMMAND       2000  // time to turn off the last command controlled by encoder. Time to goes back to the FVO control
#define ELAPSED_CLICK         1500  // time to check the double click commands
#define DEFAULT_VOLUME          35  // change it for your favorite sound volume
#define STRENGTH_CHECK_TIME   1500
#define RDS_CHECK_TIME          90

#define FM  0
#define LSB 1
#define USB 2
#define AM  3
#define LW  4

#define SSB 1

#define VOLUME       0
#define STEP         1
#define MODE         2
#define BFO          3 
#define BW           4
#define AGC_ATT      5
#define SOFTMUTE     6
#define SEEKUP       7
#define SEEKDOWN     8
#define BAND         9
#define MUTE        10

#define TFT_MENU_BACK TFT_BLACK  // 0x01E9
#define TFT_MENU_HIGHLIGHT_BACK TFT_BLUE

#define EEPROM_SIZE        512

#define STORE_TIME 10000 // Time of inactivity to make the current receiver status writable (10s / 10000 milliseconds).

// EEPROM - Stroring control variables
const uint8_t app_id = 47; // Useful to check the EEPROM content before processing useful data
const int eeprom_address = 0;
long storeTime = millis();

bool itIsTimeToSave = false;

bool bfoOn = false;
bool ssbLoaded = false;
char bfo[18]="0000";
bool muted = false;
int8_t agcIdx = 0;
uint8_t disableAgc = 0;
int8_t agcNdx = 0;
int8_t softMuteMaxAttIdx = 4;
uint8_t countClick = 0;

uint8_t seekDirection = 1;

bool cmdBand = false;
bool cmdVolume = false;
bool cmdAgc = false;
bool cmdBandwidth = false;
bool cmdStep = false;
bool cmdMode = false;
bool cmdMenu = false;
bool cmdSoftMuteMaxAtt = false;

bool fmRDS = false;

int16_t currentBFO = 0;
long elapsedRSSI = millis();
long elapsedButton = millis();

long lastStrengthCheck = millis();
long lastRDSCheck = millis();

long elapsedClick = millis();
long elapsedCommand = millis();
volatile int encoderCount = 0;
uint16_t currentFrequency;

const uint8_t currentBFOStep = 10;

char sAgc[15];

const char *menu[] = {"Volume", "Step", "Mode", "BFO", "BW", "AGC/Att", "SoftMute", "Seek Up", "Seek Dn", "Band", "Mute"};
int8_t menuIdx = VOLUME;
const int lastMenu = (sizeof menu / sizeof(char *)) - 1;
int8_t currentMenuCmd = -1;

typedef struct
{
  uint8_t idx;      // SI473X device bandwidth index
  const char *desc; // bandwidth description
} Bandwidth;

int8_t bwIdxSSB = 4;
const int8_t maxSsbBw = 5;
Bandwidth bandwidthSSB[] = {
  {4, "0.5"},
  {5, "1.0"},
  {0, "1.2"},
  {1, "2.2"},
  {2, "3.0"},
  {3, "4.0"}
};
const int lastBandwidthSSB = (sizeof bandwidthSSB / sizeof(Bandwidth)) - 1;

int8_t bwIdxAM = 4;
const int8_t maxAmBw = 6;
Bandwidth bandwidthAM[] = {
  {4, "1.0"},
  {5, "1.8"},
  {3, "2.0"},
  {6, "2.5"},
  {2, "3.0"},
  {1, "4.0"},
  {0, "6.0"}
};
const int lastBandwidthAM = (sizeof bandwidthAM / sizeof(Bandwidth)) - 1;

int8_t bwIdxFM = 0;
const int8_t maxFmBw = 4;

Bandwidth bandwidthFM[] = {
    {0, "AUT"}, // Automatic - default
    {1, "110"}, // Force wide (110 kHz) channel filter.
    {2, " 84"},
    {3, " 60"},
    {4, " 40"}};
const int lastBandwidthFM = (sizeof bandwidthFM / sizeof(Bandwidth)) - 1;



int tabAmStep[] = {1,    // 0
                   5,    // 1
                   9,    // 2
                   10,   // 3
                   50,   // 4
                   100}; // 5

const int lastAmStep = (sizeof tabAmStep / sizeof(int)) - 1;
int idxAmStep = 3;

int tabFmStep[] = {5, 10, 20};
const int lastFmStep = (sizeof tabFmStep / sizeof(int)) - 1;
int idxFmStep = 1;

uint16_t currentStepIdx = 1;


const char *bandModeDesc[] = {"FM ", "LSB", "USB", "AM "};
const int lastBandModeDesc = (sizeof bandModeDesc / sizeof(char *)) - 1;
uint8_t currentMode = FM;


/**
 *  Band data structure
 */
typedef struct
{
  const char *bandName;   // Band description
  uint8_t bandType;       // Band type (FM, MW or SW)
  uint16_t minimumFreq;   // Minimum frequency of the band
  uint16_t maximumFreq;   // maximum frequency of the band
  uint16_t currentFreq;   // Default frequency or current frequency
  int8_t currentStepIdx;  // Idex of tabStepAM:  Defeult frequency step (See tabStepAM)
  int8_t bandwidthIdx;    // Index of the table bandwidthFM, bandwidthAM or bandwidthSSB;
} Band;

/*
   Band table
   YOU CAN CONFIGURE YOUR OWN BAND PLAN. Be guided by the comments.
   To add a new band, all you have to do is insert a new line in the table below. No extra code will be needed.
   You can remove a band by deleting a line if you do not want a given band. 
   Also, you can change the parameters of the band.
   ATTENTION: You have to RESET the eeprom after adding or removing a line of this table. 
              Turn your receiver on with the encoder push button pressed at first time to RESET the eeprom content.  
*/
Band band[] = {
    {"VHF", FM_BAND_TYPE, 6400, 10800, 10390, 1, 0},
    {"MW1", MW_BAND_TYPE, 150, 1720, 810, 3, 4},
    {"MW2", MW_BAND_TYPE, 531, 1701, 783, 2, 4},
    {"MW2", MW_BAND_TYPE, 1700, 3500, 2500, 1, 4},
    {"80M", MW_BAND_TYPE, 3500, 4000, 3700, 0, 4},
    {"SW1", SW_BAND_TYPE, 4000, 5500, 4885, 1, 4},
    {"SW2", SW_BAND_TYPE, 5500, 6500, 6000, 1, 4},
    {"40M", SW_BAND_TYPE, 6500, 7300, 7100, 0, 4},
    {"SW3", SW_BAND_TYPE, 7200, 8000, 7200, 1, 4},
    {"SW4", SW_BAND_TYPE, 9000, 11000, 9500, 1, 4},
    {"SW5", SW_BAND_TYPE, 11100, 13000, 11900, 1, 4},
    {"SW6", SW_BAND_TYPE, 13000, 14000, 13500, 1, 4},
    {"20M", SW_BAND_TYPE, 14000, 15000, 14200, 0, 4},
    {"SW7", SW_BAND_TYPE, 15000, 17000, 15300, 1, 4},
    {"SW8", SW_BAND_TYPE, 17000, 18000, 17500, 1, 4},
    {"15M", SW_BAND_TYPE, 20000, 21400, 21100, 0, 4},
    {"SW9", SW_BAND_TYPE, 21400, 22800, 21500, 1, 4},
    {"CB ", SW_BAND_TYPE, 26000, 28000, 27500, 0, 4},
    {"10M", SW_BAND_TYPE, 28000, 30000, 28400, 0, 4},
    {"ALL", SW_BAND_TYPE, 150, 30000, 15000, 0, 4} // All band. LW, MW and SW (from 150kHz to 30MHz)
};                                             

const int lastBand = (sizeof band / sizeof(Band)) - 1;
int bandIdx = 0;
int tabStep[] = {1, 5, 10, 50, 100, 500, 1000};
const int lastStep = (sizeof tabStep / sizeof(int)) - 1;

char *rdsMsg;
char *stationName;
char *rdsTime;
char bufferStationName[50];
char bufferRdsMsg[100];
char bufferRdsTime[32];

uint8_t rssi = 0;
uint8_t snr = 0;
uint8_t volume = DEFAULT_VOLUME;

int XbatPos = 290;  // Position of battery icon
int YbatPos =   6;
int Xbatsiz =  20;  // size of battery icon
int Ybatsiz =   9;
int previousBatteryLevel = -1;
int currentBatteryLevel = 1;
bool batteryCharging = false;

// Devices class declarations
Rotary encoder = Rotary(ENCODER_PIN_A, ENCODER_PIN_B);

Battery18650Stats battery(VBAT_MON);

TFT_eSPI tft = TFT_eSPI();
TFT_eSprite spr = TFT_eSprite(&tft);

SI4735 rx;

void setup()
{

  pinMode(PIN_POWER_ON, OUTPUT);
  digitalWrite(PIN_POWER_ON, HIGH);

  // Encoder pins
  pinMode(ENCODER_PUSH_BUTTON, INPUT_PULLUP);
  
  pinMode(ENCODER_PIN_A, INPUT_PULLUP);
  pinMode(ENCODER_PIN_B, INPUT_PULLUP);

  // The line below may be necessary to setup I2C pins on ESP32
  Wire.begin(ESP32_I2C_SDA, ESP32_I2C_SCL);


  tft.begin();

  tft.setRotation(3);
  tft.fillScreen(TFT_BLACK);
  spr.createSprite(320,170);
  spr.setTextDatum(MC_DATUM);
  spr.setSwapBytes(true);
  spr.setFreeFont(&Orbitron_Light_24);
  spr.setTextColor(TFT_WHITE,TFT_BLACK);

  ledcSetup(0, 2000, 8);
  ledcAttachPin(PIN_LCD_BL, 0);
  ledcWrite(0, 255);

/*  // Splash - Remove or change it for your introduction text.
  display.clearDisplay();
  print(0, 0, NULL, 2, "PU2CLR");
  print(0, 15, NULL, 2, "ESP32");
  display.display();
  delay(2000);
  display.clearDisplay();
  print(0, 0, NULL, 2, "SI473X");
  print(0, 15, NULL, 2, "Arduino");
  display.display();
  // End Splash

  delay(2000);
  display.clearDisplay();
*/

  EEPROM.begin(EEPROM_SIZE);

  // If you want to reset the eeprom, keep the VOLUME_UP button pressed during statup
  if (digitalRead(ENCODER_PUSH_BUTTON) == LOW)
  {
    EEPROM.write(eeprom_address, 0);
    EEPROM.commit();
    tft.setTextSize(2);
    tft.setTextColor(TFT_RED, TFT_BLACK);
    tft.println("EEPROM RESETED");
    delay(3000);
    tft.fillScreen(TFT_BLACK);
  }

  // ICACHE_RAM_ATTR void rotaryEncoder(); see rotaryEncoder implementation below.
  attachInterrupt(digitalPinToInterrupt(ENCODER_PIN_A), rotaryEncoder, CHANGE);
  attachInterrupt(digitalPinToInterrupt(ENCODER_PIN_B), rotaryEncoder, CHANGE);

  rx.setI2CFastModeCustom(100000);
  
  int16_t si4735Addr = rx.getDeviceI2CAddress(RESET_PIN); // Looks for the I2C bus address and set it.  Returns 0 if error

  if ( si4735Addr == 0 ) {
    tft.setTextSize(2);
    tft.setTextColor(TFT_RED, TFT_BLACK);
    tft.println("Si4735 not detected");
    while (1);
  }  
  
  rx.setup(RESET_PIN, MW_BAND_TYPE);
  // Comment the line above and uncomment the three lines below if you are using external ref clock (active crystal or signal generator)
  // rx.setRefClock(32768);
  // rx.setRefClockPrescaler(1);   // will work with 32768  
  // rx.setup(RESET_PIN, 0, MW_BAND_TYPE, SI473X_ANALOG_AUDIO, XOSCEN_RCLK);

  rx.setAudioMuteMcuPin(AUDIO_MUTE);  
  
  cleanBfoRdsInfo();
  
  delay(300);


  // Checking the EEPROM content
  if (EEPROM.read(eeprom_address) == app_id)
  {
    readAllReceiverInformation();
  } else 
    rx.setVolume(volume);

  useBand();
  
  showStatus();
  drawSprite();
}


/**
 * Prints a given content on display 
 */
void print(uint8_t col, uint8_t lin, const GFXfont *font, uint8_t textSize, const char *msg) {
  tft.setCursor(col,lin);
  tft.setTextSize(textSize);
  tft.setTextColor(TFT_RED, TFT_BLACK);
  tft.println(msg);
}

void printParam(const char *msg) {
 tft.fillScreen(TFT_BLACK);
 print(0,10,NULL,2, msg);
 }

/*
   writes the conrrent receiver information into the eeprom.
   The EEPROM.update avoid write the same data in the same memory position. It will save unnecessary recording.
*/
void saveAllReceiverInformation()
{
  int addr_offset;

  EEPROM.begin(EEPROM_SIZE);

  EEPROM.write(eeprom_address, app_id);                 // stores the app id;
  EEPROM.write(eeprom_address + 1, rx.getVolume()); // stores the current Volume
  EEPROM.write(eeprom_address + 2, bandIdx);            // Stores the current band
  EEPROM.write(eeprom_address + 3, fmRDS);
  EEPROM.write(eeprom_address + 4, currentMode); // Stores the current Mode (FM / AM / SSB)
  EEPROM.write(eeprom_address + 5, currentBFO >> 8);
  EEPROM.write(eeprom_address + 6, currentBFO & 0XFF);
  EEPROM.commit();

  addr_offset = 7;
  band[bandIdx].currentFreq = currentFrequency;

  for (int i = 0; i <= lastBand; i++)
  {
    EEPROM.write(addr_offset++, (band[i].currentFreq >> 8));   // stores the current Frequency HIGH byte for the band
    EEPROM.write(addr_offset++, (band[i].currentFreq & 0xFF)); // stores the current Frequency LOW byte for the band
    EEPROM.write(addr_offset++, band[i].currentStepIdx);       // Stores current step of the band
    EEPROM.write(addr_offset++, band[i].bandwidthIdx);         // table index (direct position) of bandwidth
    EEPROM.commit();
  }

  EEPROM.end();
}

/**
 * reads the last receiver status from eeprom. 
 */
void readAllReceiverInformation()
{
  uint8_t volume;
  int addr_offset;
  int bwIdx;
  EEPROM.begin(EEPROM_SIZE);

  volume = EEPROM.read(eeprom_address + 1); // Gets the stored volume;
  bandIdx = EEPROM.read(eeprom_address + 2);
  fmRDS = EEPROM.read(eeprom_address + 3);
  currentMode = EEPROM.read(eeprom_address + 4);
  currentBFO = EEPROM.read(eeprom_address + 5) << 8;
  currentBFO |= EEPROM.read(eeprom_address + 6);

  addr_offset = 7;
  for (int i = 0; i <= lastBand; i++)
  {
    band[i].currentFreq = EEPROM.read(addr_offset++) << 8;
    band[i].currentFreq |= EEPROM.read(addr_offset++);
    band[i].currentStepIdx = EEPROM.read(addr_offset++);
    band[i].bandwidthIdx = EEPROM.read(addr_offset++);
  }

  EEPROM.end();

  currentFrequency = band[bandIdx].currentFreq;

  if (band[bandIdx].bandType == FM_BAND_TYPE)
  {
    currentStepIdx = idxFmStep = band[bandIdx].currentStepIdx;
    rx.setFrequencyStep(tabFmStep[currentStepIdx]);
  }
  else
  {
    currentStepIdx = idxAmStep = band[bandIdx].currentStepIdx;
    rx.setFrequencyStep(tabAmStep[currentStepIdx]);
  }

  bwIdx = band[bandIdx].bandwidthIdx;

  if (currentMode == LSB || currentMode == USB)
  {
    loadSSB();
    bwIdxSSB = (bwIdx > 5) ? 5 : bwIdx;
    rx.setSSBAudioBandwidth(bandwidthSSB[bwIdxSSB].idx);
    // If audio bandwidth selected is about 2 kHz or below, it is recommended to set Sideband Cutoff Filter to 0.
    if (bandwidthSSB[bwIdxSSB].idx == 0 || bandwidthSSB[bwIdxSSB].idx == 4 || bandwidthSSB[bwIdxSSB].idx == 5)
      rx.setSSBSidebandCutoffFilter(0);
    else
      rx.setSSBSidebandCutoffFilter(1);
    rx.setSSBBfo(currentBFO);      
  }
  else if (currentMode == AM)
  {
    bwIdxAM = bwIdx;
    rx.setBandwidth(bandwidthAM[bwIdxAM].idx, 1);
  }
  else
  {
    bwIdxFM = bwIdx;
    rx.setFmBandwidth(bandwidthFM[bwIdxFM].idx);
  }

  if (currentBFO > 0)
    sprintf(bfo, "+%4.4d", currentBFO);
  else
    sprintf(bfo, "%4.4d", currentBFO);

  delay(50);
  rx.setVolume(volume);
}

/*
 * To store any change into the EEPROM, it is needed at least STORE_TIME  milliseconds of inactivity.
 */
void resetEepromDelay()
{
  elapsedCommand = storeTime = millis();
  itIsTimeToSave = true;
}

/**
    Set all command flags to false
    When all flags are disabled (false), the encoder controls the frequency
*/
void disableCommands()
{
  cmdBand = false;
  bfoOn = false;
  cmdVolume = false;
  cmdAgc = false;
  cmdBandwidth = false;
  cmdStep = false;
  cmdMode = false;
  cmdMenu = false;
  cmdSoftMuteMaxAtt = false;
  countClick = 0;
  // showCommandStatus((char *) "VFO ");
}
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
void loop()
{

  batteryMonitor(false);  // Battery check

  // Check if the encoder has moved.
  if (encoderCount != 0)
  {
    if (bfoOn & (currentMode == LSB || currentMode == USB))
    {
      currentBFO = (encoderCount == 1) ? (currentBFO + currentBFOStep) : (currentBFO - currentBFOStep);
      rx.setSSBBfo(currentBFO);
      showBFO();
    }
    else if (cmdMenu)
      doMenu(encoderCount);
    else if (cmdMode)
      doMode(encoderCount);
    else if (cmdStep)
      doStep(encoderCount);
    else if (cmdAgc)
      doAgc(encoderCount);
    else if (cmdBandwidth)
      doBandwidth(encoderCount);
    else if (cmdVolume)
      doVolume(encoderCount);
    else if (cmdSoftMuteMaxAtt)
      doSoftMute(encoderCount);
    else if (cmdBand)
      setBand(encoderCount);
    else
    {
      if (encoderCount == 1)
      {
        rx.frequencyUp();
      }
      else
      {
        rx.frequencyDown();
      }
      if (currentMode == FM) cleanBfoRdsInfo();
      // Show the current frequency only if it has changed
      currentFrequency = rx.getFrequency();
      showFrequency();
    }
    encoderCount = 0;
    resetEepromDelay();
    delay(MIN_ELAPSED_TIME);
    elapsedCommand = millis();
  }
  else
  {
    if (digitalRead(ENCODER_PUSH_BUTTON) == LOW)
    {
       uint32_t timestamp = millis() + 3000;
        while (digitalRead(ENCODER_PUSH_BUTTON) == LOW ) { 
          if( millis() > timestamp){
            tft.fillScreen(TFT_BLACK);
            tft.setTextSize(2);
            tft.setTextColor(TFT_WHITE, TFT_BLACK);
            tft.setTextDatum(MC_DATUM);
            tft.setCursor(tft.width()/2,tft.height()/2);
            tft.println("SLEEP");
            delay(3000);
            digitalWrite(PIN_POWER_ON, 0);
            esp_sleep_enable_ext0_wakeup((gpio_num_t)ENCODER_PUSH_BUTTON, 0);
            esp_deep_sleep_start();
          }
      }
      timestamp = 0;
      countClick++;
      if (cmdMenu)
      {
        currentMenuCmd = menuIdx;
        doCurrentMenuCmd();
      }
      else if (countClick == 1)
      { // If just one click, you can select the band by rotating the encoder
        if (isMenuMode())
        {
          disableCommands();
          showStatus();
          showCommandStatus((char *)"VFO ");
        }
        else if (bfoOn) {
          bfoOn = false;
          showStatus();
        }
        else
        {
          cmdBand = !cmdBand;
          // cmdMenu = !cmdMenu;
          menuIdx=BAND;          
          currentMenuCmd = menuIdx;
          drawSprite();
        }
      }
      else
      { // GO to MENU if more than one click in less than 1/2 seconds.
        cmdMenu = !cmdMenu;
        if (cmdMenu)
          showMenu();
      }
      delay(MIN_ELAPSED_TIME);
      elapsedCommand = millis();
    }
  }

  // Show RSSI status only if this condition has changed
  if ((millis() - elapsedRSSI) > MIN_ELAPSED_RSSI_TIME * 6)
  {
    rx.getCurrentReceivedSignalQuality();
    snr= rx.getCurrentSNR();
    int aux = rx.getCurrentRSSI();
    if (rssi != aux && !isMenuMode())
    {
      rssi = aux;
      showRSSI();
    }
    elapsedRSSI = millis();
  }

  // Disable commands control
  if ((millis() - elapsedCommand) > ELAPSED_COMMAND)
  {
    if ((currentMode == LSB || currentMode == USB) )
    {
      bfoOn = false;
      // showBFO();
      disableCommands();
      showStatus();
    } else if (isMenuMode() or cmdBand) {
      disableCommands();
      showStatus();
    } 
    elapsedCommand = millis();
  }

  if ((millis() - elapsedClick) > ELAPSED_CLICK)
  {
    countClick = 0;
    elapsedClick = millis();
  }

  if ((millis() - lastRDSCheck) > RDS_CHECK_TIME) {
    if ((currentMode == FM) and (snr >= 12)) checkRDS();
    lastRDSCheck = millis();
  }  

  // Show the current frequency only if it has changed
  if (itIsTimeToSave)
  {
    if ((millis() - storeTime) > STORE_TIME)
    {
      saveAllReceiverInformation();
      storeTime = millis();
      itIsTimeToSave = false;
    }
  }

  delay(5);
}

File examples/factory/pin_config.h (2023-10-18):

#pragma once

/*DEBUG*/
#define WIFI_SSID             "xinyuandianzi"
#define WIFI_PASSWORD         "AA15994823428"

// #define WIFI_SSID             "Your-ssid"
// #define WIFI_PASSWORD         "Your-password"

#define WIFI_CONNECT_WAIT_MAX (30 * 1000)

#define NTP_SERVER1           "pool.ntp.org"
#define NTP_SERVER2           "time.nist.gov"
#define GMT_OFFSET_SEC        (3600 * 8)
#define DAY_LIGHT_OFFSET_SEC  0

#define LV_SCREEN_WIDTH       320
#define LV_SCREEN_HEIGHT      170
#define LV_BUF_SIZE           (LV_SCREEN_WIDTH * LV_SCREEN_HEIGHT)
/*ESP32S3*/
#define PIN_POWER_ON          46

#define PIN_IIC_SDA           18
#define PIN_IIC_SCL           8

#define PIN_APA102_CLK        45
#define PIN_APA102_DI         42

#define PIN_ENCODE_A          2
#define PIN_ENCODE_B          1
#define PIN_ENCODE_BTN        0

#define PIN_LCD_BL            15
#define PIN_LCD_DC            13
#define PIN_LCD_CS            10
#define PIN_LCD_CLK           12
#define PIN_LCD_MOSI          11
#define PIN_LCD_RES           9

#define PIN_BAT_VOLT          4

#define PIN_IIS_BCLK          7
#define PIN_IIS_WCLK          5
#define PIN_IIS_DOUT          6

#define PIN_ES7210_BCLK       47
#define PIN_ES7210_LRCK       21
#define PIN_ES7210_DIN        14
#define PIN_ES7210_MCLK       48

#define PIN_SD_CS             39
#define PIN_SD_SCK            40
#define PIN_SD_MOSI           41
#define PIN_SD_MISO           38

#define RADIO_CS_PIN          17
#define RADIO_SW1_PIN         43
#define RADIO_SW0_PIN         44
#define NFC_CS                16

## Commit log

2022-10-28 shell upload
    [t-embed_nomal-shell.stl, t-embed_normal-shell.stp, t_embed_big-shell-f.stl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]
2022-11-03 Upload schematic
    closed #3
2022-11-05 PVC file upload
    [PVC_Board.dwg]
2023-02-14 Added full shell
    [t-embed_normal-full-shell.stp]
2023-02-17 Added front panel
    [front-panel.stl]
2023-03-18 Factory program adaptation to Arduino IDE
2023-05-26 Added boards
2023-10-18 remove boards
2023-10-18 Update sound example https://github.com/Xinyuan-LilyGO/T-Embed/issues/29
    [sound.ino]
2023-10-18 Fix Arduinio IDE 2.0.14 compilation error
    [app_nfc.cpp, app_radio.cpp, es7210.cpp]
2024-11-13 Added shell https://github.com/Xinyuan-LilyGO/T-Embed/issues/39
    [t-embed_Thin.stp]
2024-12-04 Added shell
    [t-embed_normal-shell-1204.stp]
2024-12-18 Added bottom case https://github.com/Xinyuan-LilyGO/T-Embed/issues/41
    [t-embed_bottom.stp, t-embed_normal-shell.stl]
2025-05-06 Updated sound example https://github.com/Xinyuan-LilyGO/T-Embed/issues/46
    [sound.ino]
2026-04-23 fix self test mode mic invalid
    [factory.ino]
